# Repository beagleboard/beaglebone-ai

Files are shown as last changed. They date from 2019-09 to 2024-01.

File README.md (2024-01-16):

# BeagleBoard.org BeagleBone AI
_Fast track to Embedded Artificial Intelligence_

[BeagleBone AI](https://www.beagleboard.org/boards/beaglebone-ai) is built on the proven BeagleBoard.org® open source Linux approach, BeagleBone® AI has the form-factor of a miniature single-board computer (SBC) with the power of a full-on industrial computer workhorse. Based on the Texas Instruments AM5729, developers have access to the powerful SoC with the ease of BeagleBone® Black header and mechanical compatibility. BeagleBone® AI makes it easy to explore how artificial intelligence (AI) can be used in everyday life via the TI C66x digital-signal-processor (DSP) cores and embedded-vision-engine (EVE) cores supported through an optimized TIDL machine learning OpenCL API with pre-installed tools. Focused on everyday automation in industrial, commercial and home applications.

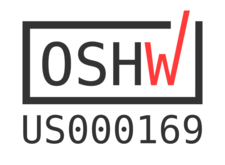
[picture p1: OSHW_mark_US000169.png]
(https://certification.oshwa.org/us000169.html)


# Terms
These design materials are *NOT SUPPORTED* and *DO NOT* constitute a reference design. Only “community” support is allowed via resources at [BeagleBoard.org/discuss](https://beagleboard.org/discuss).

THERE IS NO WARRANTY FOR THE DESIGN MATERIALS, TO THE EXTENT PERMITTED BY APPLICABLE LAW. EXCEPT WHEN OTHERWISE STATED IN WRITING THE COPYRIGHT HOLDERS AND/OR OTHER PARTIES PROVIDE THE DESIGN MATERIALS “AS IS” WITHOUT WARRANTY OF ANY KIND, EITHER EXPRESSED OR IMPLIED, INCLUDING, BUT NOT LIMITED TO, THE IMPLIED WARRANTIES OF MERCHANTABILITY AND FITNESS FOR A PARTICULAR PURPOSE. THE ENTIRE RISK AS TO THE QUALITY AND PERFORMANCE OF THE DESIGN MATERIALS IS WITH YOU. SHOULD THE DESIGN MATERIALS PROVE DEFECTIVE, YOU ASSUME THE COST OF ALL NECESSARY SERVICING, REPAIR OR CORRECTION.

In other words, you may use the design materials as you choose and there is no license with regards to usage in the manufacturing process. We mean it, these design materials may be totally unsuitable for any purposes. Don't blame us!

As a general rule, we don't encourage use of this or other off-the-shelf single board computers in commercial products without engaging with a manufacturer to create a supplier agreement and make sure that you can get material as your business demands. Further, we do update the design on occasions where we find it necessary and won't guarantee a supply of older revisions, though we do seek periodic manufacturing of all of our boards for a period of roughly 10 years and will make design changes to replace obsolete parts and that may impact your usage. If you do opt to use it in a product, you take full responsibility for that product.

Do not use the BeagleBoard.org logo or trademarks (such as BeagleBoard, BeagleBone and PocketBeagle) on your products without a [logo license](https://beagleboard.org/logo) from the BeagleBoard.org Foundation, but feel free to reference BeagleBoard.org.

See the [LICENSE](https://github.com/beagleboard/beaglebone-ai/blob/master/LICENSE) file regarding the copyright of these materials.

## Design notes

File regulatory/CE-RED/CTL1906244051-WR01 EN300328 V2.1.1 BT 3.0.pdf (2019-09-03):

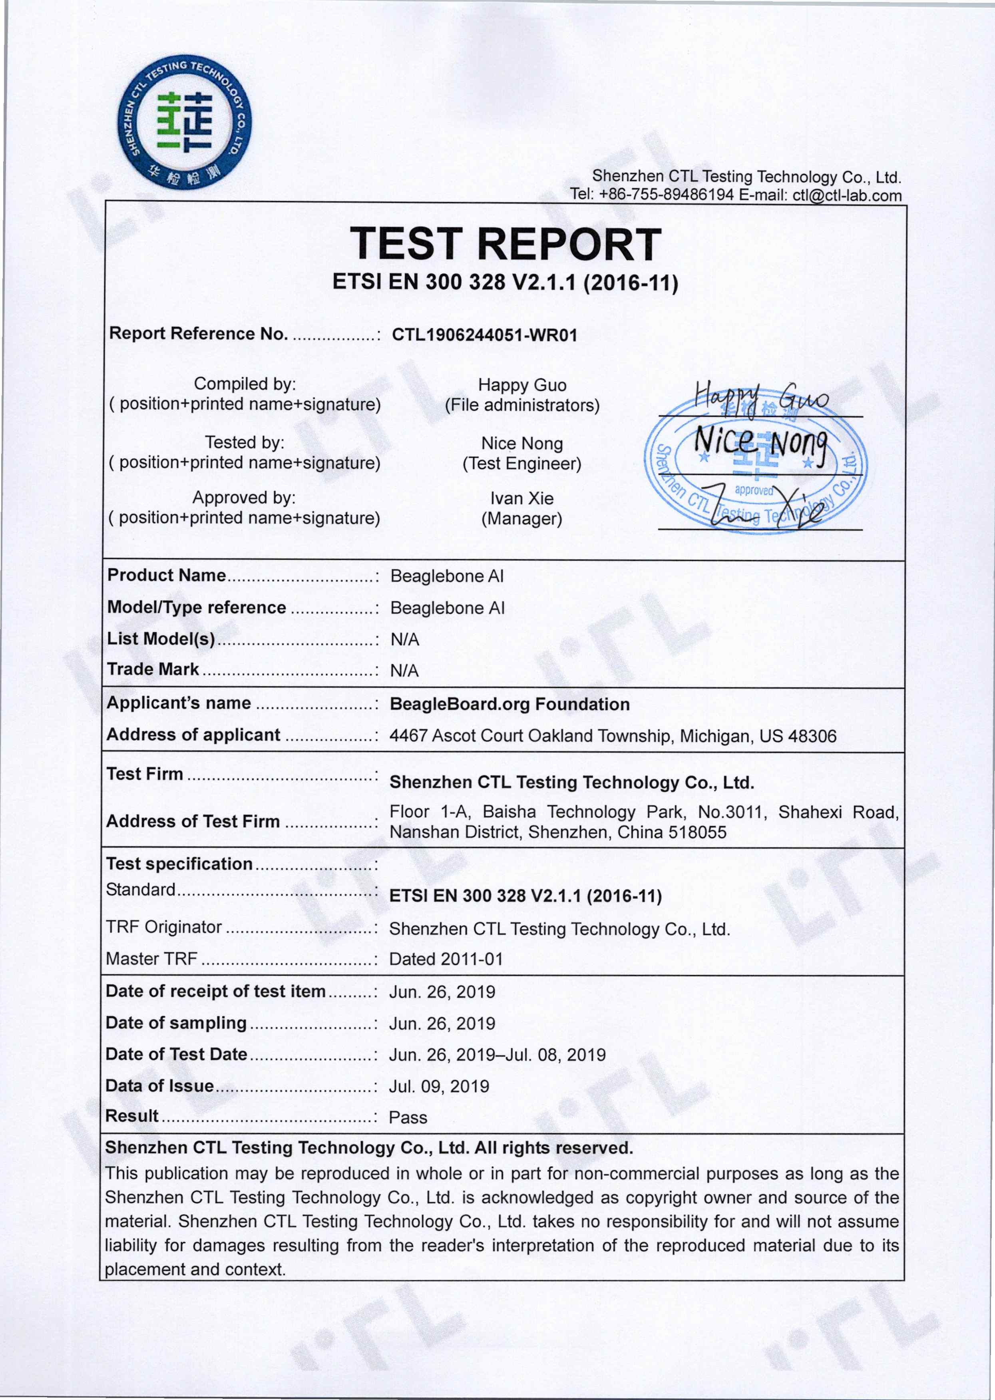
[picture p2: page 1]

V1.0 | Page 2 of 49 | Report No.: CTL1906244051-WR01

# TEST REPORT

Test Report No. : | CTL1906244051-WR01 | Jul. 09, 2019
Date of issue
Equipment under Test | : | Beaglebone AI
Model /Type | : | Beaglebone AI
Listed Models | : | N/A
Applicant | : | BeagleBoard.org Foundation
Address | : | 4467 Ascot Court Oakland Township, Michigan, US
48306
Manufacturer | : | Embest Technology Co., Ltd
Address | : | Tower B 4/F, Shanghai Building, Nanshan Yungu
Innovation Industry Park, Liuxian Ave. No.1183, Taoyuan St., Nanshan District, Shenzhen, Chinas.
Test result | Pass *

* In the configuration tested, the EUT complied with the standards specified page 5.

The test results presented in this report relate only to the object tested.
This report shall not be reproduced, except in full, without the written approval of the issuing testing laboratory.

V1.0 | Page 3 of 49 | Report No.: CTL1906244051-WR01

### ** Modified History **

Revision | Description | Issued Data | Report No. | Remark
Version 1.0 | Initial Test Report Release | 2019-07-08 | CTL1906244051-WR01 | Tracy Qi

V1.0 | Page 4 of 49 | Report No.: CTL1906244051-WR01

## Contents

V1.0 | Page 5 of 49 | Report No.: CTL1906244051-WR01

## 1 TEST SUMMARY

### 1.1 Test Standards

The tests were performed according to following standards:

ETSI EN 300 328 V2.1.1 (2016-11)–Wideband transmission systems; Data transmission equipment operating in the 2,4 GHz ISM band and using wide band modulation techniques; Harmonised Standard covering the essential requirements of article 3.2 of the Directive 2014/53/EU

### 1.2 Test Description

Item | Reference | Result
Maximum transmit power | ETSI EN 300 328 (V2.1.1) Sub-clause 4.3.1.2 | PASS
Duty Cycle, Tx-sequence, Tx-gap | ETSI EN 300 328 (V2.1.1) Sub-clause 4.3.1.3 | N/Anote1
Dwell time, Minimum Frequency Occupation and Hopping Sequence | ETSI EN 300 328 (V2.1.1) Sub-clause 4.3.1.4 | PASS
Hopping Frequency Separation | ETSI EN 300 328 (V2.1.1) Sub-clause 4.3.1.5 | PASS
Medium Utilisation (MU) factor | ETSI EN 300 328 (V2.1.1) Sub-clause 4.3.1.6 | N/Anote1
Adaptively | ETSI EN 300 328 (V2.1.1) Sub-clause 4.3.1.7 | N/Anote2
Occupied Channel Bandwidth | ETSI EN 300 328 (V2.1.1) Sub-clause 4.3.1.8 | PASS
Transmitter unwanted emissions in the out-of-band domain | ETSI EN 300 328 (V2.1.1) Sub-clause 4.3.1.9 | PASS
Transmitter unwanted emissions in the spurious domain | ETSI EN 300 328 (V2.1.1) Sub-clause 4.3.1.10 | PASS
Receiver spurious emissions | ETSI EN 300 328 (V2.1.1) Sub-clause 4.3.1.11 | PASS
Receiver Blocking | ETSI EN 300 328 (V2.1.1) Sub-clause 4.3.1.12 | PASS
Geo-location capability | ETSI EN 300 328 (V2.1.1) Sub-clause 4.3.1.13 | N/Anote3
Note1: This requirement does not apply to adaptive equipment.
Note2: Which is not applicable to device with a maximum RF Output power level is less than 10 dBm e.i.r.p.
Note3: This equipment without geo-location capability function.

V1.0 | Page 6 of 49 | Report No.: CTL1906244051-WR01

### 1.3 Test Facility

### 1.3.1 Address of the test laboratory

Shenzhen CTL Testing Technology Co., Ltd.
Floor 1-A, Baisha Technology Park, No. 3011, Shahexi Road, Nanshan, Shenzhen 518055 China

There is one 3m semi-anechoic chamber and two line conducted labs for final test. The Test Sites meet the requirements in documents ANSI C63.4 and CISPR 32/EN 55032 requirements.

### 1.3.2 Laboratory accreditation

The test facility is recognized, certified, or accredited by the following organizations:
CNAS-Lab Code: L7497
Shenzhen CTL Testing Technology Co., Ltd. has been assessed and proved to be in compliance with CNAS-CL01 Accreditation Criteria for Testing and Calibration Laboratories (identical to ISO/IEC 17025: 2005 General Requirements) for the Competence of Testing and Calibration Laboratories.
A2LA-Lab Cert. No. 4343.01
Shenzhen CTL Testing Technology Co., Ltd. EMC Laboratory has been accredited by A2LA for technical competence in the field of electrical testing, and proved to be in compliance with ISO/IEC 17025: 2005 General Requirements for the Competence of Testing and Calibration Laboratories and any additional program requirements in the identified field of testing.
IC Registration No.: 9518B
CAB identifier: CN0041
The 3m alternate test site of Shenzhen CTL Testing Technology Co., Ltd. EMC Laboratory has been registered by Innovation, Science and Economic Development Canada to test to Canadian radio equipment requirements with Registration No.: 9518B on Jan. 22, 2019.
FCC-Registration No.: 399832
Designation No.: CN1216
Shenzhen CTL Testing Technology Co., Ltd. EMC Laboratory has been registered and fully described in a report filed with the (FCC) Federal Communications Commission. The acceptance letter from the FCC is maintained in our files. Registration 399832, December 08, 2017.

### 1.4 Statement of the measurement uncertainty

The data and results referenced in this document are true and accurate. The reader is cautioned that there may be errors within the calibration limits of the equipment and facilities. The measurement uncertainty was calculated for all measurements listed in this test report acc. to CISPR 16 - 4 „Specification for radio disturbance and immunity measuring apparatus and methods – Part 4: Uncertainty in EMC Measurements“ and is documented in the Shenzhen CTL Testing Technology Co., Ltd. quality system acc. to DIN EN ISO/IEC 17025. Furthermore, component and process variability of devices similar to that tested may result in additional deviation. The manufacturer has the sole responsibility of continued compliance of the device.
Hereafter the best measurement capability for CTL laboratory is reported:
Test Items | Measurement Uncertainty | Notes
Occupied Channel Bandwidth | ±2% | (1)
Transmitter power conducted | 0.57 dB | (1)
Transmitter power Radiated | 2.20 dB | (1)
Conducted spurious emission | 1.60 dB | (1)
Radiated spurious emission | 2.20 dB | (1)
Temperature | ±1℃ | (1)

V1.0 | Page 7 of 49 | Report No.: CTL1906244051-WR01
Humidity | ±3% | (1)
DC and low frequency voltages | ±1.5% | (1)
Time | ±2% | (1)
Duty cycle | ±2% | (1)
Note 1: This uncertainty represents an expanded uncertainty expressed at approximately the 95% confidence level using a coverage factor of k=1.96.

V1.0 | Page 8 of 49 | Report No.: CTL1906244051-WR01

## 2 GENERAL INFORMATION

### 2.1 Environmental conditions

During the measurement the environmental conditions were within the listed ranges:
Temperature | Normal Temperature: | 25°C
| High Temperature: | 55°C
| Low Temperature: | -20°C
Voltage | Normal Voltage | 5.00V
| High Voltage | 5.75V
| Low Voltage | 4.25V
Other | Relative Humidity | 55 %
| Air Pressure | 101 kPa

### 2.2 General Description of EUT

Product Name: | Beaglebone AI
Model/Type reference: | Beaglebone AI
Power supply: | DC 5.0V
Bluetooth
Supported type: | Bluetooth BR/EDR
Modulation: | GFSK, π/4DQPSK, 8DPSK
Operation frequency: | 2402MHz~2480MHz
Channel number: | 79
Channel separation: | 1MHz
Antenna type: | Internal Antenna
Antenna gain: | 1.5dBi
Note: For more detailed features description, please refer to the manufacturer’s specifications or the User's Manual.

### 2.3 Receiver categories

This device belongs to the receiver categories as the choice box selected:
Categorization | Note
Receiver category 1 | Adaptive equipment with a maximum RF output power greater than 10 dBm e.i.r.p.
Receiver category 2 | Non-adaptive equipment with a Medium Utilization (MU) factor greater than 1 % and less than or equal to 10 % or adaptive equipment with a maximum RF output power of 10 dBm e.i.r.p.
Receiver category 3 | Non-adaptive equipment with a maximum Medium Utilization (MU) factor of 1 % or adaptive equipment with a maximum RF output power of 0 dBm e.i.r.p.

V1.0 | Page 9 of 49 | Report No.: CTL1906244051-WR01

### 2.4 Description of Test Modes and Test Frequency

The EUT has been tested under typical operating condition. The Applicant provides communication tools software to control the EUT for staying in continuous transmitting and receiving mode for testing. Operation Frequency List：
Channel | Frequency (MHz)
00 2402
01 | 2403 ... ...
38 | 2440
39 2441
40 | 2442 ... ...
77 | 2479
78 2480
Note: The line display in grey were the channel selected for testing

### 2.5 Measurement Instruments List

RF output power & PSD & OOB & OBW & Hoping & Duty Cycle, Tx-sequence, Tx-gap & Adaptively
Item | Test Equipment | Manufacturer | Model No. | Serial No. | Calibration Date | Calibration Due Date
1 | Spectrum Analyzer | Agilent | N9020 | US46220290 | 2019/05/24 | 2020/05/23
2 | Signal Generator | Agilent | N5182A | MY47420864 | 2019/05/24 | 2020/05/23
3 | Signal Generator | Agilent | E4421B | US40051744 | 2019/05/24 | 2020/05/23
4 | Power Sensor | Agilent | U2021XA | MY5365004 | 2019/05/24 | 2020/05/23
5 | Power Meter | Agilent | U2531A | TW53323507 | 2019/05/24 | 2020/05/23
6 | Climate Chamber | ESPEC | EL-10KA | A20120523 | 2019/05/24 | 2020/05/23

Transmitter spurious emissions & Receiver spurious emissions
Item | Test Equipment | Manufacturer | Model No. | Serial No. | Calibration Date | Calibration Due Date
1 | ULTRA-ROADBA ND ANTENNA | Sunol Sciences Corp. | JB1 | A061713 | 2019/05/24 | 2020/05/23
2 | Horn Antenna | Sunol Sciences Corp. | DRH-118 | A062013 | 2019/05/24 | 2020/05/23
3 | EMI Test Receiver | R&S | ESCI | 103710 | 2019/05/24 | 2020/05/23
4 | Controller | EM Electronics | Controller EM 1000 | N/A | 2019/05/24 | 2020/05/23
5 | Amplifier | Agilent | 8349B | 3008A02306 | 2019/05/24 | 2020/05/23
6 | Amplifier | Agilent | 8447D | 2944A10176 | 2019/05/24 | 2020/05/23
7 | Temperature/Hu midity Meter | Gangxing | CTH-608 | 02 | 2019/05/24 | 2020/05/23
8 | High-Pass Filter | K&L | 9SH10-27 | N/A | 2019/05/24 | 2020/05/23

V1.0 | Page 10 of 49 | Report No.: CTL1906244051-WR01
| | | 00/X1275 0-O/O
9 | High-Pass Filter | K&L | 41H10-13 75/U1275 0-O/O | N/A | 2019/05/24 | 2020/05/23
10 | RF Cable | HUBER+SU HNER | RG214 | N/A | 2019/05/24 | 2020/05/23

The calibration interval is 1 year.

V1.0 | Page 11 of 49 | Report No.: CTL1906244051-WR01

## 3 TEST ITEM AND RESULTS

### 3.1 RF Output Power

Limit

ETSI EN 300 328 (V2.1.1) Sub-clause 4.3.1.2.3
TEST CONDITION | LIMIT
Normal and Extreme | 20dBm(e.i.r.p)

Test Procedure

- Step 1: Use a fast power sensor suitable for 2,4 GHz and capable of minimum 1 MS/s. Use the following settings:
- Sample speed 1 MS/s or faster.
- The samples shall represent the RMS power of the signal.
- Measurement duration: For non-adaptive equipment: equal to the observation period. For adaptive equipment, the measurement duration shall be long enough to ensure a minimum number of bursts (at least 10) are captured.
NOTE 1: For adaptive equipment, to increase the measurement accuracy, a higher number of bursts may be used.
- Step 2:For conducted measurements on devices with one transmit chain:
-Connect the power sensor to the transmit port, sample the transmit signal and store the raw data. Use these stored samples in all following steps.
For conducted measurements on devices with multiple transmit chains:
- Connect one power sensor to each transmit port for a synchronous measurement on all transmits ports.
- Trigger the power sensors so that they start sampling at the same time. Make sure the time difference between the samples of all sensors is less than 500 ns.
- For each individual sampling point (time domain), sum the coincident power samples of all ports and store them. Use these summed samples in all following steps.
- Step 3: Find the start and stop times of each burst in the stored measurement samples.
The start and stop times are defined as the points where the power is at least 30 dB below the highest value of the stored samples in step 2.
NOTE 2: In case of insufficient dynamic range, the value of 30 dB may need to be reduced appropriately.
- Step 4: Between the start and stop times of each individual burst calculate the RMS power over the burst using the formula below. Save these Pburst values, as well as the start and stop times for each burst.

With 'k' being the total number of samples and 'n' the actual sample number
- Step 5: The highest of all Pburst values (value "A" in dBm) will be used for maximum e.i.r.p. calculations.
- Step 6: Add the (stated) antenna assembly gain "G" in dBi of the individual antenna. If applicable, add the additional beamforming gain "Y" in dB using the formula below:
P = A + G + Y

V1.0 | Page 12 of 49 | Report No.: CTL1906244051-WR01

Test Results

GFSK Modulation
Test conditions | Measured power (dBm) | Antenna Gain (dBi) | EIRP (dBm) | Limit
(V) | Temperature (℃ )
5.0V | 25 | 7.67 | 1.50 | 9.17 | 20.00 | Pass
| -20 | 7.42 | 1.50 | 8.92
| +55 | 7.38 | 1.50 | 8.88
(dBm) | Result Voltage

π/4DQPSK Modulation
Test conditions | Measured power (dBm) | Antenna Gain (dBi) | EIRP (dBm) | Limit
(V) | Temperature (℃ )
5.0V | 25 | 3.51 | 1.50 | 5.01 | 20.00 | Pass
| -20 | 3.46 | 1.50 | 4.96
| +55 | 3.57 | 1.50 | 5.07
(dBm) | Result Voltage

8DPSK Modulation
Test conditions | Measured power (dBm) | Antenna Gain (dBi) | EIRP (dBm) | Limit
(V) | Temperature (℃ )
5.0V | 25 | 3.81 | 1.50 | 5.31 | 20.00 | Pass
| -20 | 3.72 | 1.50 | 5.22
| +55 | 3.98 | 1.50 | 5.48
(dBm) | Result Voltage

Note 1. Test performed at worst case at DH5, 2DH5, 3DH5 hoping mode separately.
2. We captured 25 bursts for each mode and recorded the maximum average power.
3. Measured Power includes the cable loss.

V1.0 | Page 13 of 49 | Report No.: CTL1906244051-WR01

### 3.2 Duty Cycle, Tx-sequence, Tx-gap

Limit

ETSI EN 300 328 (V2.1.1) Sub-clause 4.3.1.3.3

1. For non-adaptive FHSS equipment, the Duty Cycle shall be equal to or less than the maximum value declared by the supplier. In addition, the maximum Tx -sequence time shall be 5 ms while the minimum Tx-gap time shall be 5 ms.
2. For equipment using wide band modulations other than FHSS, the Duty Cycle shall be equal to or less than the maximum value declared by the supplier.
The Tx-sequence time shall be equal to or less than 10 ms. The minimum Tx-gap time following a Tx-sequence shall be equal to the duration of that proceeding Tx-sequence with a minimum of 3,5 ms.
Test Procedure

The test procedure, which shall only be performed for non-adaptive systems, shall be as follows:
- Step 1: Use the same stored measurement samples from the procedure described in RF output power measurement
- Step 2: Between the saved start and stop times of each individual burst, calculate the TxOn time. Save these TxOn values.
- Step 3: Al TxOn times between the end of the first gap (which is the start of the first burst within the observation period) and the start of the last burst (within this observation period) divided by the observation period.
- Step 4:
Identify any TxOff time that is equal to or greater than the minimum Tx-gap time. These are the potential valid gap times to be further considered in this procedure.
Starting from the second identified gap, calculate the time from the start of this gap to the end of the preceding ap. This time is the Tx-sequence time for this transmission. Repeat this procedure until the last identified gap ithin the observation period is reached.

Test Results

Not applicable to this device which was adaptive equipment and cannot operate in a non-adaptive mode.

V1.0 | Page 14 of 49 | Report No.: CTL1906244051-WR01

### 3.3 Accumulated Transmit Time, Frequency Occupation and Hopping Sequence

LIMIT

ETSI EN 300 328 (V2.1.1) Sub-clause 4.3.1.4.3.
Limit of Accumulated Transmit Time
TEST CONDITION | LIMIT
Non-adaptive frequency hopping systems | ≥15 ms within 5ms*hopping frequencies (N)
Adaptive frequency hopping systems | ≥0.4s within 0.4s*hopping frequencies (N)
Note: N means minimum number of hopping frequencies (N) that have to be used.

Limit of Minimum Frequency Occupation
TEST CONDITION | LIMIT
Non-adaptive frequency hopping systems Adaptive frequency hopping systems | Option 1: Each hopping frequency of the hopping sequence shall be occupied at least once within a period not exceeding four times the product of the dwell time and the number of hopping frequencies in use. Option 2: The occupation probability for each frequency shall be between ((1 / U) × 25 %) and 77 % where U is the number of hopping frequencies in use.

Hopping Sequence
TEST CONDITION | LIMIT
Non-adaptive frequency hopping systems Adaptive frequency hopping systems | The hopping sequence(s) shall contain at least N hopping frequencies at all times, where N is 15 or 15 divided by the minimum Hopping Frequency Separation in MHz, whichever is the greater. Adaptive Frequency Hopping equipment shall be capable of operating over a minimum of 70 % of the authorized band.

Remark: This test item is not applicable to DSSS/OFDM system device.
Test Procedure
1. The measurement shall be performed on a minimum of 2 hopping frequencies chosen arbitrary from the actual hopping sequence. The results as well as the frequencies on which the test was performed shall be recorded in the test report.
2. The analyzer shall be set as follows:
Centre Frequency: | Equal to the hopping frequency being investigated
Frequency Span: | 0 Hz
RBW: | ~ 50 % of the Occupied Channel Bandwidth
VBW: | ≥ RBW
Detector Mode: | RMS
Sweep time: | 400 ms × Minimum number of hopping frequencies (N)
Number of sweep points: | 30 000
Trace mode: | Clear / Write
Trigger: | Free Run

V1.0 | Page 15 of 49 | Report No.: CTL1906244051-WR01
3. Indentify the data points related to the frequency being investigated by applying a threshold.
4. Count the number of data points identified as resulting from transmissions on the frequency being investigated and multiply this number by the time difference between two consecutive data points.
5. Record this value as Accumulated Transmit Time in test report.
6. Set Sweep time to 4 × Dwell Time × Actual numbers of hopping frequencies in use and repeat 3 and 4 to get Frequency Occupation Time and Number.
7. Make the following changes on the analyzer for Hopping Sequence measurement
Centre Frequency: | Equal to the hopping frequency being investigated
Start Frequency: | 2 400 MHz
Stop Frequency: | 2 483,5 MHz
RBW: | ~ 50 % of the Occupied Channel Bandwidth (single hop)
VBW: | ≥ RBW
Detector Mode: | RMS
Sweep time: | 1 s
Number of sweep points: | 30 000
Trace mode: | Max Hold
Trigger: | Free Run
8. When the trace has completed, indentify the number of hopping frequencies used by the hopping sequence.
9. For adaptive systems, using the lowest and highest -20 dB points from the total spectrum envelope obtained instep 7, it shall be verified whether the system uses 70 % of the authorized band. The result shall be recorded in the test report.
Test Results

Test performed at all modulation type and recorded worst case at DH5, 2DH5, and 3DH5.

V1.0 | Page 16 of 49 | Report No.: CTL1906244051-WR01
- Accumulated Transmit Time
The test period: T= 0.4s*hopping frequencies (N)=0.4*15=6s
Channel | Modulation | Accumulated Transmit Time (ms) | Limit (ms) | Result
CH00 | GFSK | 53.800 | 400 | Pass
| π/4QPSK | 50.800 | 400 | Pass
| 8DPSK | 59.000 | 400 | Pass
CH78 | GFSK | 47.600 | 400 | Pass
| π/4QPSK | 62.600 | 400 | Pass
| 8DPSK | 80.200 | 400 | Pass
- Frequency Occupation
The test period: T= 4 × Dwell Time × Actual number of hopping frequencies=4*3.75*79=1185ms
Channel | Modulation | Frequency occupation times (ms) | Frequency occupation Number (pcs) | Limit (pcs) | Result
CH00 | GFSK | 14.536 | 5 | ≥1 | Pass
| π/4QPSK | 5.807 | 2 | | Pass
| 8DPSK | 11.574 | 4 | | Pass
CH78 | GFSK | 5.846 | 2 | | Pass
| π/4QPSK | 20.303 | 7 | | Pass
| 8DPSK | 5.807 | 2 | | Pass
- Hopping Sequence
Modulation | Number of Hopping Channel | Limit | -20 dB Bandwidth (%) | Limit | Result
GFSK | 79 | ≥15 | 95.49 | 70 % of the band 2400MHz-248 3.5MHz | Pass
π/4QPSK | 79 | | 95.93
8DPSK | 79 | | 95.93

Test plot as follows:

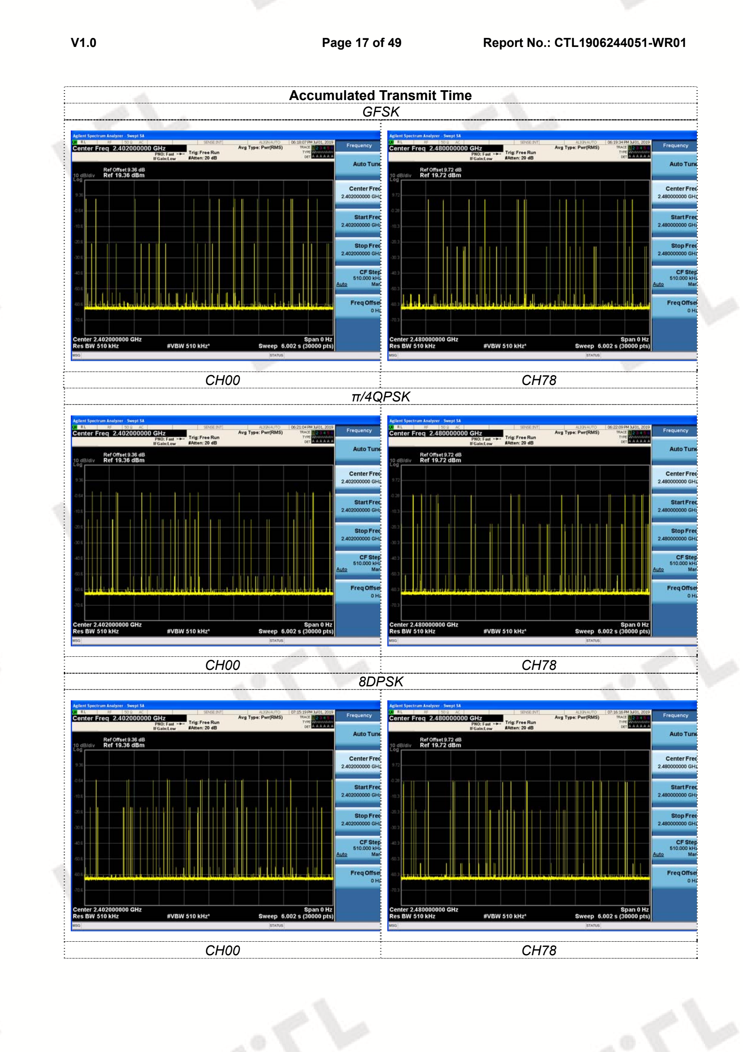
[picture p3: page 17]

V1.0 | Page 17 of 49 | Report No.: CTL1906244051-WR01

Accumulated Transmit Time
GFSK
CH00 | CH78
π/4QPSK
CH00 | CH78
8DPSK
CH00 | CH78

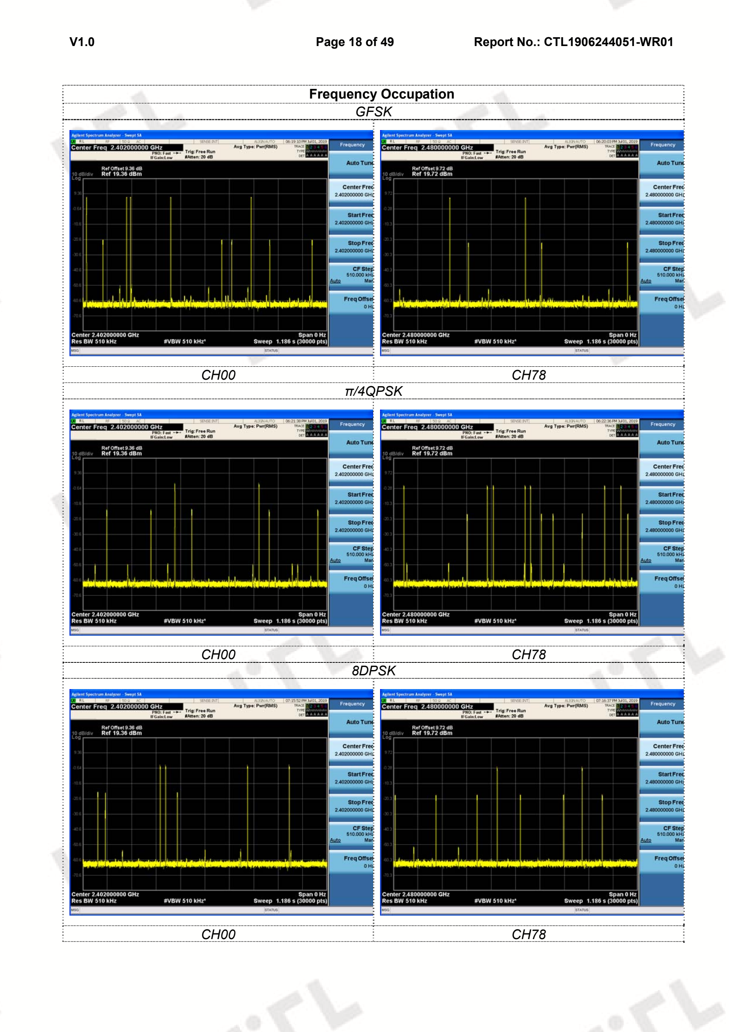
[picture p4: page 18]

V1.0 | Page 18 of 49 | Report No.: CTL1906244051-WR01

Frequency Occupation
GFSK
CH00 | CH78
π/4QPSK
CH00 | CH78
8DPSK
CH00 | CH78

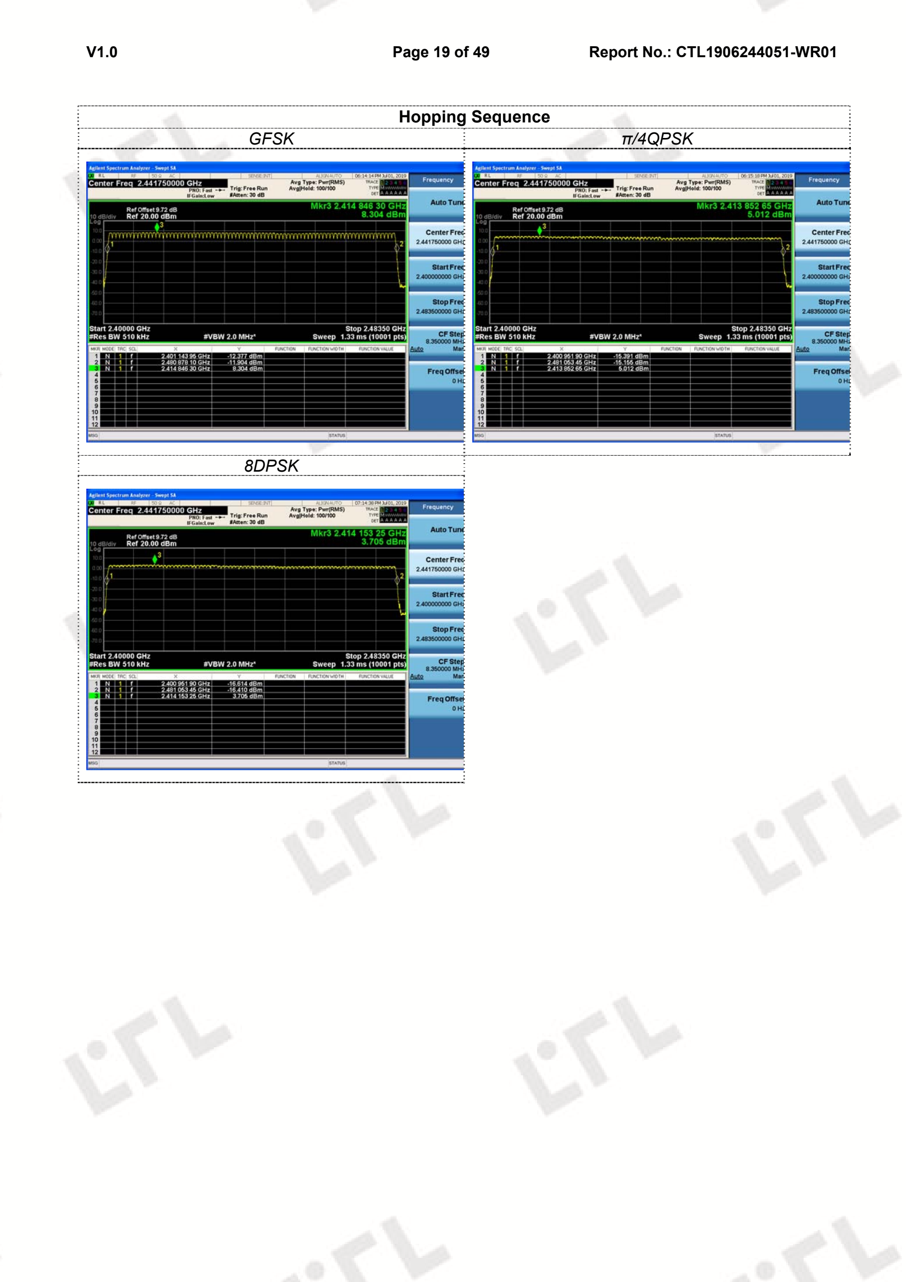
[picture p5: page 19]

V1.0 | Page 19 of 49 | Report No.: CTL1906244051-WR01

Hopping Sequence
GFSK | π/4QPSK

8DPSK

V1.0 | Page 20 of 49 | Report No.: CTL1906244051-WR01

### 3.4 Hopping Frequency Separation

Limit

ETSI EN 300 328 (V2.1.1) Sub-clause 4.3.1.5.3

1. For non-adaptive Frequency Hopping equipment, the Hopping Frequency Separation shall be equal or greater than the Occupied Channel Bandwidth, with a minimum separation of 100 kHz. For equipment with a maximum declared RF Output power level of less than 10 dBm e.i.r.p. or for non-adaptive Frequency Hopping equipment operating in a mode where the RF Output power is less than 10 dBm e.i.r.p. only the minimum Hopping Frequency Separation of 100 kHz applies.
2. For adaptive Frequency Hopping equipment, the minimum Hopping Frequency Separation shall be 100 kHz.
Test Procedure
- Step 1: The output of the transmitter shall be connected to a spectrum analyser
- Step 2: The analyser shall be set as follows:
Centre Frequency: | Centre of the two adjacent hopping frequencies
Span: | Sufficient to see the complete power envelope of both hopping frequencies
Stop Frequency: | 2 483,5 MHz
RBW: | 1 % of the span
VBW: | 3 × RBW
Detector Mode: | RMS
Sweep time: | 1 s
Trace mode: | Max Hold
- Step 3: Wait for the trace to stabilize. Use the marker-delta function to determine the Hopping Frequency Separation between the centres of the two adjacent hopping frequencies (e.g. by indentifying peaks or notches at the centre of the power envelope for the two adjacent signals).

Test Results

Modulation | Channel | Channel Separation (MHz) | Limit(kHz) | Result
GFSK | CH39 | 1.042 | ≥100 | Pass
CH40

π/4QPSK

CH39
1.278 | ≥100 | Pass
CH40

8DPSK

CH39
0.998 | ≥100 | Pass
CH40
Note:
We have tested all mode at high, middle and low channel, and recorded worst case at middle

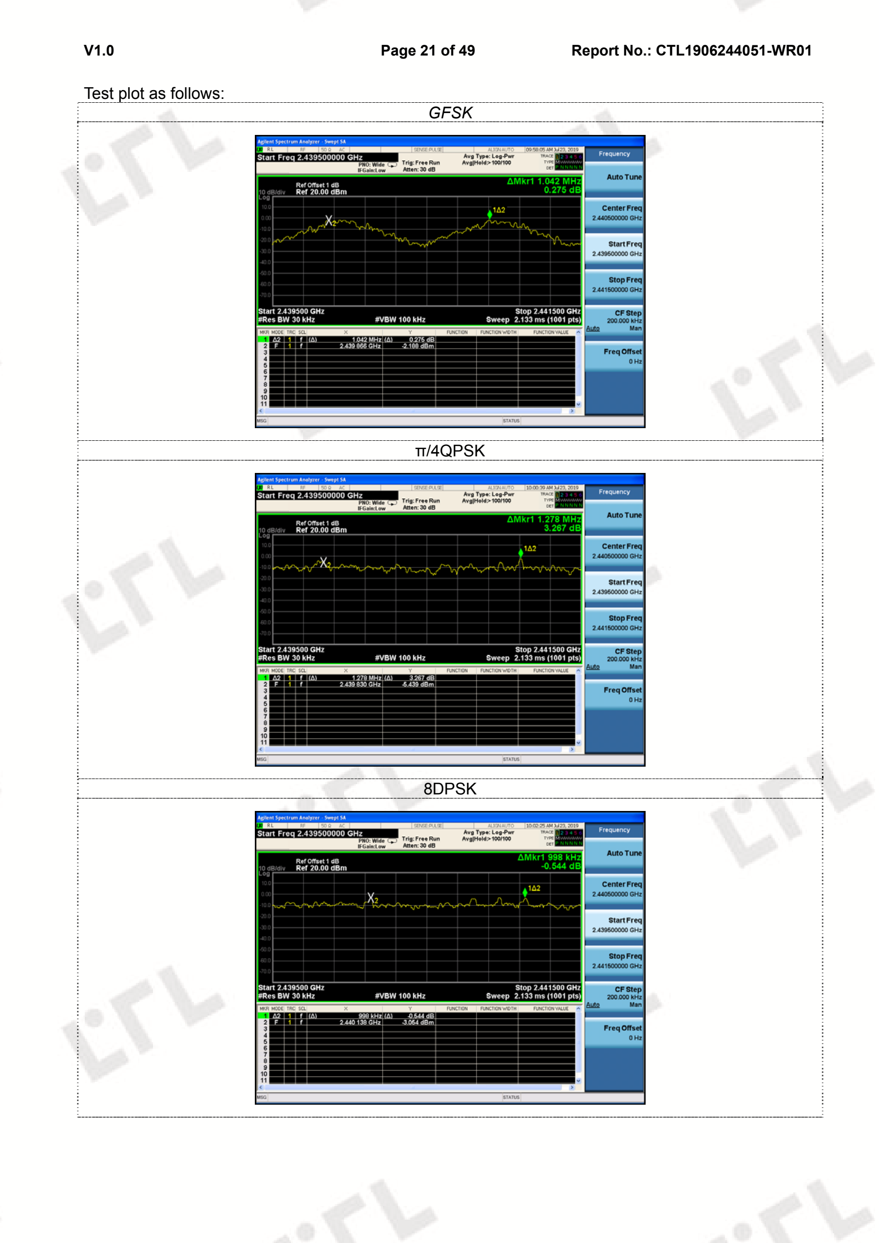
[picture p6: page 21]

V1.0 | Page 21 of 49 | Report No.: CTL1906244051-WR01

Test plot as follows:
GFSK

π/4QPSK

8DPSK

V1.0 | Page 22 of 49 | Report No.: CTL1906244051-WR01

### 3.5 Medium Utilisation (MU) factor

Limit

ETSI EN 300 328 (V2.1.1) Sub-clause 4.3.1.6.3
The maximum Medium Utilisation factor for non-adaptive equipment shall be 10 %.
Definition

The Medium Utilisation (MU) factor is a measure to quantify the amount of resources (Power and Time) used by non-adaptive equipment. The Medium Utilisation factor is defined by the formula:
MU = (P/100 mW) × DC
Where: MU is Medium Utilisation factor in %.
P is the RF output power expressed in mW.
DC is the Duty Cycle expressed in %.
NOTE: The equipment may have dynamic behaviour with regard to duty cycle and corresponding power level.

Test Results

Not applicable to this device which cannot operation in a non-adaptive mode.

V1.0 | Page 23 of 49 | Report No.: CTL1906244051-WR01

### 3.6 Occupied Channel Bandwidth

Limit

ETSI EN 300 328 (V2.1.1) Sub-clause 4.3.1.8.3
The Occupied Channel Bandwidth for each hopping frequency shall fall completely within the band 2.4GHz-2.4835GHz.
Test Procedure
1. The measurement shall be performed only on the lowest and the highest frequency within stated frequency range
2. The test procedure shall be follows:
Step1: Connect the UUT to the spectrum analyzer and use the following settings
Centre Frequency: | The centre frequency of the channel under test
Resolution BW: | ~ 1% of the span without going below 1 %
Video BW: | 3 × RBW
Frequency Span: | 2 × Occupied Channel Bandwidth (e.g. 40 MHz for a 20 MHz channel)
Detector Mode: | RMS
Trace Mode: | MaxHold
Sweep time: | 1s
Step 2: Wait until the trace is completed. Find the peak value of the trace and place the analyzer marker on this peak.
Step 3: Use the 99 % bandwidth function of the spectrum analyzer to measure the Occupied Channel Bandwidth of the EUT.
Test Result
Mode | Channel | Occupied Channel Bandwidth (MHz) | fL (MHz) | fH (MHz) | Limit | Result
GFSK | CH00 | 0.90584 | 2401.528 | 2480.443 | fL≧2.4GHz and fH≦ 2.4835GHz | Pass
| CH78 | 0.90647
π/4QPSK | CH00 | 1.2264 | 2401.375 | 2480.608
| CH78 | 1.2260
8DPSK | CH00 | 1.2294 | 2401.373 | 2480.610
| CH78 | 1.2272

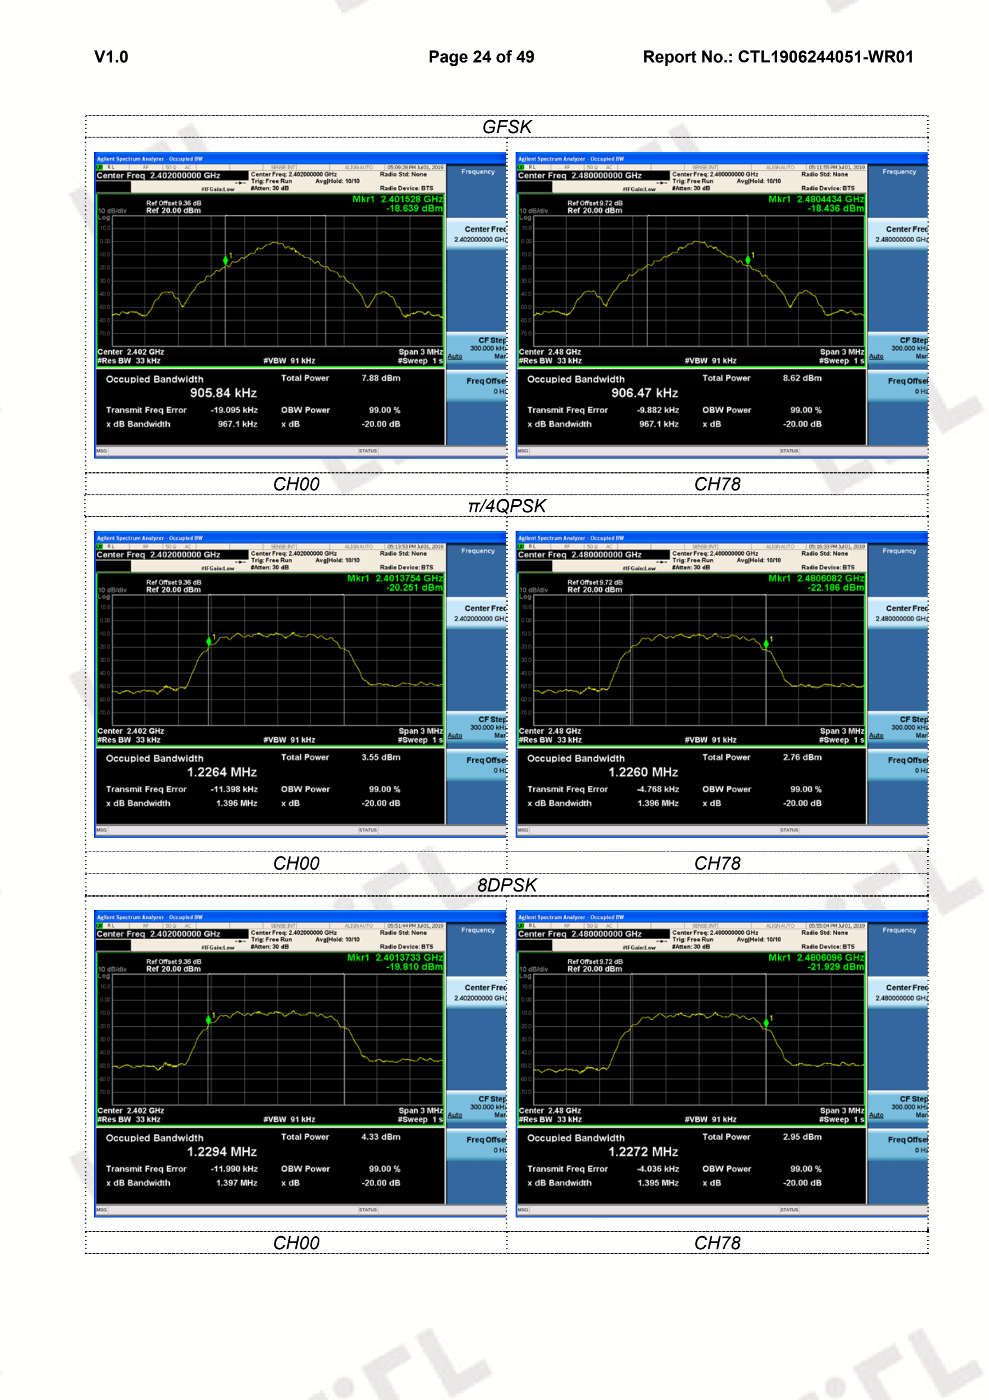
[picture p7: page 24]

V1.0 | Page 24 of 49 | Report No.: CTL1906244051-WR01

GFSK

CH00 | CH78
π/4QPSK
CH00 | CH78
8DPSK
CH00 | CH78

V1.0 | Page 25 of 49 | Report No.: CTL1906244051-WR01

### 3.7 Transmitter unwanted emissions in the out-of-band domain

Limit

ETSI EN 300 328 (V2.1.1) Sub-clause 4.3.1.9.3

The transmitter unwanted emissions in the out-of-band domain but outside the allocated band, shall not exceed the values provided by the mask in figure 1.

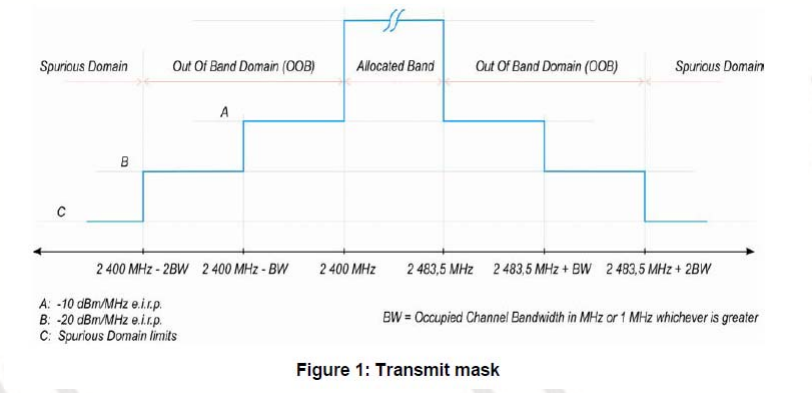
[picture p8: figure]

Test Procedure

1. The measurements shall be performed at both normal environmental conditions and at the extremes of the operating temperature range.
2. For conducted measurements on devices with multiple transmit chains using the results for each of the transmit chains for the corresponding 1MHz segments shall be added and compared with the transmit mask limit.
3. The analyzer shall be set as follows:
Centre Frequency: | Center of each segments
Frequency Span: | 0 Hz
RBW: | 1M
VBW: | 3M
Filter mode: | Channel filter
Trace Mode: | Clear / Write
Detector Mode: | RMS
Number of sweep points: | 5 000
Sweep mode: | Continuous
Trigger: | Video trigger
Sweep Time: | > 120 % of the duration of the longest burst detected
4. Save the value measured of each segments.

V1.0 | Page 26 of 49 | Report No.: CTL1906244051-WR01

Test Result

Remark: The datum recorded below represents the worst emission level in each segment and the plot for normal condition.
GFSK CH00

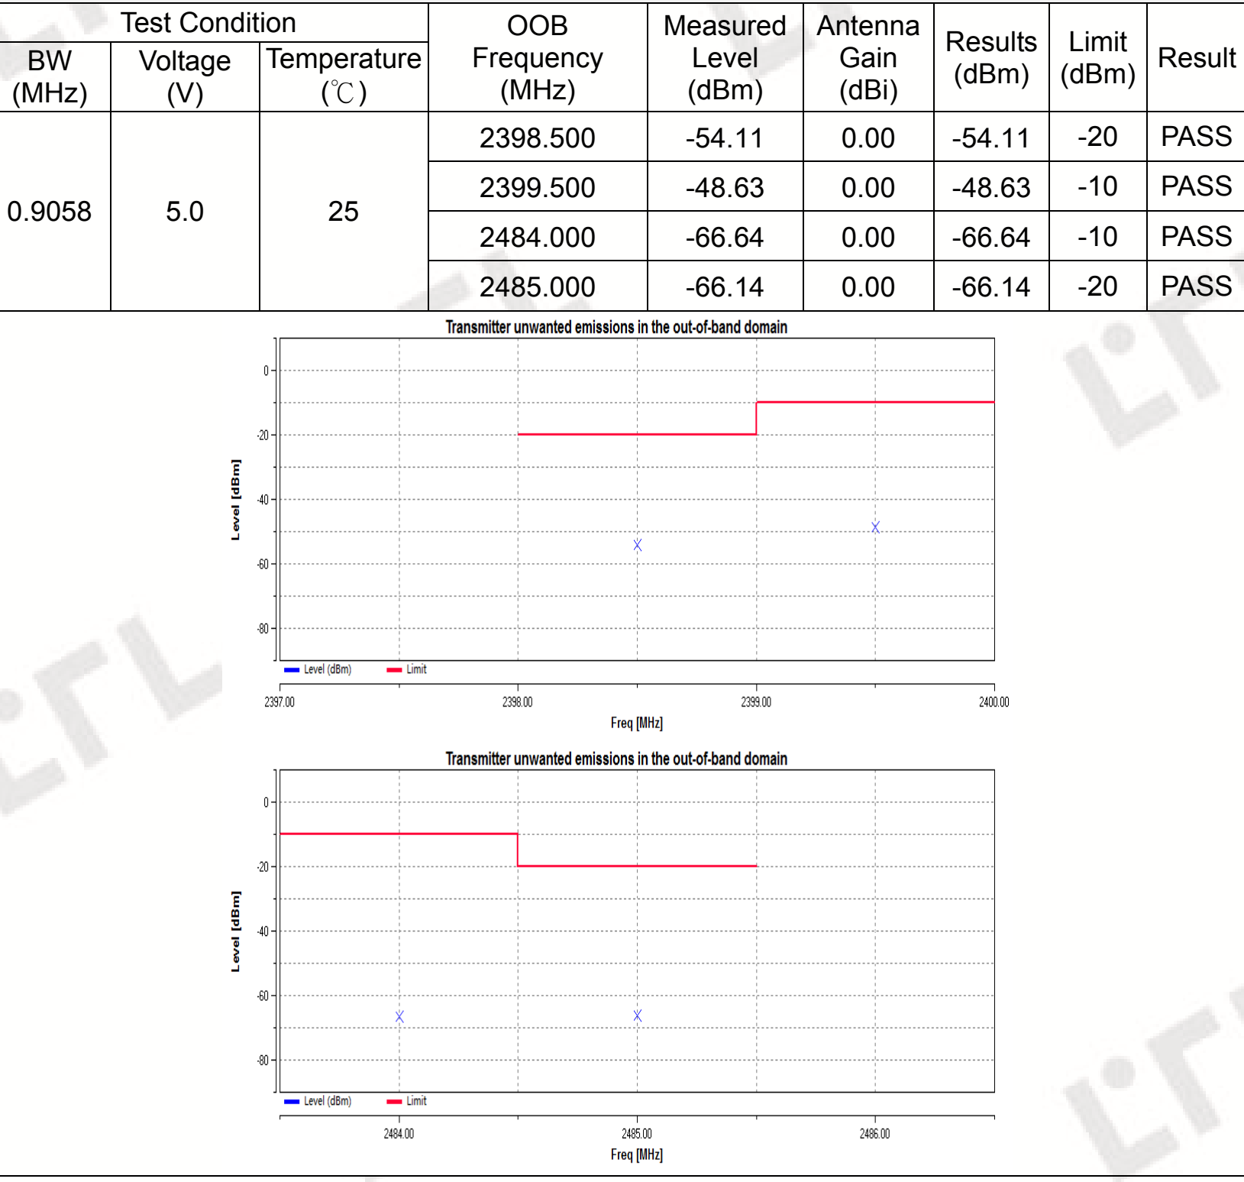
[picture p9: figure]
Test Condition; OOB Frequency (MHz); Measured Level (dBm); Antenna Gain (dBi); Results (dBm); Limit; (dBm) BW; Result; (MHz); Voltage (V); Temperature (℃); PASS

V1.0 | Page 27 of 49 | Report No.: CTL1906244051-WR01

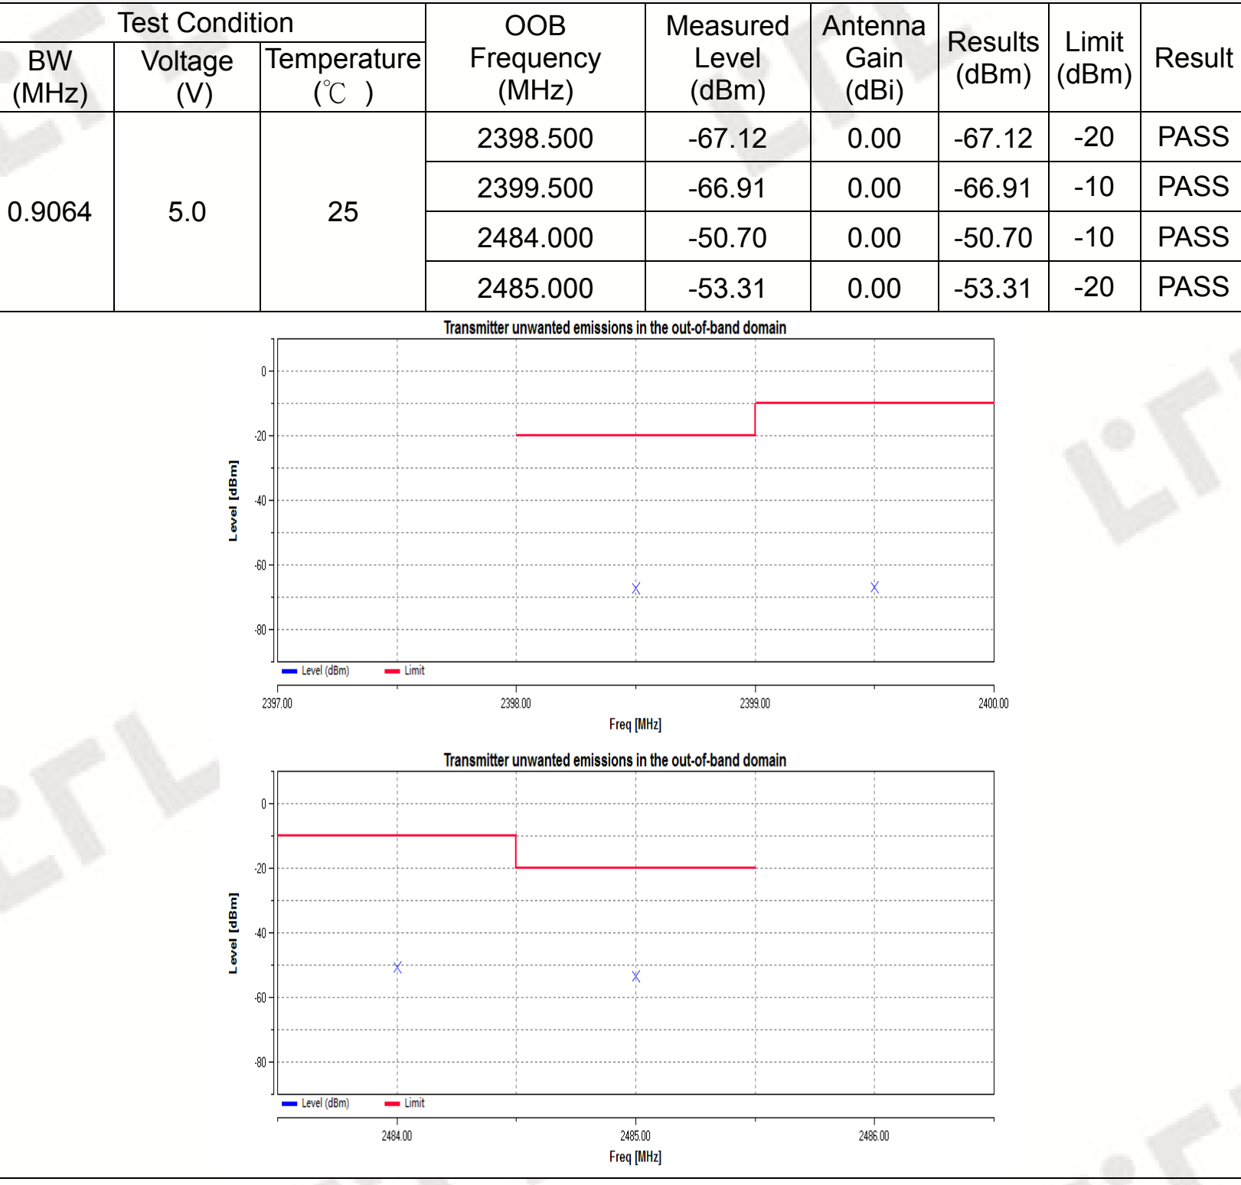
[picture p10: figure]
Test Condition; OOB Frequency (MHz); Measured Level (dBm); Antenna Gain (dBi); Results (dBm); Limit; (dBm) BW; Result; (MHz); Voltage (V); Temperature (℃ ); PASS

GFSK CH78

V1.0 | Page 28 of 49 | Report No.: CTL1906244051-WR01

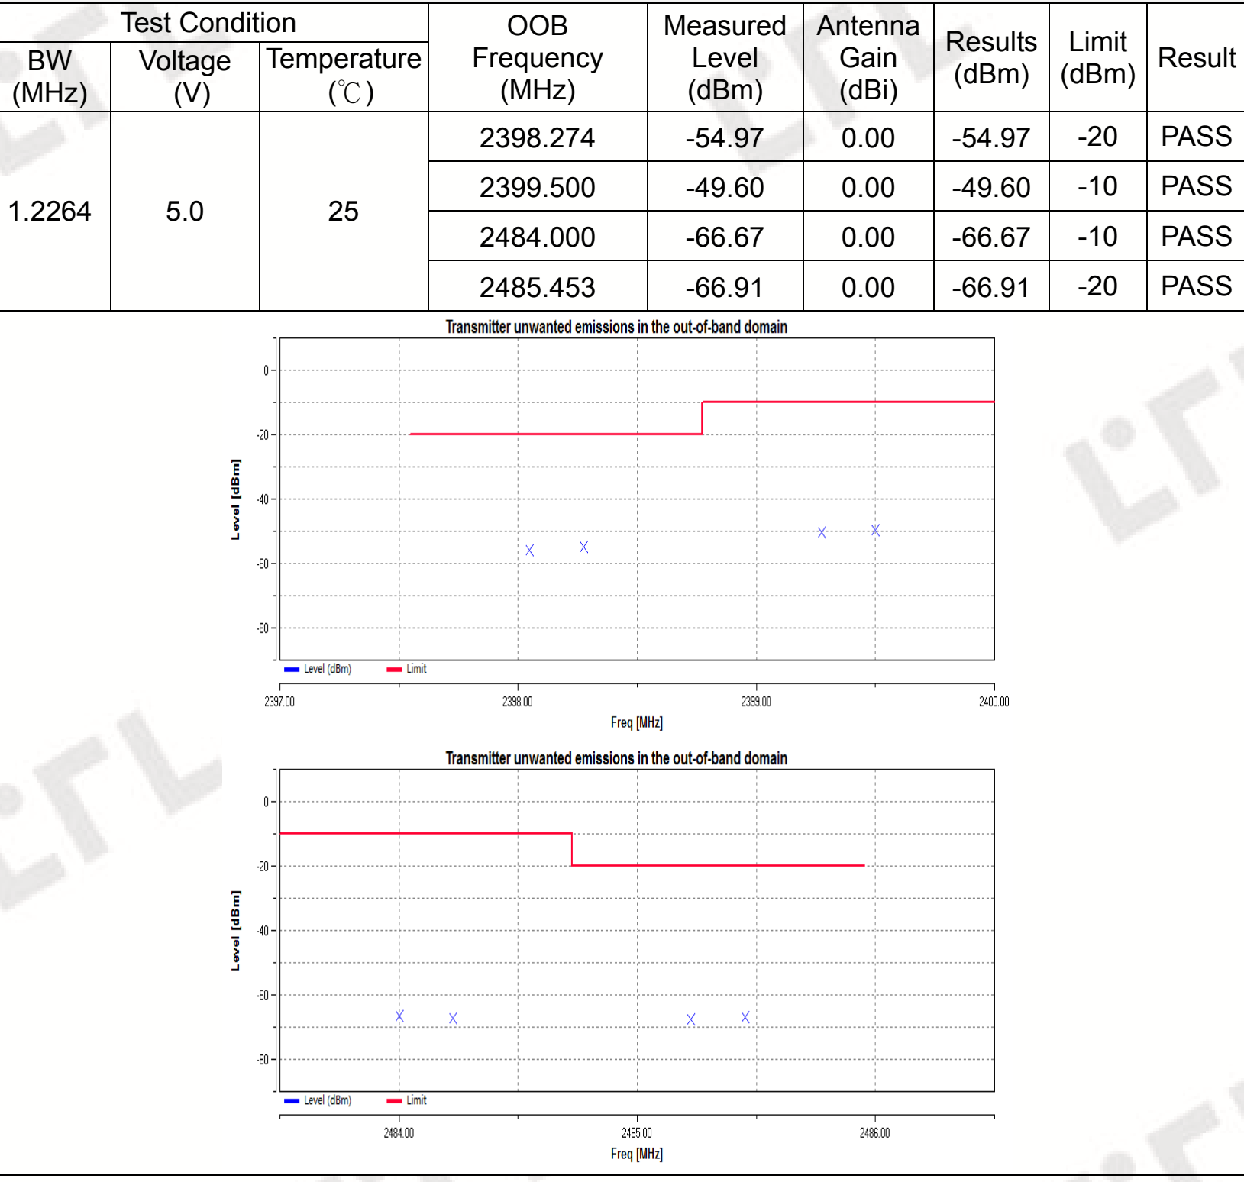
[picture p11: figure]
Test Condition; OOB Frequency (MHz); Measured Level (dBm); Antenna Gain (dBi); Results (dBm); Limit; (dBm) BW; Result; (MHz); Voltage (V); Temperature (℃); PASS

π/4QPSK CH00

V1.0 | Page 29 of 49 | Report No.: CTL1906244051-WR01

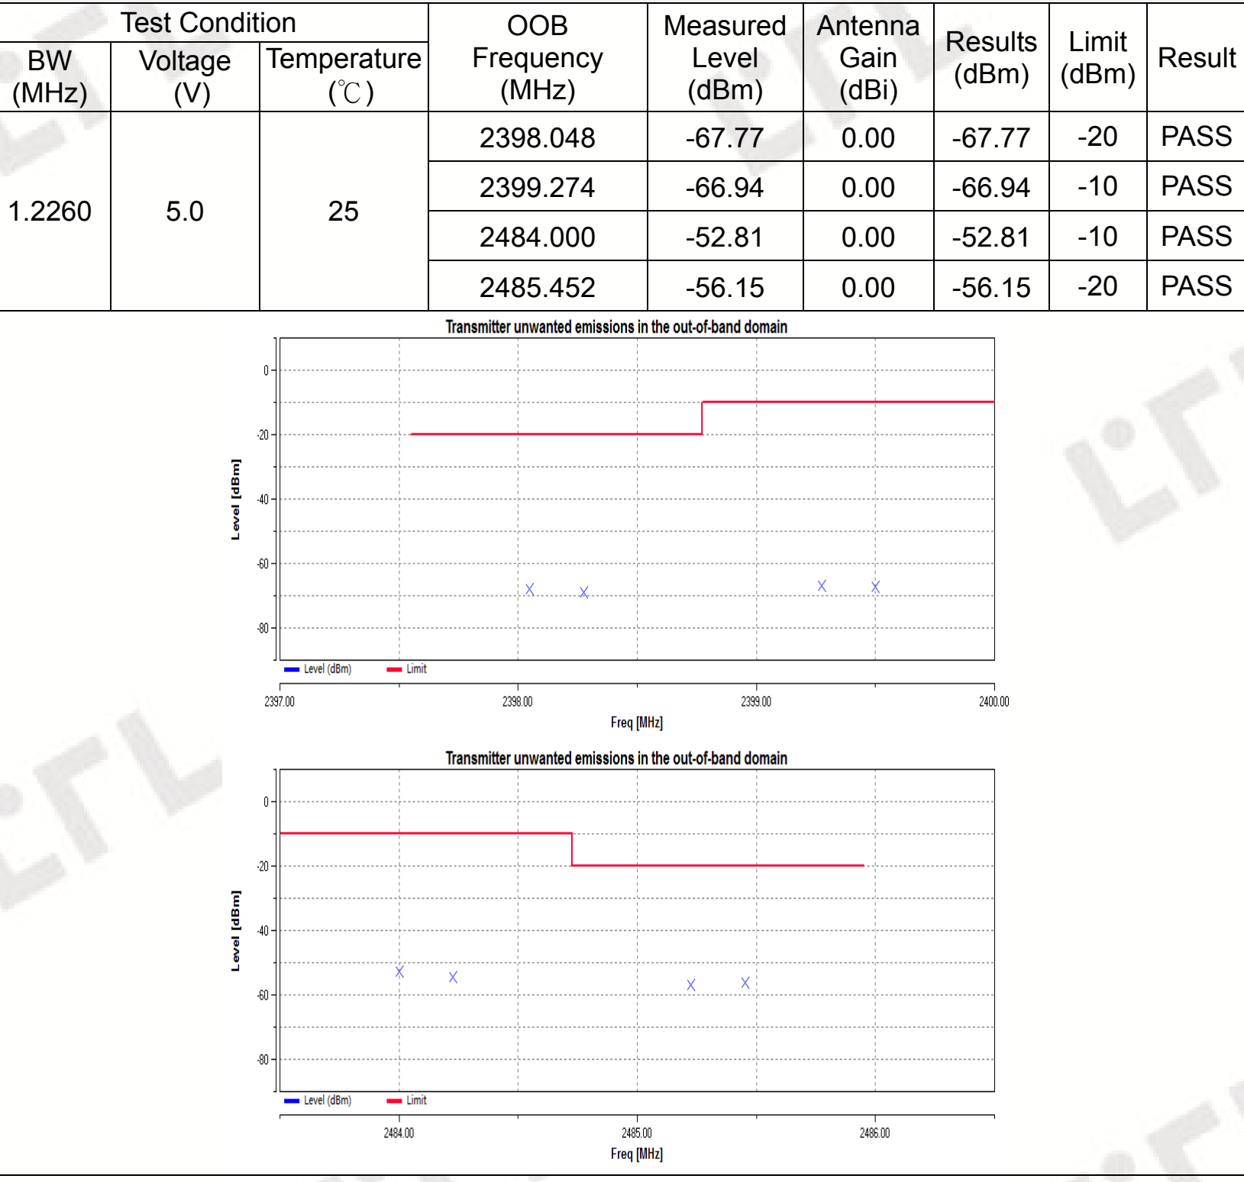
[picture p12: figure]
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

π/4QPSK CH78

V1.0 | Page 30 of 49 | Report No.: CTL1906244051-WR01

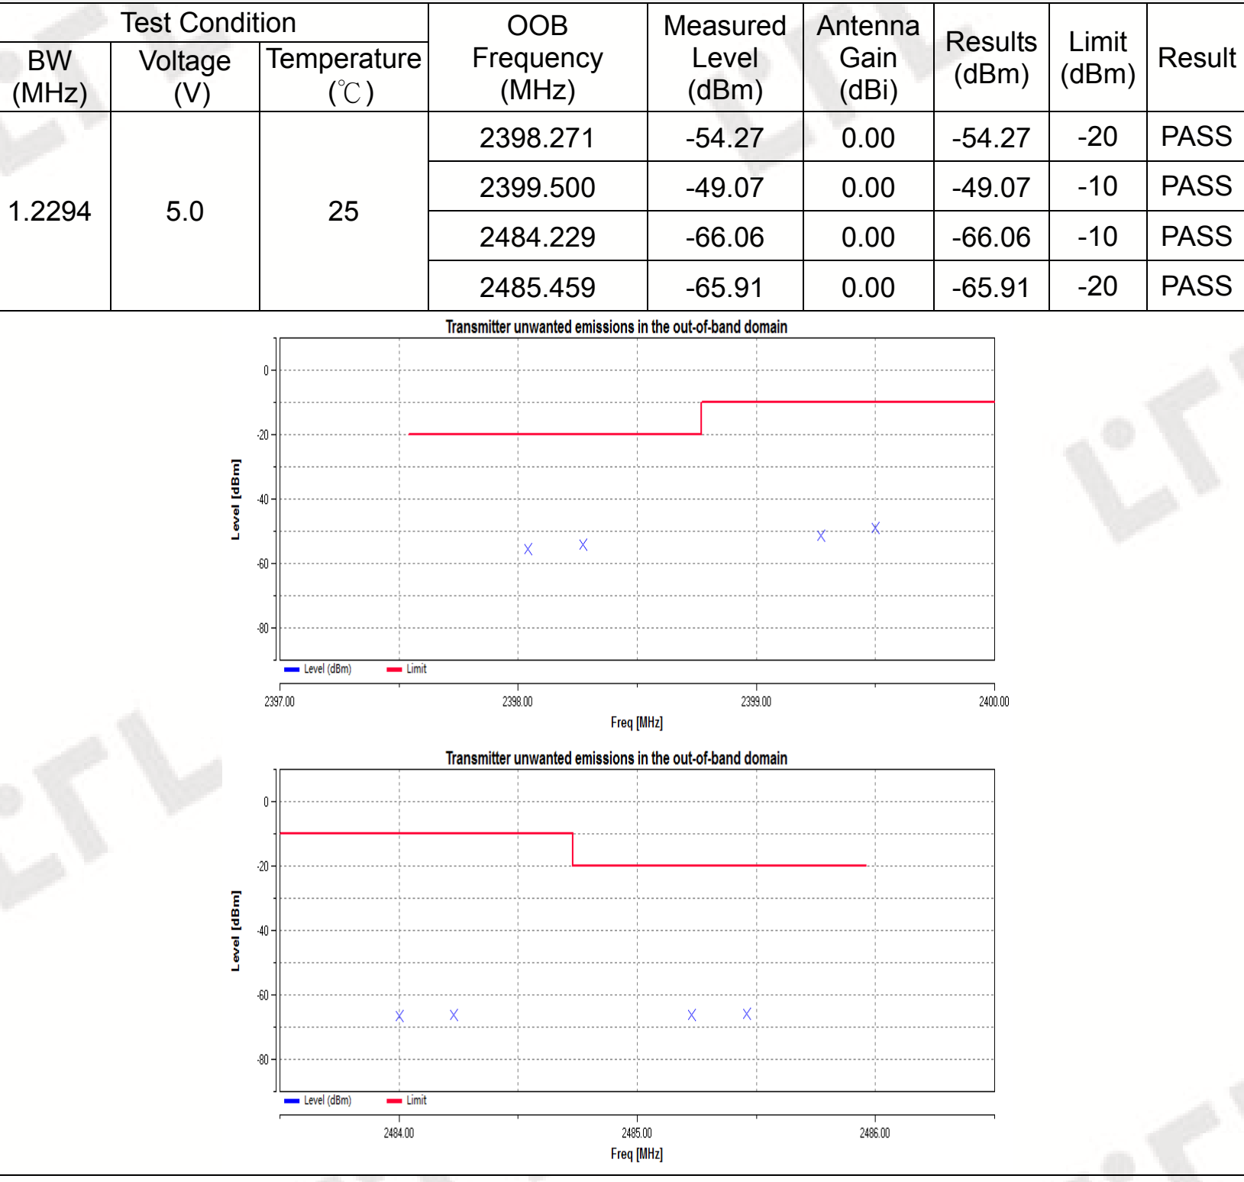
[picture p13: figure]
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

8DPSK CH00

V1.0 | Page 31 of 49 | Report No.: CTL1906244051-WR01

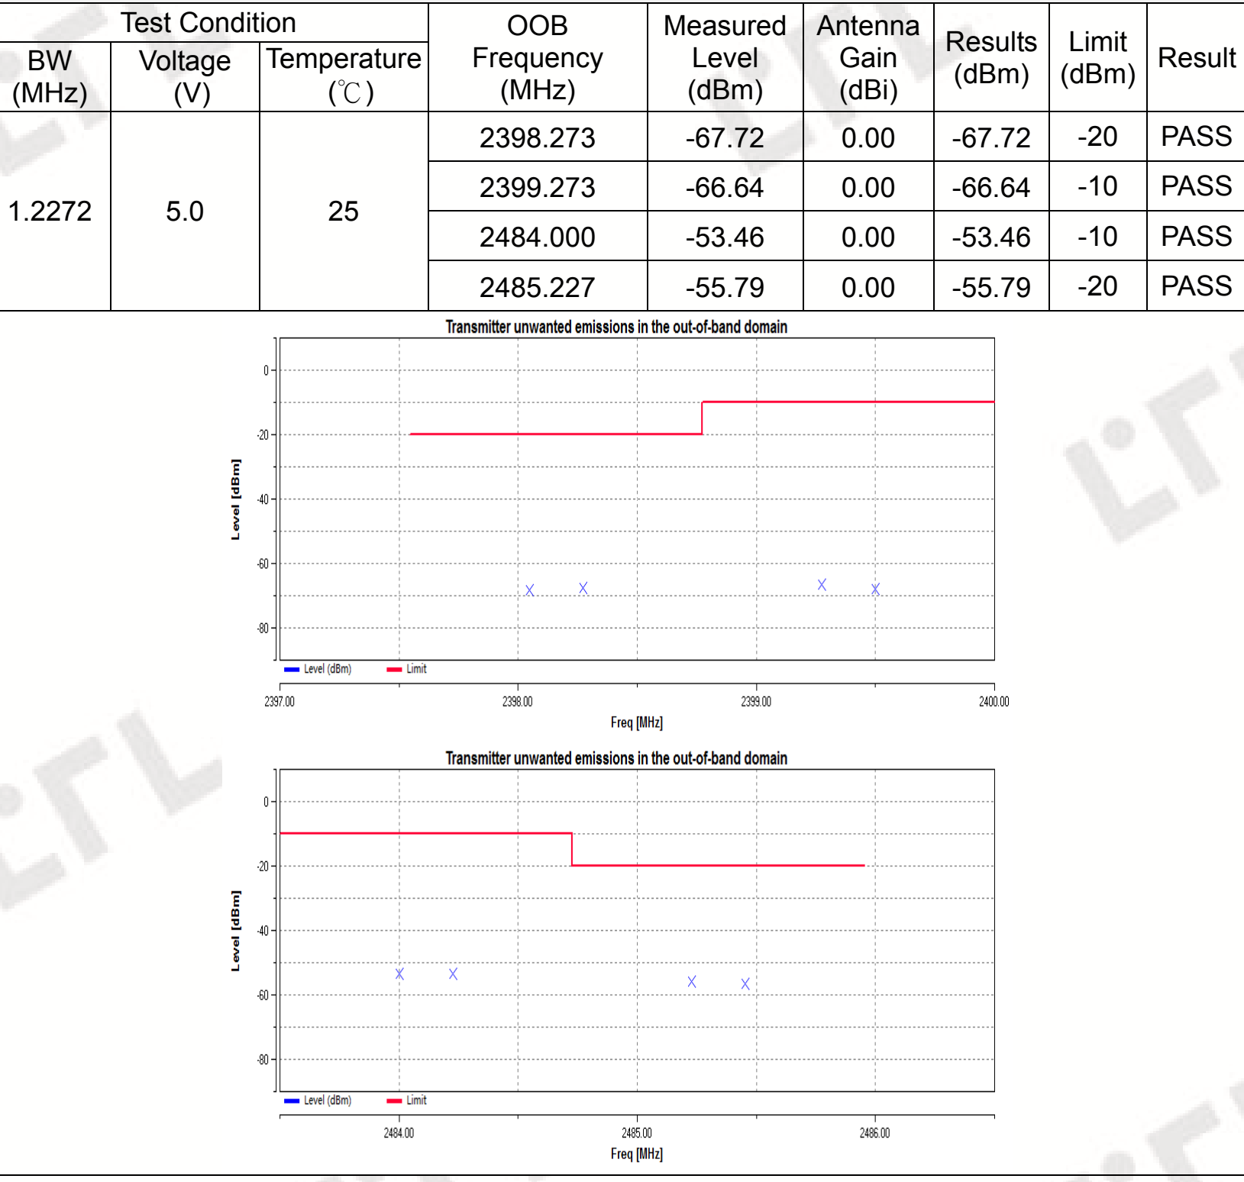
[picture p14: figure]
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

8DPSK CH78

V1.0 | Page 32 of 49 | Report No.: CTL1906244051-WR01

### 3.8 Transmitter unwanted emissions in the spurious domain

Limit

ETSI EN 300 328 (V2.1.1) Sub-clause 4.3.1.10.3

The transmitter unwanted emissions in the spurious domain shall not exceed the values given in table

Table 1: Transmitter limits for spurious emissions
Frequency Range | Maximum power e.r.p.(.≤1 GHz) e.i.r.p.(＞1 GHz) | Bandwidth
30 MHz to 47 MHz | -36 dBm | 100 KHz
47 MHz to 74 MHz | -54 dBm | 100 KHz
74MHz to 87.5 MHz | -36 dBm | 100 KHz
87.5 MHz to 118 MHz | -54 dBm | 100 KHz
118 MHz to 174 MHz | -36 dBm | 100 KHz
174 MHz to 230 MHz | -54 dBm | 100 KHz
230 MHz to 470 MHz | -36 dBm | 100 KHz
470 MHz to 862 MHz | -54 dBm | 100 KHz
862 MHz to 1 GHz | -36 dBm | 100 KHz
1 GHz to 12.75 GHz | -30 dBm | 1 MHz

Test Procedure

1. The measurement performed at the lowest and the highest channel on which the equipment can operate.
2. The EUT was placed on a turntable with 1.5m height.
3. The test distance between the receiving antenna and the EUT is 3 meter, while the receiving (test) antenna is kept at 1.5 meter height.
4. Set EUT in continuous transmitting with maximum output power.
5. The table was rotated from 0 to 360 degree to search the highest radiated emission.
6. Repeat step 3 to 5 for each polarization and channel to find the worst emission level.
7. The results obtained are compared to the limits in order to prove compliance with the requirement.

V1.0 | Page 33 of 49 | Report No.: CTL1906244051-WR01

Test Configuration

Effective Radiated Power measurement (30 MHz to 12.75 GHz)

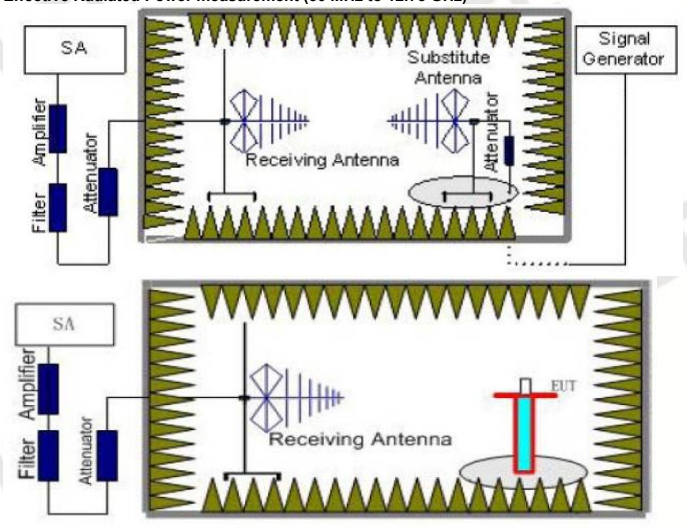
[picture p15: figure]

Test Results

Remark: We test all modulation type, and recorded the worst case at GFSK DH5 mode.

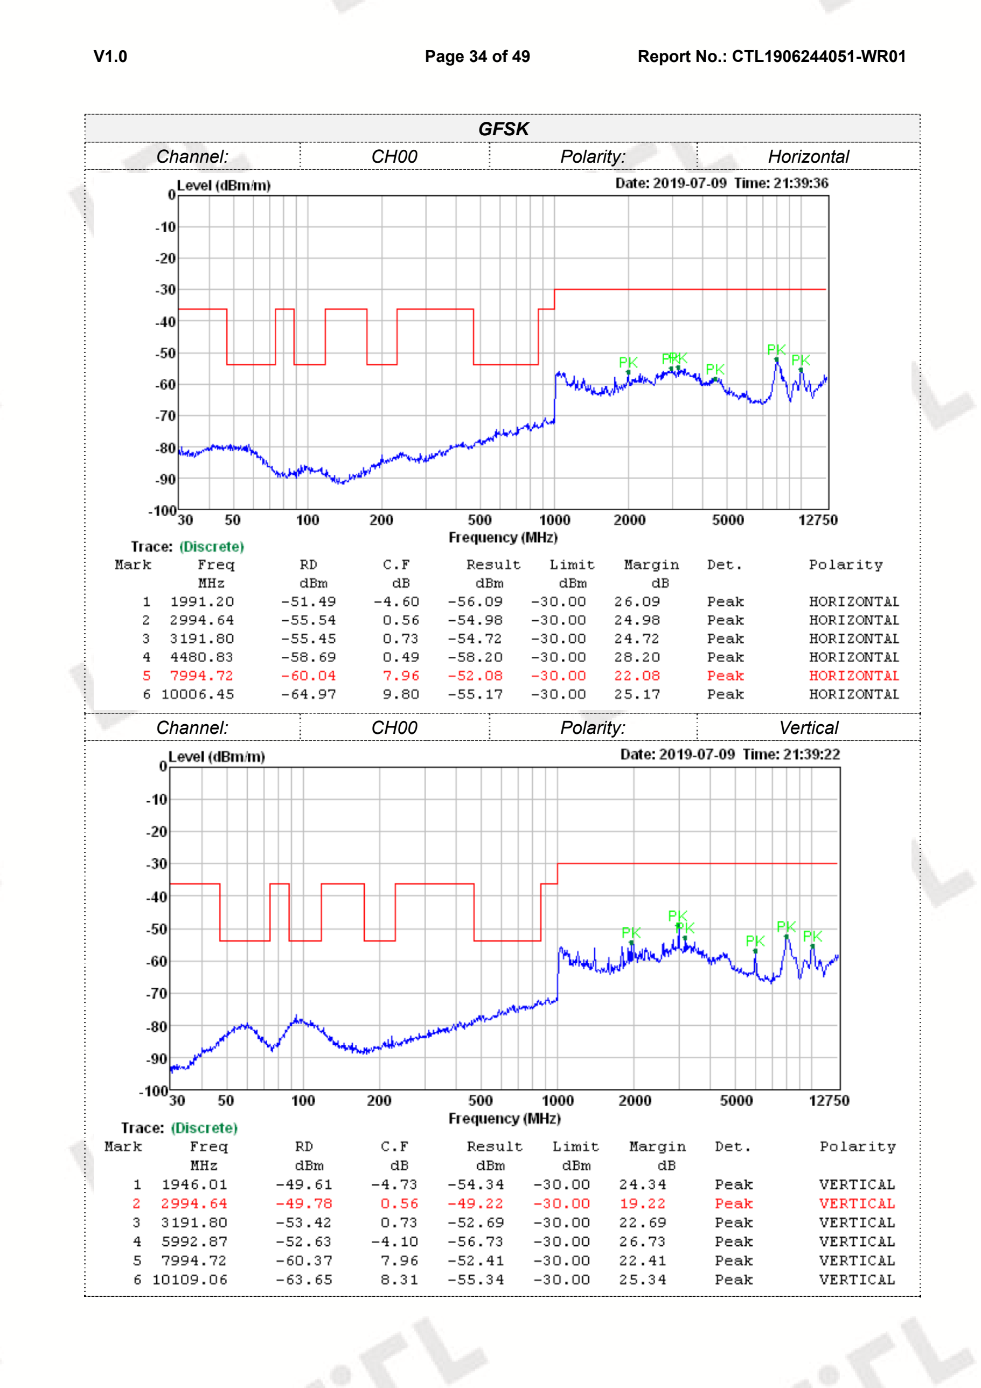
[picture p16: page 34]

V1.0 | Page 34 of 49 | Report No.: CTL1906244051-WR01

GFSK
Channel: | CH00 | Polarity: | Horizontal
Channel: | CH00 | Polarity: | Vertical

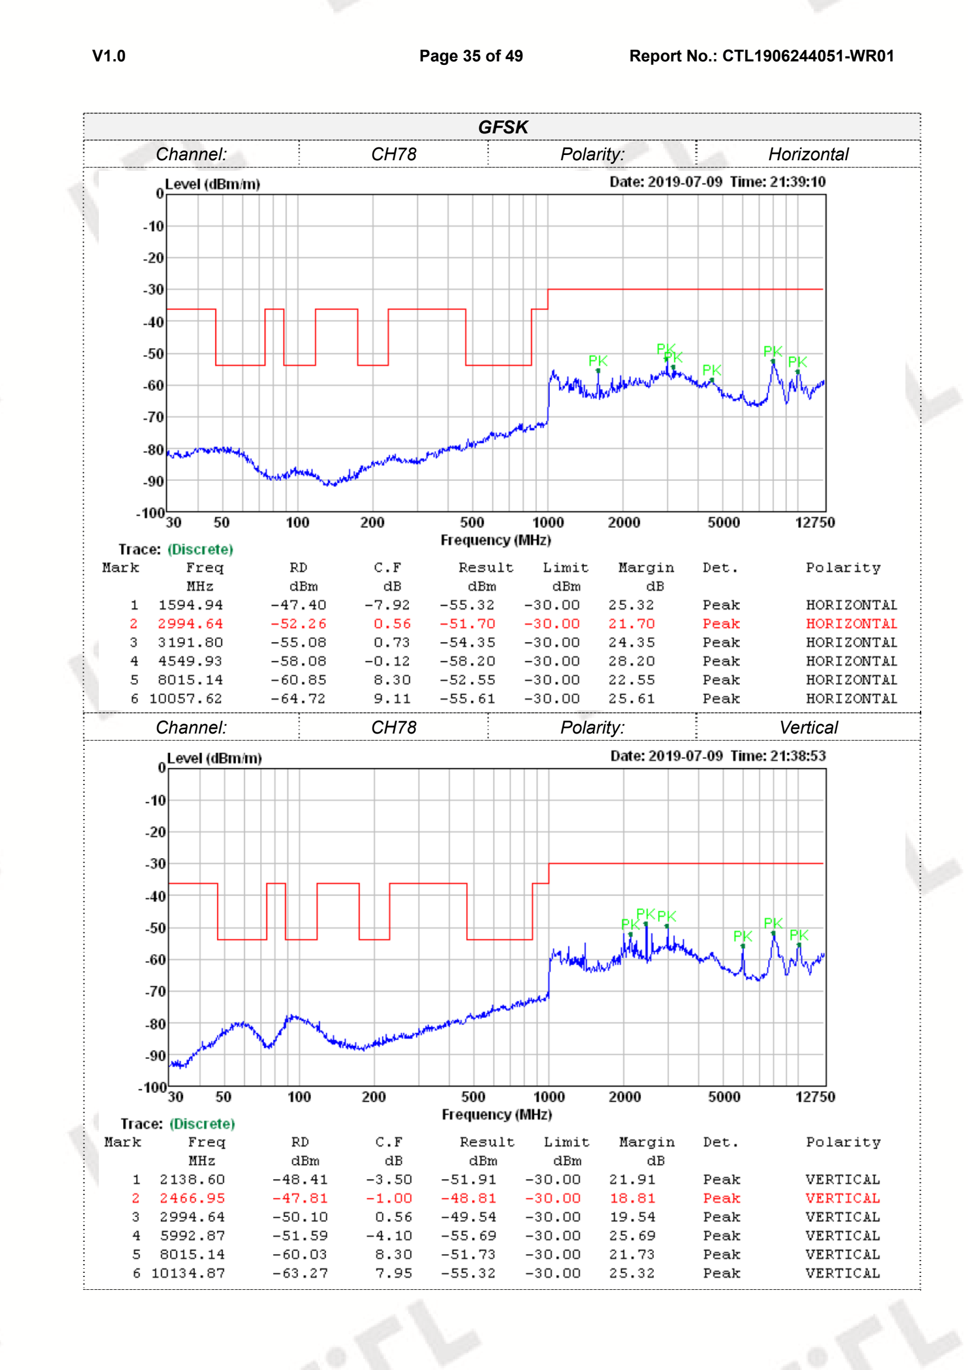
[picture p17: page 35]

V1.0 | Page 35 of 49 | Report No.: CTL1906244051-WR01

GFSK
Channel: | CH78 | Polarity: | Horizontal
Channel: | CH78 | Polarity: | Vertical

V1.0 | Page 36 of 49 | Report No.: CTL1906244051-WR01

### 3.9 Receiver spurious emissions

LIMIT

ETSI EN 300 328 (V2.1.1) Sub-clause 4.3.1.11.3
The spurious emissions of the receiver shall not exceed the values given below:

Spurious emission limits for receivers
Frequency | Maximum power, e.r.p. | Measurement bandwidth
30 MHz to 1 GHz | -57 dBm | 100 KHz
30 MHz to 12.75 GHz | -47 dBm | 1 MHz

Test Procedure
The same as clause 3.8
Test Configuration

Effective Radiated Power measurement (30 MHz to 12.75 GHz)

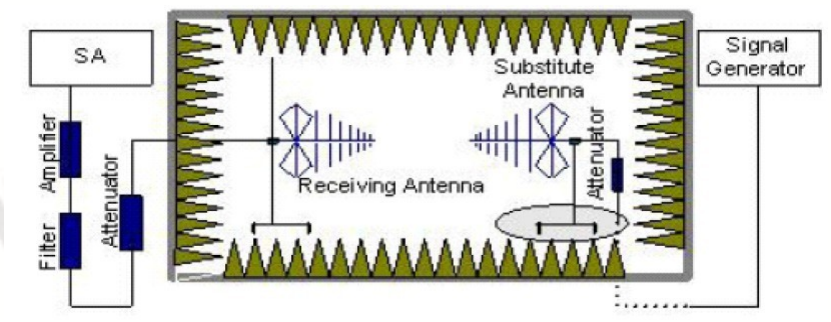
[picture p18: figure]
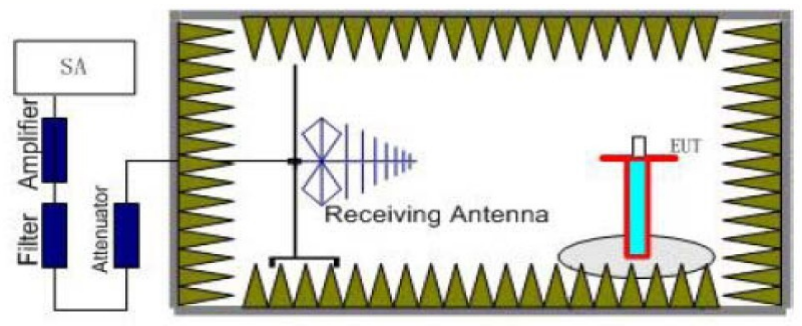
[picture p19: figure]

Test Results

Remark: We test all modulation type, and recorded the worst case at GFSK DH5 mode.

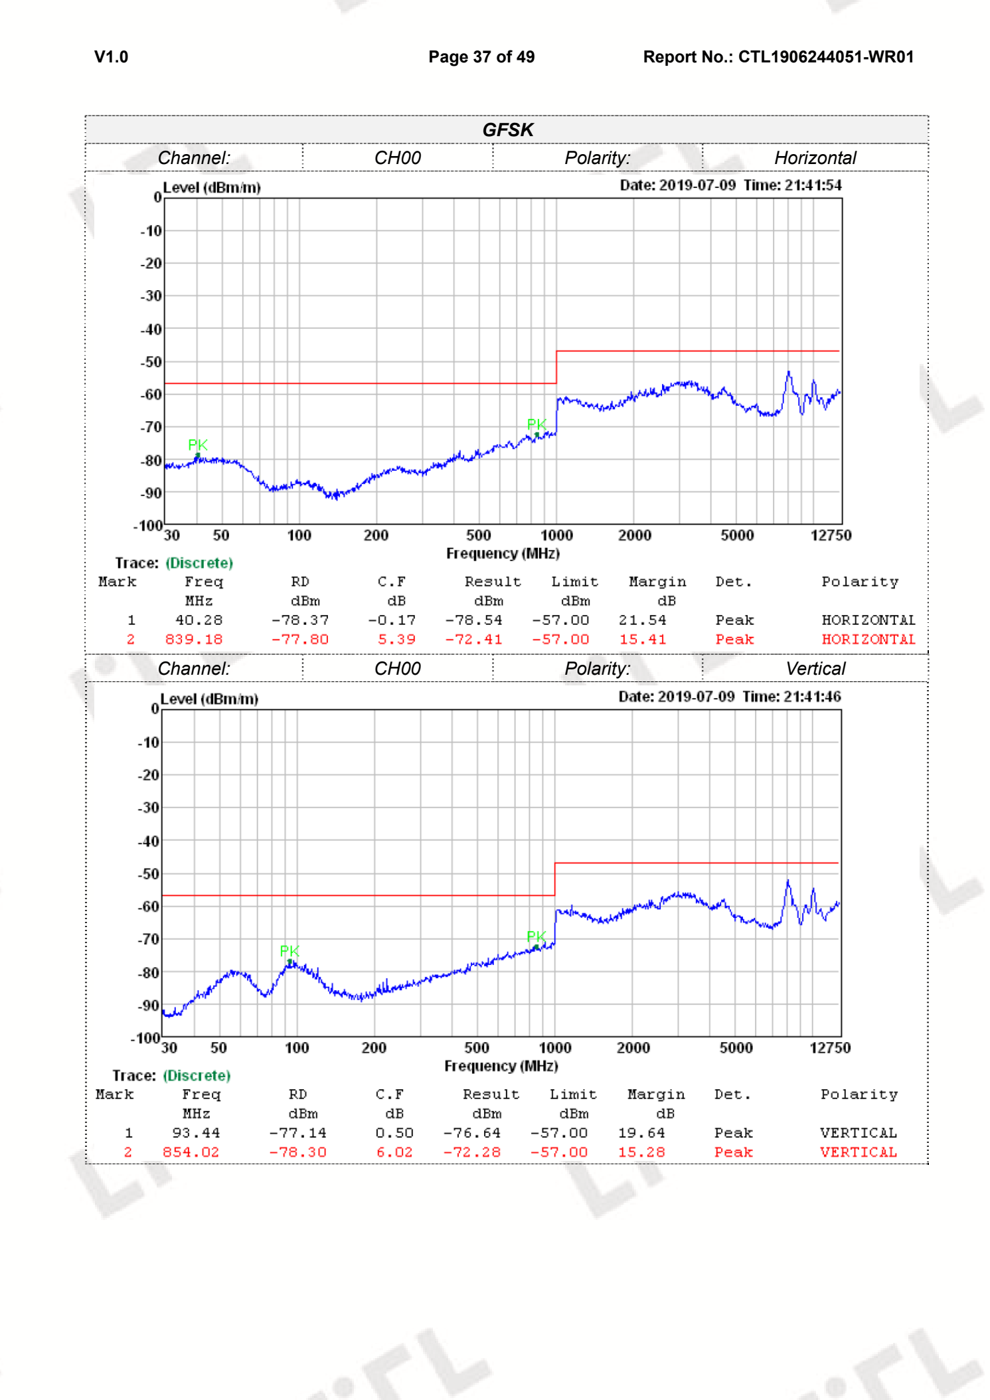
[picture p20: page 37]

V1.0 | Page 37 of 49 | Report No.: CTL1906244051-WR01

GFSK
Channel: | CH00 | Polarity: | Horizontal
Channel: | CH00 | Polarity: | Vertical

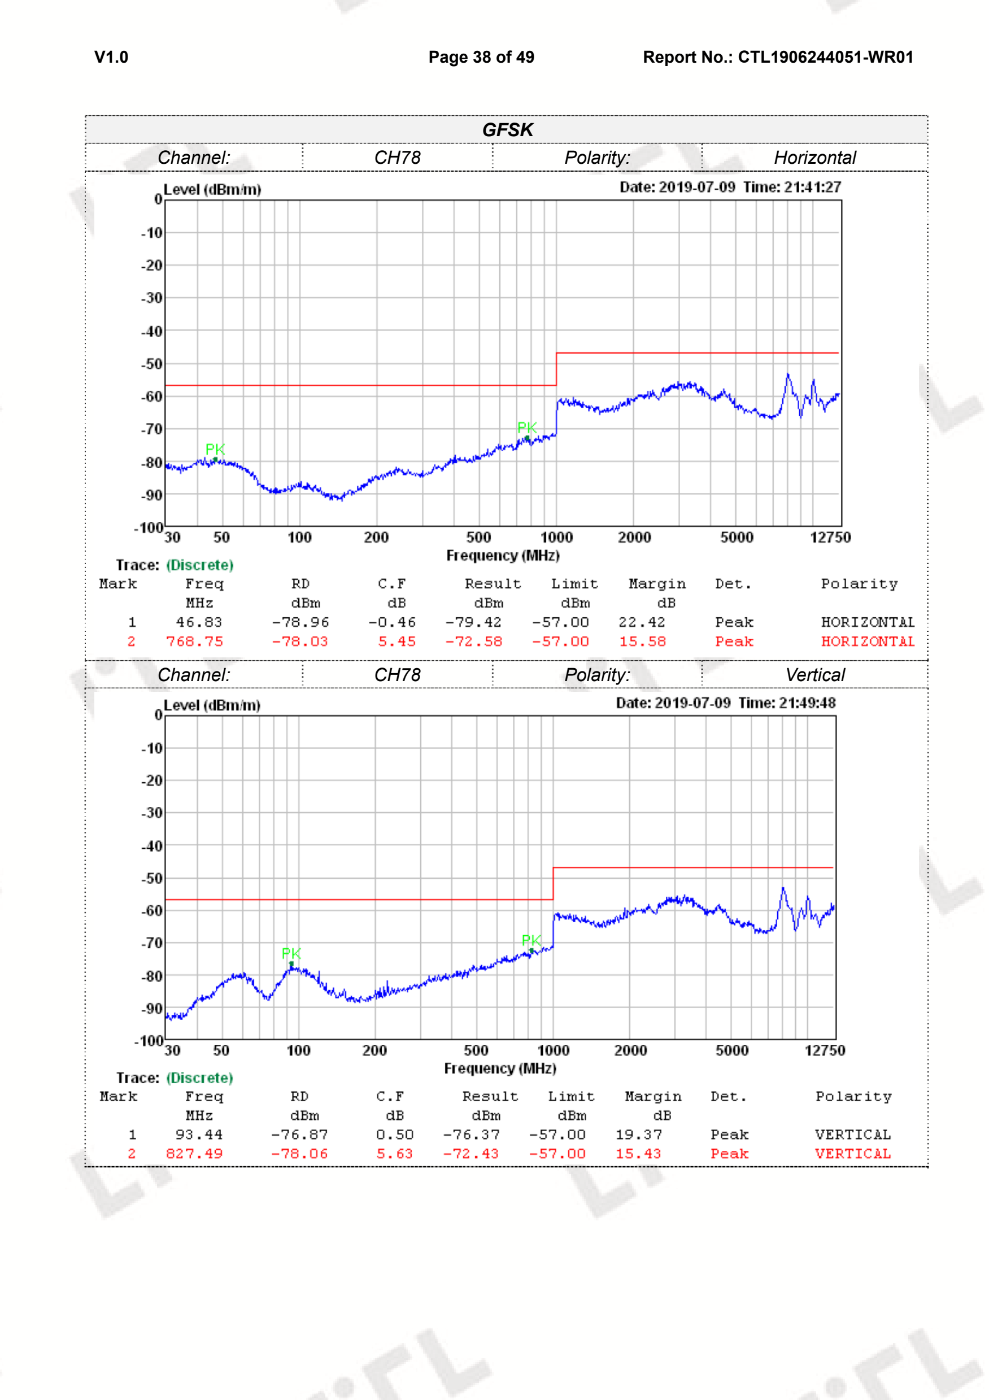
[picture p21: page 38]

V1.0 | Page 38 of 49 | Report No.: CTL1906244051-WR01

GFSK
Channel: | CH78 | Polarity: | Horizontal
Channel: | CH78 | Polarity: | Vertical

V1.0 | Page 39 of 49 | Report No.: CTL1906244051-WR01

### 3.10 Adaptivity

Limits

For Requirements and Limits please refer to ETSI EN 300 328 V2.1.1 Sub - clause 4.3.1.7.2.1 & 4.3.1.7.3.2
Test Procedure
1. The measurement procedure follows the clause 5.4.6.2.1 of the ETSI EN 300 328 V2.1.1 (2016-03).
2. For conducted measurements on device with multiple transmit chains and receive chains. The power splitter/combiner shall be used to combine all the transmit/receive chains (antenna outputs) into a single test point. The insertion loss of the power splitter/combiner shall be taken into account.
3. Interference signal shall be a100 % duty cycle interference signal is injected on the current operating channel of the UUT. This interference signal shall meet the requirements as follow:
The 99 % bandwidth (the bandwidth containing 99 % of the power) of this inference signal shall be within a range from 120 % to 200 % of the Occupied Channel Bandwidth of the UUT with a minimum of 5 MHz, while the difference between the lowest and highest level within the Occupied Channel Bandwidth of the UUT shall be maximum 4 dB.
4. Blocking signal shell be a 100 % duty cycle CW signal, and The frequency and level shell be set as follow:
Equipment Type (LBT / non- LBT) | Wanted signal mean power from companion device | Blocking signal frequency [MHz] | Blocking signal power [dBm] | Type of interfering signal
LBT | sufficient to maintain the link (see note 2) | 2 395 or 2 488,5 (see note 1) | -35 | CW
Non-LBT | -30 dB
NOTE 1: The highest frequency shall be used for testing operating channels within the range 2 400 MHz to 2 442 MHz, while the lowest frequency shall be used for testing operating
channels within the range 2 442 MHz to 2 483,5 MHz.
NOTE 2: A typical value which can be used in most cases is-50 dBm/MHz.
5. The test not applicable to none-adaptive equipment and adaptive equipment which maximum RF Output power level is less than 10 dBm e.i.r.p.

V1.0 | Page 40 of 49 | Report No.: CTL1906244051-WR01

Test Configuration

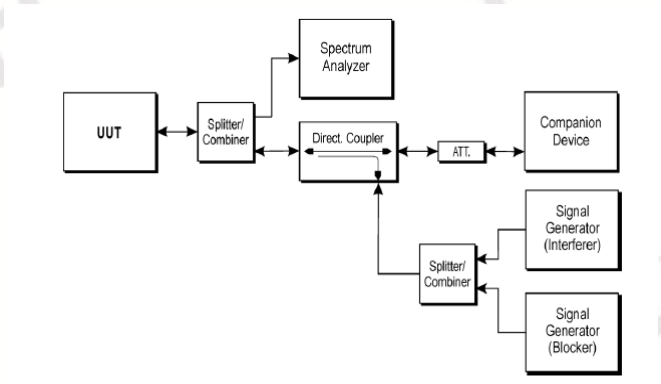
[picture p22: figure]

Test Results

Not applicable to this device which maximum RF Output power level is less than 10 dBm e.i.r.p.

V1.0 | Page 41 of 49 | Report No.: CTL1906244051-WR01

### 3.11 Receiver Blocking

Limits

While maintaining the minimum performance criteria (The minimum performance criterion shall be a PER less than or equal to 10 %. The manufacturer may declare alternative performance criteria as long as that is appropriate for the intended use of the equipment), the blocking levels at specified frequency offsets shall be equal to or greater than the limits defined for the applicable receiver category provided in below:

Receiver blocking parameters for Receiver Category 1 equipment
Wanted signal mean power from companion device (dBm) | Blocking signal frequency (MHz) | Blocking signal power (dBm) | Type of blocking signal
Pmin + 6 dB | 2 380 2 503,5 | -53 | CW
Pmin + 6 dB | 2 300 2 330 2 360 | -47 | CW
Pmin + 6 dB | 2 523,5 2 553,5 2 583,5 2 613,5 2 643,5 2 673,5 | -47 | CW

NOTE: Pmin is the minimum level of wanted signal (in dBm) required to meet the minimum performance criteria as defined in clause 4.3.1.12.3 and/or 4.3.2.11.3 in the absence of any blocking signal.

Receiver blocking parameters receiver category 2 equipment
Wanted signal mean power from companion device (dBm) | Blocking signal frequency (MHz) | Blocking signal power (dBm) | Type of blocking signal
Pmin + 6 dB | 2 380 2 503,5 | -57 | CW
Pmin + 6 dB | 2 300 2 583,5 | -47 | CW

NOTE: Pmin is the minimum level of wanted signal (in dBm) required to meet the minimum performance criteria as defined in clause 4.3.1.12.3 and/or 4.3.2.11.3 in the absence of any blocking signal.

Receiver blocking parameters receiver category 3 equipment
Wanted signal mean power from companion device (dBm) | Blocking signal frequency (MHz) | Blocking signal power (dBm) | Type of blocking signal
Pmin + 12 dB | 2 380 2 503,5 | -57 | CW
Pmin + 12 dB | 2 300 2 583,5 | -47 | CW

NOTE: Pmin is the minimum level of wanted signal (in dBm) required to meet the minimum performance criteria as defined in clause 4.3.1.12.3 and/or 4.3.2.11.3 in the absence of any blocking signal.

V1.0 | Page 42 of 49 | Report No.: CTL1906244051-WR01

Test Configuration

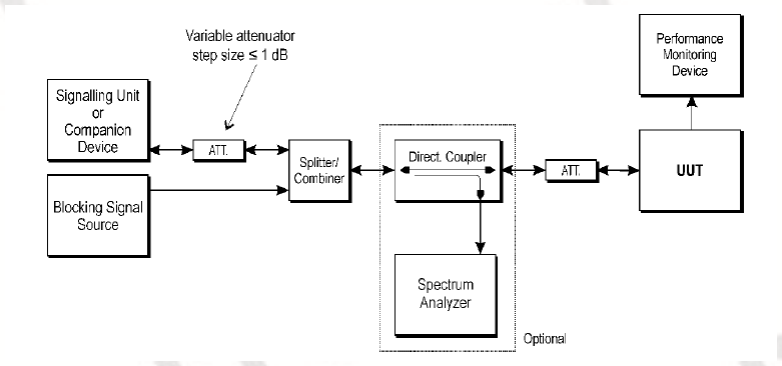
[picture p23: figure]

Test Procedure

1. For systems using multiple receive chains only one chain (antenna port) need to be tested. All other receiver inputs shall be terminated.
2. For non-frequency hopping equipment, the UUT shall be set to the lowest operating channel.
3. The blocking signal generator is set to the first frequency as defined in the appropriate table corresponding to the receiver category and type of equipment.
4. With the blocking signal generator switched off, a communication link is established between the UUT and the associated companion device. The variable attenuator is set to a value that achieves the minimum performance criteria with a resolution of at least 1 dB. The resulting level for the wanted signal at the input of the UUT is Pmin. This value shall be measured and recorded in the test report.
5. The signal level is increased by the value provided in the table corresponding to the receiver category and type of equipment.
6. The blocking signal at the UUT is set to the level provided in the table corresponding to the receiver category and type of equipment. It shall be verified and recorded in the test report that the performance criteria is met.
7. Repeat step 6 for each remaining combination of frequency and level for the blocking signal as provided in the table corresponding to the receiver category and type of equipment.
8. For non-frequency hopping equipment, repeat step 2 to step 7 with the UUT operating at the highest operating channel.

V1.0 | Page 43 of 49 | Report No.: CTL1906244051-WR01

Test result

Remark:
1. According to the Power measurement the device belongs to Receiver category 2.
2. With the blocking signal generator switched off, adjust variable attenuator value by 1dB until to communication once cannot maintains. Then replace EUT by a power sensor, measure the power and recorded as Pmin.
Test Frequency (MHz) | Wanted signal mean power from companion device (dBm) | Blocking signal frequency (MHz) | Blocking signal power (dBm) | PER
Hopping mode | Pmin + 6dB | 2380 | -57 | 3.4%
| Pmin + 6dB | 2503.5 | -57 | 3.2%
| Pmin + 6dB | 2300 | -47 | 3.6%
| Pmin + 6dB | 2583.5 | -47 | 3.3%
Note: Pmin=-68dBm

V1.0 | Page 44 of 49 | Report No.: CTL1906244051-WR01

## 4 Test Setup Photos of the EUT

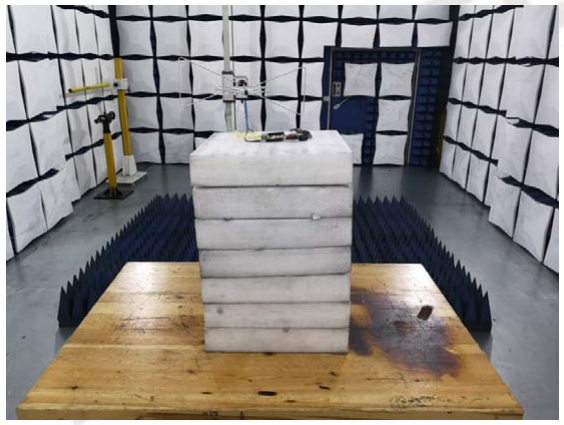
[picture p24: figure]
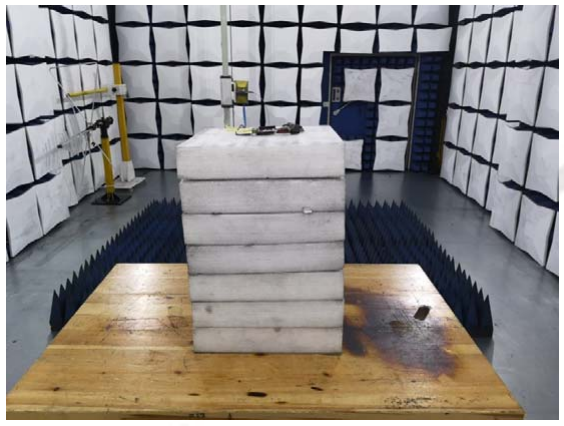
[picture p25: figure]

V1.0 | Page 45 of 49 | Report No.: CTL1906244051-WR01

## 5 External and Internal Photos of the EUT

Reference to the test report No. CTL1906244051-WE

********************** End of Report **********************

V1.0 | Page 46 of 49 | Report No.: CTL1906244051-WR01

## 6 ANNEX E

Information as required by EN 300 328 V2.1.1, clause 5.4.1
In accordance with EN 300 328, clause 5.4.1, the following information is provided by the supplier.
a) The type of modulation used by the equipment:
FHSS
Other forms of modulation
b) In case of FHSS modulation:
- In case of non-Adaptive Frequency Hopping equipment: The number of Hopping Frequencies:
- In case of Adaptive Frequency Hopping Equipment: The maximum number of Hopping Frequencies: 79 The minimum number of Hopping Frequencies: 15
- The (average) Dwell Time: 3.75ms
c) Adaptive / non-adaptive equipment: Non-adaptive Equipment
Adaptive Equipment without the possibility to switch to a non-adaptive mode Adaptive Equipment which can also operate in a non-adaptive mode
d) In case of adaptive equipment: The Channel Occupancy Time implemented by the equipment: ms
The equipment has implemented an LBT based DAA mechanism
- In case of equipment using modulation different from FHSS:
The equipment is Frame Based equipment
The equipment is Load Based equipment
The equipment can switch dynamically between Frame Based and Load Based equipment
The CCA time implemented by the equipment:
The equipment has implemented an non-LBT based DAA mechanism
The equipment can operate in more than one adaptive mode
e) In case of non-adaptive Equipment:
The maximum RF Output Power (e.i.r.p.): | dBm
The maximum (corresponding) Duty Cycle: | %
Equipment with dynamic behaviour, that behaviour is described here. (e.g. the different combinations of duty cycle and corresponding power levels to be declared):
f) The worst case operational mode for each of the following tests:
- RF Output Power
DH5,2DH5,3DH5
- Power Spectral Density
N/A
- Duty cycle, Tx-Sequence, Tx-gap
N/A
- Dwell time, Minimum Frequency Occupation & Hopping Sequence (only for FHSS equipment) DH5,2DH5,3DH5
- Hopping Frequency Separation (only for FHSS equipment)
DH5,2DH5,3DH5
- Medium Utilisation
N/A
- Adaptivity
N/A
- Occupied Channel Bandwidth

V1.0 | Page 47 of 49 | Report No.: CTL1906244051-WR01

DH5,2DH5,3DH5
- Transmitter unwanted emissions in the OOB domain
DH5,2DH5,3DH5
- Transmitter unwanted emissions in the spurious domain DH5
- Receiver spurious emissions
DH5
- Receiver Blocking
DH5
g) The different transmit operating modes (tick all that apply): Operating mode 1: Single Antenna Equipment
Equipment with only 1 antenna
Equipment with 2 diversity antennas but only 1 antenna active at any moment in time Smart Antenna Systems with 2 or more antennas, but operating in a (legacy) mode where only 1 antenna is used. (e.g. IEEE 802.11™ [i.3] legacy mode in smart antenna systems)
Operating mode 2: Smart Antenna Systems - Multiple Antennas without beam forming Single spatial stream / Standard throughput / (e.g. IEEE 802.11™ [i.3] legacy mode) High Throughput (> 1 spatial stream) using Occupied Channel Bandwidth 1
High Throughput (> 1 spatial stream) using Occupied Channel Bandwidth 2 Operating mode 3: Smart Antenna Systems - Multiple Antennas with beam forming Single spatial stream / Standard throughput (e.g. IEEE 802.11™ [i.3] legacy mode) High Throughput (> 1 spatial stream) using Occupied Channel Bandwidth 1
High Throughput (> 1 spatial stream) using Occupied Channel Bandwidth 2
h) In case of Smart Antenna Systems:
- The number of Receive chains:
- The number of Transmit chains:
Symmetrical power distribution Asymmetrical power distribution In case of beam forming, the maximum (additional) beam forming gain:
i) Operating Frequency Range(s) of the equipment:
- Operating Frequency Range 1: 2402MHz to2480MHz
- | Operating Frequency Range 2: | MHz to | MHz
NOTE: Add more lines if more Frequency Ranges are supported.
j) Occupied Channel Bandwidth(s):
- Occupied Channel Bandwidth 1: 1 MHz
- | Occupied Channel Bandwidth 2: | MHz
k) Type of Equipment (stand-alone, combined, plug-in radio device, etc.):
| Stand-alone
Combined Equipment (Equipment where the radio part is fully integrated within another type
| of equipment)
Plug-in radio device (Equipment intended for a variety of host systems)
| Other
l) The extreme operating conditions that apply to the equipment: Operating temperature range: -20°C to +55°C
Operating voltage range: 4.25V to 5.75V | AC | DC
Details provided are for the: | stand-alone equipment
Combined (or host) equipment
| | Test jig

V1.0 | Page 48 of 49 | Report No.: CTL1906244051-WR01
m) The intended combination(s) of the radio equipment power settings and one or more antenna assemblies and their corresponding e.i.r.p levels:
- Antenna Type:
Internal Antenna
Antenna Gain: 1.5dBi
If applicable, additional beamforming gain (excluding basic antenna gain): dB Temporary RF connector provided
No temporary RF connector provided
Dedicated Antennas (equipment with antenna connector)
Single power level with corresponding antenna(s) Multiple power settings and corresponding antenna(s) Number of different Power Levels:
Power Level 1: | dBm
Power Level 2: | dBm
Power Level 3: | dBm
n) For each of the Power Levels, provide the intended antenna assemblies, their corresponding gains (G) and the resulting e.i.r.p. levels also taking into account the beamforming gain (Y) if applicable
Power Level 1: dBm
Number of antenna assemblies provided for this power level:
Assembly # | Gain (dBi) | e.i.r.p. (dBm) | Part number or model name

1
2
3
4
Power Level 2: dBm
Number of antenna assemblies provided for this power level:
Assembly # | Gain (dBi) | e.i.r.p. (dBm) | Part number or model name

1
2
3
4

Power Level 3: dBm
Number of antenna assemblies provided for this power level:
Assembly # | Gain (dBi) | e.i.r.p. (dBm) | Part number or model name

1
2
3
4

V1.0 | Page 49 of 49 | Report No.: CTL1906244051-WR01
o) The nominal voltages of the stand-alone radio equipment or the nominal voltages of the combined (host) equipment or test jig in case of plug-in devices:
Details provided are for the: Stand-alone equipment
Combined (or host) equipment
| Test jig
Supply Voltage | AC mains State AC voltage | V
DC | State DC voltage 5.0V
In case of DC, indicate the type of power source
| Internal Power Supply
External Power Supply or AC/DC adapter
| Battery
| Other: DC 5V from PC
p) Describe the test modes available which can facilitate testing:
q) The equipment type (e.g. Bluetooth®, IEEE 802.11™ [i.3], proprietary, etc.): Bluetooth®
r) Geo-location capability supported by the equipment:
Yes
The geographical location determined by the equipment as defined in clause 4.3.1.13.2 or clause 4.3.2.12.2 is not accessible to the user
No
s) Describe the minimum performance criteria that apply to the equipment (see clause 4.3.1.12.3 or clause 4.3.2.11.3):
N/A

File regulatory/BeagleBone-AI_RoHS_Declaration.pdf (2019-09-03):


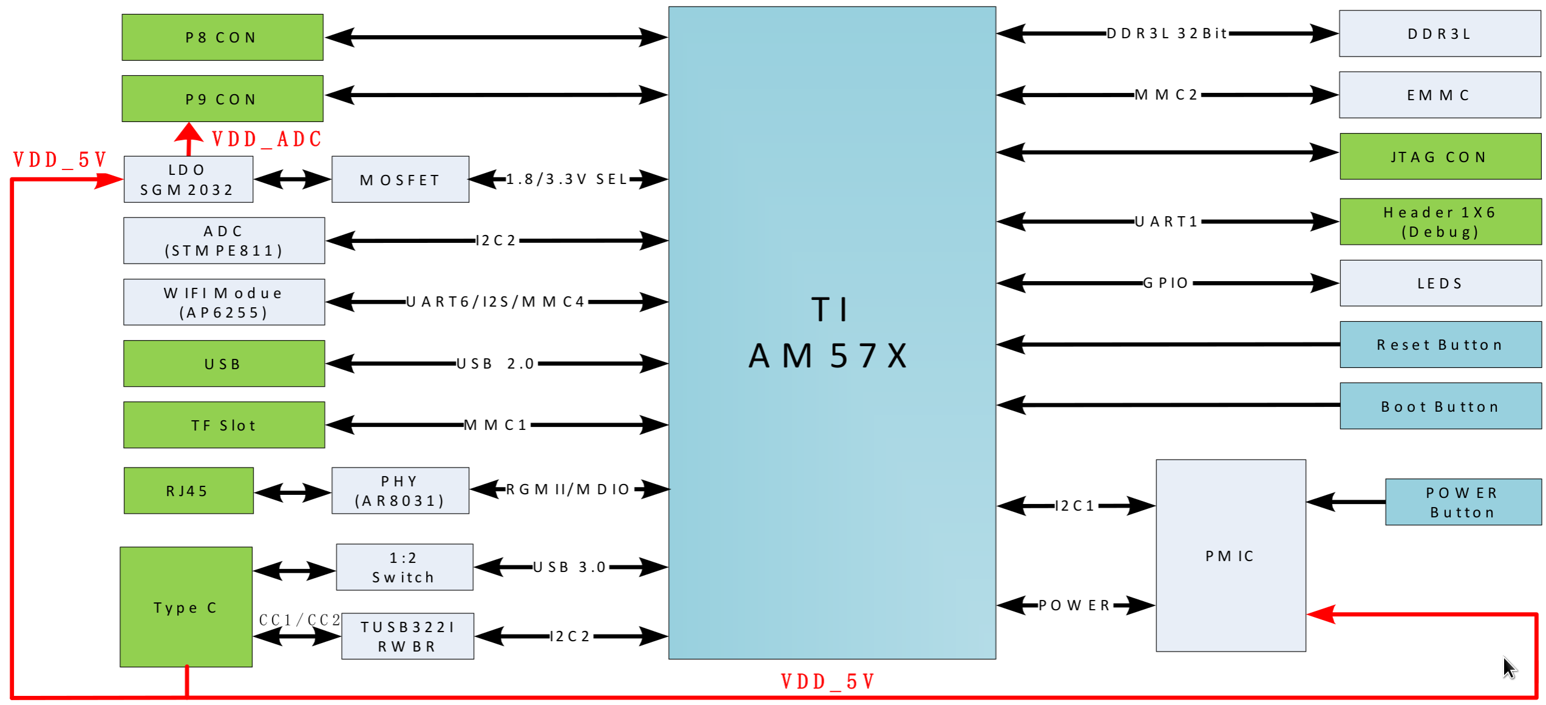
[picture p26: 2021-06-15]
kicad/beaglebone-ai-rev-a1/images/blockdiagram.png

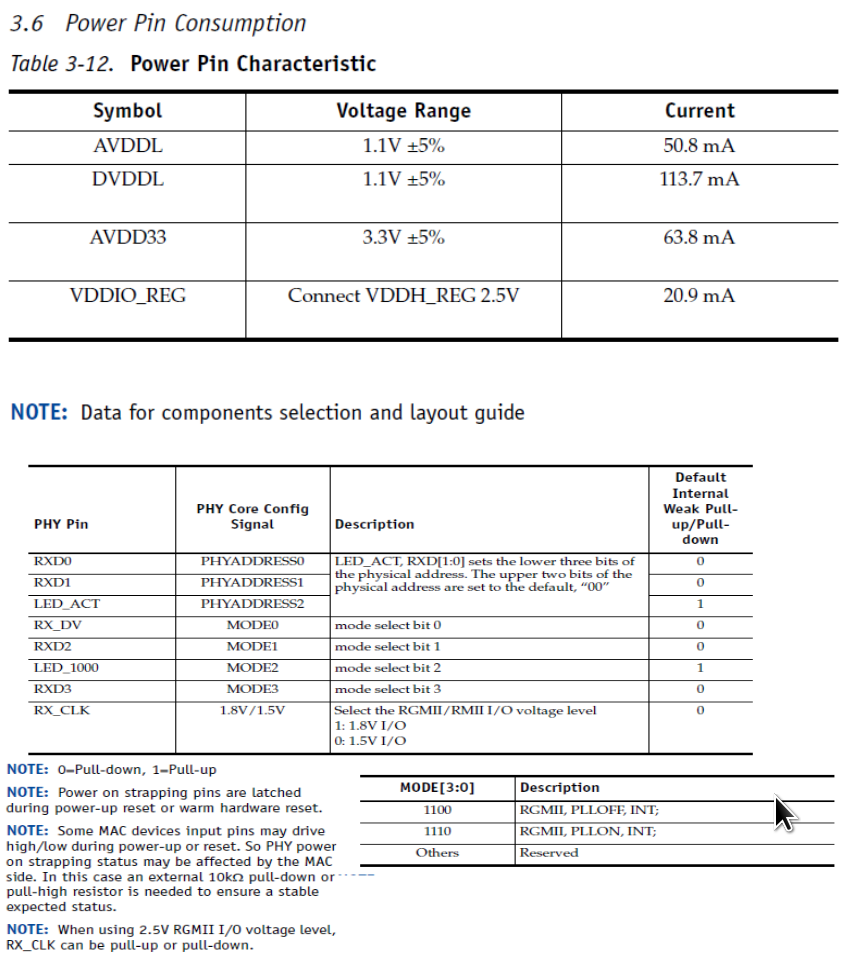
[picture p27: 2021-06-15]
kicad/beaglebone-ai-rev-a2/images/PowerPinConsumption.png

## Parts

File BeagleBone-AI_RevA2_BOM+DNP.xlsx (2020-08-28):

Quantity | Reference | Value | Rating | Part Type | PN | Manufacturer | Manufacturer Part Number | Description | Temperature | PCB Footprint | ASSY
2 | FB2,FB10 | 120ohm | 1.3A | Ferrite Bead | 303030040 | Murata | BLM15PD121SN1D | SMD Ferrite Bead 120R-1.3A;0402 | -55°C to 125°C | L0402 | NI
1 | C488 | 1pF | 50V,NPO | Ceramic Capacitor | 302010021 | YAGEO | CC0402BRNPO9BN1R0 | SMD CAP Ceramic 1pF-50V-0.1pF-NPO;0402 | -55°C to 125°C | C0402 | NI
1 | C473 | 5.1pF | 50V,NPO | Ceramic Capacitor | 302012350 | Yageo | CC0402CRNPO9BN5R1 | SMD CAP Ceramic 5.1pF-50V-0.25pF-COG/NPO;0402 | -55°C to 125°C | C0402 | NI
2 | C85,C137 | 1uF | 10V,X5R | Ceramic Capacitor | 302010040 | YAGEO | CC0402KRX5R6BB105 | SMD CAP Ceramic 1uF-10V-10%-X5R;0402 | -55°C to 85°C | C0402 | NI
3 | C86,C142,C267 | 100nF | 16V,X7R | Ceramic Capacitor | 302010004 | YAGEO | CC0402KRX7R7BB104 | SMD CAP Ceramic 100nF-16V-10%-X7R;0402 | -55°C to 125°C | C0402 | NI
1 | C135 | 10nF | 50V,X7R | Ceramic Capacitor | 302010006 | YAGEO | CC0402KRX7R9BB103 | SMD CAP Ceramic 10nF-50V-10%-X7R;0402 | -55°C to 125°C | C0402 | NI
1 | C129 | 10UF | 6.3V,X5R | Ceramic Capacitor | 302010053 | YAGEO | CC0402MRX5R5BB106 | SMD CAP Ceramic 10uF-6.3V-20%-X5R;0402 | -55°C to 85°C | C0402 | NI
6 | R38,R162,R164,R173,R692,R693 | 100K | 1% | Thick Film Resistor | 301010456 | YAGEO | RC0402FR-07100KL | SMD RES 100K-1%-1/16W;0402 | -55°C to 155°C | R0402 | NI
14 | R8,R16,R41,R59,R61,R66,R87,R156,R182,R413,R421,R424,R560,R597 | 10K | 1% | Thick Film Resistor | 301010047 | YAGEO | RC0402FR-0710KL | SMD RES 10K-1%-1/16W;0402 | -55°C to 155°C | R0402 | NI
1 | R75 | 11K | 1% | Thick Film Resistor | 301010568 | YAGEO | RC0402FR-0711KL | SMD RES;11K-1%-1/16W-0402 | -55°C to 155°C | R0402 | NI
5 | R154,R163,R166,R181,R187 | 2.49K | 1% | Thick Film Resistor | 301010856 | YAGEO | RC0402FR-072K49L | SMD RES 2.49K-1%-1/16W;0402 | -55°C to 155°C | R0402 | NI
5 | R62,R63,R64,R65,R191 | 4.7K | 1% | Thick Film Resistor | 301010633 | YAGEO | RC0402FR-074K7L | SMD RES;4.7K-1%-1/16W-0402 | -55°C to 155°C | R0402 | NI
2 | R533,R534 | 5.1K | 1% | Thick Film Resistor | 301010495 | YAGEO | RC0402FR-075K1L | SMD RES;5.1K-1%-1/16W;0402 | -55°C to 155°C | R0402 | NI
5 | R141,R158,R165,R170,R171 | 5.76K | 1% | Thick Film Resistor | 301013075 | YAGEO | RC0402FR-075K76L | SMD RES 5.76K-1%-1/16W;0402 | -55°C to 155°C | R0402 | NI
5 | R46,R56,R641,R698,R703 | 0R | 5% | Thick Film Resistor | 301010000 | YAGEO | RC0402JR-070RL | SMD RES 0R-5%-1/16W;0402 | -55°C to 155°C | R0402 | NI
3 | R151,R153,R463 | 1K | 5% | Thick Film Resistor | 301010006 | YAGEO | RC0402JR-071KL | SMD RES 1K-5%-1/16W;0402 | -55°C to 155°C | R0402 | NI
1 | R35 | 200K | 5% | Thick Film Resistor | 301012017 | YAGEO | RC0402JR-07200KL | SMD RES 200K-5%-1/16W;0402 | -55°C to 155°C | R0402 | NI
1 | R699 | 0.1R | 5% | Thick Film Resistor | 301010264 | YAGEO | RL0805JR-070R1L | SMD RES 0.1R-5%-1/8W;0805 | -55°C to 155°C | R0805 | NI
1 | P2 | Heaader 2x10 1.27mm |  | Pin Header |  |  |  | Dual Line Header 10x2pin Tin |  | HEADER10X2_SMD | NI
3 | ID1,ID2,ID3 | MP | 40mil | MARK |  |  |  | MARK Point,DIA 40mil |  | FD40 | NI
4 | MH1,MH2,MH3,MH4 | Plated Hole | 3.175MM | HOLE |  |  |  | Plated Hole,Circle,DAI 4.445MM ,VIA 3.175MM |  | MTGH200C125D_PL | NI
6 | TP2,TP3,TP4,TP7,TP8,TP11 | TP | 30mil | TP |  |  |  | Test Point,DIA 30mil |  | TP30 | NI
2 | TP1,TP5 | TP | 30mil | TP |  |  |  | Test Point,DIA 30mil |  | TP60C_SMD | NI
2 | C1,C462 | 1nF | 50V,X7R | Ceramic Capacitor | 302010005 | YAGEO | CC0402KRX7R9BB102 | SMD CAP Ceramic 1nF-50V-10%-X7R;0402 | -55°C to 125°C | C0402
1 | J91 | 10118241-001RLF |  | HDMI Connector | 320010901 | FCI | 10118241-001RLF | SMD HDMI Type D Right Angle;SMT+DIP | -40°C to 85°C | hdmis19_4p4
6 | D1,D2,D3,D4,D5,D8 | Green |  | LED | 304090043 | Everlight | 19-217/G7C-AN1P2/3T | SMD LED Clear-Green;LED-0603 | -40°C to 85°C | D0603
1 | U9 | 24LC32AT-I/OT |  | EEPROM | 310090051 | Microchip | 24LC32AT-I/OT | SMD IC Memory;SOT-23-5 | -40°C to 85°C | SOT23_5
1 | Q17 | 2N7002 | 60V,115mA | MOSFET | 305030119 | Fairchild | 2N7002 | SMD MOSFET N-CH 60V-115mA ;SOT-23 | -55°C to 150°C | SOT23_123
1 | U4 | AM5729BABCXEAR |  | MPU | 310011104 | TEXAS INSTRUMENTS | AM5729BABCX | SMD IC MCU;FCBGA-760 | 0°C to 90°C | BGA760C80P28X28_2300X2300X305
6 | FB3,FB4,FB5,FB7,FB8,FB9 | 120ohm | 1.3A | Ferrite Bead | 303030040 | Murata | BLM15PD121SN1D | SMD Ferrite Bead 120R-1.3A;0402 | -55°C to 125°C | L0402
1 | Q18 | BSS138LT1G | 50V,220mA | MOSFET | 305030320 | ON | BSS138LT1G | SMD MOSFET N-CH 50V-220mA;SOT-23 | -55°C to 150°C | SOT95P240X111-3N
1 | C268 | 1.5pF | 50V,NPO | Ceramic Capacitor | 302010023 | YAGEO | CC0402BRNPO9BN1R5 | SMD CAP Ceramic 1.5pF-50V-0.1pF-NPO;0402 | -55°C to 125°C | C0402
1 | C92 | 10pF | 50V,NPO | Ceramic Capacitor | 302010001 | YAGEO | CC0402JRNPO9BN100 | SMD CAP Ceramic 10pF-50V-5%-NPO;0402 | -55°C to 125°C | C0402
2 | C31,C32 | 220pF | 50V,NPO | Ceramic | 302010013 | YAGEO | CC0402JRNPO9BN221 | SMD CAP Ceramic 220pF-50V-5%-NPO;0402 | -55°C to 125°C | C0402
4 | C13,C14,C15,C16 | 24pF | 50V,NPO | Ceramic Capacitor | 302010825 | YAGEO | CC0402JRNPO9BN240 | SMD CAP Ceramic 24pF-50V-5%-NPO;0402 | -55°C to 125°C | C0402
2 | C334,C337 | 27pF | 50V,NPO | Ceramic Capacitor | 302010027 | YAGEO | CC0402JRNPO9BN270 | SMD CAP Ceramic 27pF-50V-5%-NPO;0402 | -55°C to 125°C | C0402
35 | C44,C47,C50,C54,C59,C63,C67,C71,C73,C75,C77,C78,C82,C83,C106,C107,C108,C109,C179,C204,C214,C216,C254,C260,C273,C274,C275,C276,C277,C279,C283,C480,C489,C490,C495 | 1uF | 10V,X5R | Ceramic Capacitor | 302010040 | YAGEO | CC0402KRX5R6BB105 | SMD CAP Ceramic 1uF-10V-10%-X5R;0402 | -55°C to 85°C | C0402
62 | C5,C6,C8,C20,C27,C28,C34,C35,C41,C42,C48,C49,C53,C55,C60,C61,C62,C64,C69,C70,C72,C74,C76,C80,C81,C87,C88,C98,C99,C123,C143,C144,C147,C149,C153,C159,C163,C184,C225,C226,C281,C285,C286,C320,C321,C325,C327,C335,C336,C353,C443,C444,C445,C446,C457,C466,C472,C491,C492,C496,C497,C498 | 100nF | 16V,X7R | Ceramic Capacitor | 302010004 | YAGEO | CC0402KRX7R7BB104 | SMD CAP Ceramic 100nF-16V-10%-X7R;0402 | -55°C to 125°C | C0402
99 | C9,C10,C11,C17,C18,C19,C22,C23,C24,C25,C36,C40,C46,C57,C66,C79,C84,C95,C97,C100,C101,C102,C103,C104,C118,C119,C122,C125,C131,C136,C138,C139,C140,C141,C145,C146,C148,C154,C155,C158,C162,C165,C166,C171,C174,C175,C178,C181,C182,C185,C186,C187,C189,C190,C193,C197,C199,C201,C202,C203,C205,C206,C207,C209,C210,C211,C212,C213,C218,C220,C221,C222,C223,C224,C227,C230,C231,C232,C233,C234,C235,C236,C237,C238,C242,C245,C255,C256,C257,C258,C259,C261,C262,C269,C270,C271,C272,C299,C483 | 10nF | 50V,X7R | Ceramic Capacitor | 302010006 | YAGEO | CC0402KRX7R9BB103 | SMD CAP Ceramic 10nF-50V-10%-X7R;0402 | -55°C to 125°C | C0402
13 | C45,C56,C65,C110,C112,C168,C176,C177,C183,C200,C215,C217,C296 | 10UF | 6.3V,X5R | Ceramic Capacitor | 302010053 | YAGEO | CC0402MRX5R5BB106 | SMD CAP Ceramic 10uF-6.3V-20%-X5R;0402 | -55°C to 85°C | C0402
9 | C38,C43,C117,C121,C133,C134,C151,C152,C157 | 2.2uF | 6.3V,X5R | Ceramic Capacitor | 302010233 | YAGEO | CC0402MRX5R5BB225 | SMD CAP Ceramic 2.2uF-6.3V-20%-X5R;0402 | -55°C to 85°C | C0402
21 | C4,C7,C37,C89,C90,C91,C113,C116,C120,C124,C130,C161,C170,C180,C198,C208,C291,C292,C295,C300,C461 | 10uF | 10V,X5R | Ceramic Capacitor | 302010103 | YAGEO | CC0603KRX5R6BB106 | SMD CAP Ceramic 10uF-10V-10%-X5R;0603 | -55°C to 85°C | C0603
7 | C21,C126,C164,C169,C172,C278,C282 | 2.2uF | 16V,X5R | Ceramic Capacitor | 302010344 | YAGEO | CC0603KRX5R7BB225 | SMD CAP Ceramic 2.2uF-16V-10%-X5R;0603 | -55°C to 85°C | C0603
15 | C2,C3,C30,C33,C114,C115,C127,C128,C132,C156,C194,C195,C196,C456,C464 | 4.7uF | 16V,X5R | Ceramic Capacitor | 302010408 | YAGEO | CC0603KRX5R7BB475 | SMD CAP Ceramic 4.7uF-16V-10%-X5R;0603 | -55°C to 85°C | C0603
4 | C39,C58,C96,C188 | 22uF | 6.3V,X5R | Ceramic Capacitor | 302010120 | YAGEO | CC0603MRX5R5BB226 | SMD CAP Ceramic 22uF-6.3V-20%-X5R;0603 | -55°C to 85°C | C0603
15 | C12,C26,C93,C94,C105,C111,C192,C263,C264,C265,C266,C293,C294,C297,C298 | 47uF | 6.3V,X5R | Ceramic Capacitor | 302010166 | YAGEO | CC0805MKX5R5BB476 | SMD CAP Ceramic 47uF-6.3V-20%-X5R;0805 | -55°C to 85°C | C0805
2 | C481,C482 | 100uF | 10V,X5R | Ceramic Capacitor | 302011571 | YAGEO | CC1210MKX5R6BB107 | SMD CAP Ceramic 100uF-10V-20%-X5R;1210 | -55°C to 85°C | C1210
2 | C29,C326 | 47uF | 10V,X7R | Ceramic Capacitor | 302011624 | Samsung | CL32B476KPJNNWE | SMD CAP Ceramic 47uF-10V-X7R;1210 | -55°C to 125°C | C1210
2 | L1,L2 | 1uH | 9A | Power Inductor | 303011311 | CODACA | CSAB0420-1R0M | SMD Inductor 1uH-20%-9A;0420 | -40℃ to 125℃ | L40X40_B
2 | U2,U11 | D2516ECMDXGJD-U |  | Memory | 310091066 | Kingston Technology | D2516ECMDXGJD-U | SMD IC Memory-DDR3L 4 Gb(256M x 16)-1866 Mbps-13.5*7.5*1.2mm;FBGA-96 | 0°C to 95°C | bga96g
2 | T1,T2 | Si1902CDL-T1-GE3 |  | MOSFET | 305040015 | Diodes | DMN63D8LDW | SMD MOSFET 2N-CH 30V 220MA SOT-363 | -55°C to 150°C | sot363_6
1 | R120 | 27.4K | 1% | Thick Film Resistor | 301011904 | Panasonic | ERJ-2RKF2742X | RES SMD 27.4K-1%-1/10W;0402 | -55°C to 155°C | R0402
2 | D46,D47 | ESD0402-V05L |  | ESD | 304060074 | SEMITEL | ESDPSA0402V05 | SMD Diode ESD 0.05pF;0402 | -40°C to 90°C | D0402
2 | P8,P9 | 2.54mm 2x23Pin |  | Pin Socket | 320030424 | SINOTOP | FF-1236 | DIP Black Female Header;2*23P-2.54*8.5-3.0mm | -40°C to 105°C | h2x23mz
2 | S1,S3 | Tacticle Switch |  | TACT | 311020198 | C&K | KMR231GLFS | SMD Top Button 300gf;4P-L4.6*W2.8*H1.9mm | -40°C to 85°C | SWS4B46X28
2 | Q1,Q4 | MMBT2907A | 60V,800mA | Transistor | 305020037 | Fairchild | MMBT2907A | SMD Transistor PNP 60V-800mA;SOT23-3 | -55°C to 150°C | SOT23_123
2 | FL1,FL2 | NFM21PC474R1C3D | 0.47uF | filter | 306050394 | MURATA | NFM21PC474R1C3D | SMD Filter 2A 16VDC;0.47uf-20%;0805 | -55°C to 125°C | fl0805
2 | D78,D79 | PRTR5V0U2X,215 | 5.5V | ESD | 304050022 | NXP | PRTR5V0U2X,215 | SMD Diode TVS;5.5V;SOT-143B | -40°C to 85°C | SOT143_190P240X115-4N
15 | R3,R44,R119,R133,R168,R387,R389,R390,R392,R571,R656,R659,R689,R700,R708 | 100K | 1% | Thick Film Resistor | 301010456 | YAGEO | RC0402FR-07100KL | SMD RES 100K-1%-1/16W;0402 | -55°C to 155°C | R0402
63 | R1,R2,R4,R13,R18,R19,R20,R21,R24,R27,R54,R74,R80,R82,R86,R98,R99,R101,R102,R103,R104,R107,R112,R113,R121,R122,R124,R127,R139,R155,R157,R169,R174,R190,R338,R418,R419,R420,R422,R423,R493,R516,R561,R562,R563,R564,R565,R566,R567,R572,R596,R598,R599,R600,R601,R602,R603,R604,R605,R606,R661,R690,R691 | 10K | 1% | Thick Film Resistor | 301010047 | YAGEO | RC0402FR-0710KL | SMD RES 10K-1%-1/16W;0402 | -55°C to 155°C | R0402
1 | R84 | 10R | 1% | Thick Film Resistor | 301010444 | YAGEO | RC0402FR-0710RL | SMD RES 10R-1%-1/16W;0402 | -55°C to 155°C | R0402
1 | R118 | 11K | 1% | Thick Film Resistor | 301010568 | YAGEO | RC0402FR-0711KL | SMD RES;11K-1%-1/16W-0402 | -55°C to 155°C | R0402
1 | R135 | 120K | 1% | Thick Film Resistor | 301010518 | YAGEO | RC0402FR-07120KL | SMD RES 120K-1%-1/16W;0402 | -55°C to 155°C | R0402
1 | R71 | 13K | 1% | Thick Film Resistor | 301011848 | YAGEO | RC0402FR-0713KL | SMD RES 13K-1%-1/16W;0402 | -55°C to 155°C | R0402
1 | R57 | 18K | 1% | Thick Film Resistor | 301011349 | YAGEO | RC0402FR-0718KL | SMD RES 18K-1%-1/16W;0402 | -55°C to 155°C | R0402
3 | R58,R76,R554 | 20K | 1% | Thick Film Resistor | 301010072 | YAGEO | RC0402FR-0720KL | SMD RES 20K-1%-1/16W;0402 | -55°C to 155°C | R0402
2 | R589,R595 | 220R | 1% | Thick Film Resistor | 301010521 | YAGEO | RC0402FR-07220RL | SMD RES-220R-1%-1/16W;0402 | -55°C to 155°C | R0402
2 | R22,R88 | 240R | 1% | Thick Film Resistor | 301011475 | YAGEO | RC0402FR-07240RL | SMD RES 240R-1%-1/16W;0402 | -55°C to 155°C | R0402
1 | R172 | 2.49K | 1% | Thick Film Resistor | 301010856 | YAGEO | RC0402FR-072K49L | SMD RES 2.49K-1%-1/16W;0402 | -55°C to 155°C | R0402
1 | R79 | 30K | 1% | Thick Film Resistor | 301010048 | YAGEO | RC0402FR-0730KL | SMD RES 30K-1%-1/16W;0402 | -55°C to 155°C | R0402
2 | R17,R91 | 40.2K | 1% | Thick Film Resistor | 301010062 | YAGEO | RC0402FR-0740K2L | SMD RES 40.2K-1%-1/16W;0402 | -55°C to 155°C | R0402
1 | R657 | 44.2K | 1% | Thick Film Resistor | 301011887 | YAGEO | RC0402FR-0744K2L | SMD RES 44.2K-1%-1/16W;0402 | -55°C to 155°C | R0402
25 | R25,R30,R31,R33,R34,R36,R37,R39,R40,R42,R43,R123,R125,R126,R128,R129,R131,R132,R136,R137,R140,R142,R143,R160,R161 | 47R | 1% | Thick Film Resistor | 301010878 | YAGEO | RC0402FR-0747RL | SMD RES 47R-1%-1/16W;0402 | -55°C to 155°C | R0402
2 | R9,R85 | 499R | 1% | Thick Film Resistor | 301012386 | YAGEO | RC0402FR-07499RL | SMD RES 499R-1%-1/16W;0402 | -55°C to 155°C | R0402
2 | R26,R29 | 49.9R | 1% | Thick Film Resistor | 301010041 | YAGEO | RC0402FR-0749R9L | SMD RES 49.9R-1%-1/16W;0402 | -55°C to 155°C | R0402
8 | R72,R73,R78,R180,R189,R192,R193,R194 | 4.7K | 1% | Thick Film Resistor | 301010633 | YAGEO | RC0402FR-074K7L | SMD RES;4.7K-1%-1/16W-0402 | -55°C to 155°C | R0402
98 | R5,R6,R7,R10,R14,R15,R23,R28,R47,R48,R49,R50,R55,R60,R67,R68,R69,R70,R77,R81,R89,R90,R100,R105,R108,R130,R145,R146,R148,R149,R152,R159,R183,R201,R385,R576,R577,R578,R579,R580,R611,R614,R615,R616,R617,R618,R619,R620,R621,R622,R623,R624,R625,R626,R627,R628,R629,R630,R631,R632,R633,R634,R635,R636,R637,R638,R639,R642,R643,R644,R645,R646,R652,R653,R662,R663,R664,R665,R666,R667,R668,R669,R680,R681,R682,R683,R684,R685,R686,R687,R688,R694,R695,R696,R697,R702,R706,R707 | 0R | 5% | Thick Film Resistor | 301010000 | YAGEO | RC0402JR-070RL | SMD RES 0R-5%-1/16W;0402 | -55°C to 155°C | R0402
2 | R83,R294 | 100R | 5% | Thick Film Resistor | 301010028 | YAGEO | RC0402JR-07100RL | SMD RES 100R-5%-1/16W;0402 | -55°C to 155°C | R0402
21 | R138,R144,R147,R150,R588,R590,R591,R592,R593,R594,R670,R671,R672,R673,R674,R675,R676,R677,R678,R679,R701 | 1K | 5% | Thick Film Resistor | 301010006 | YAGEO | RC0402JR-071KL | SMD RES 1K-5%-1/16W;0402 | -55°C to 155°C | R0402
2 | R11,R12 | 1M | 5% | Thick Film Resistor | 301010009 | YAGEO | RC0402JR-071ML | SMD RES 1M-5%-1/16W;0402 | -55°C to 155°C | R0402
4 | R45,R51,R52,R53 | 200K | 5% | Thick Film Resistor | 301012017 | YAGEO | RC0402JR-07200KL | SMD RES 200K-5%-1/16W;0402 | -55°C to 155°C | R0402
9 | R92,R93,R94,R95,R96,R97,R199,R200,R202 | 22R | 5% | Thick Film Resistor | 301010002 | YAGEO | RC0402JR-0722RL | SMD RES 22R-5%-1/16W;0402 | -55°C to 155°C | R0402
2 | R134,R475 | 2.2K | 5% | Thick Film Resistor | 301010039 | YAGEO | RC0402JR-072K2L | SMD RES 2.2K-5%-1/16W;0402 | -55°C to 155°C | R0402
21 | R106,R109,R110,R111,R114,R115,R116,R117,R333,R334,R336,R337,R581,R582,R583,R584,R585,R607,R608,R609,R610 | 33R | 5% | Thick Film Resistor | 301010034 | YAGEO | RC0402JR-0733RL | SMD RES 33R-5%-1/16W;0402 | -55°C to 155°C | R0402
9 | R175,R176,R177,R178,R179,R184,R185,R186,R188 | 47K | 5% | Thick Film Resistor | 301010005 | YAGEO | RC0402JR-0747KL | SMD RES 47K-5%-1/16W;0402 | -55°C to 155°C | R0402
1 | R640 | 0.1R | 5% | Thick Film Resistor | 301010264 | YAGEO | RL0805JR-070R1L | SMD RES 0.1R-5%-1/8W;0805 | -55°C to 155°C | R0805
2 | U8,U90 | SN74LVC1G07DCKR |  | Logic | 310050079 | TI | SN74LVC1G07DCKR | SMD IC Logic;SC-70-5 | -40°C to 125°C | SC70_5
1 | U6 | SN74LVC1G08DCKR |  | Logic | 310050811 | Texas Instruments | SN74LVC1G08DCKR | SMD IC Logic;SC70-5 | -40°C to 125°C | SC70_5
1 | U46 | SN74LVC2G241DCUT |  | Logic | 310050078 | TI | SN74LVC2G241DCUR | SMD IC Logic;US8(8-VFSOP) | -40°C to 125°C | vssop8cr
2 | D6,D7 | TLVH431AIDBZR |  | Specific IC | 310031702 | TI | TLVH431AIDBZR | SMD IC PMIC; SOT23-3 | -40°C to 85°C | sot95p240x120-3n
1 | U5 | TPD12S016RKTR |  | HDMI Companion Chip | 310070571 | TI | TPD12S016RKTR | SMD IC Interface;UQFN-24 | -40°C to 85°C | uqfn24_0d4_4x2x0_55mm
1 | U48 | TPS2051BDGNR |  | Power Switch | 310030211 | TI | TPS2051BDGNR | SMD IC PMIC;MSOP-8 | -40°C to 125°C | SOP8_1FH
1 | U10 | TPS3808G33DBVR |  | Monitor | 310031703 | Texas Instruments | TPS3808G33DBVR | SMD IC PMIC;5.3V SOT23-6 | -40°C to 125°C | SOT23_6
1 | U1 | TPS51200DRCR |  | Specific IC | 310031699 | Texas Instruments | TPS51200DRCR | SMD IC PMIC;10-VSON | -40°C to 85°C | VSON50P300X300X100-11N
1 | J33 | U.FL-R-SMT-1(10) |  | RF CONNECTOR | 320111077 | HRS | U.FL-R-SMT-1(10） | SMD U-FL Female CONN-Gold;3P-L2.6*W2.6*H1.25mm | -40°C to 90°C | ANT3S_26X26
1 | J41 | UB11123-4H9-4F |  | USB Connector | 320010075 | Foxconn | UB11123-4H9-4F | DIP USB A TYPE Female;4P-2.0-90D | -55°C to 85°C | usb_a_sh
1 | L30 | 4.7uH | 1.4A | Power Inductor | 303010293 | TDK | VLS252012HBX-4R7M-1 | SMD Inductor 4.7uH-20%-1.4A;L2.5*W2.0*1.2mm | -40°C to 105°C | L25X20
7 | L16,L17,L18,L19,L20,L21,L22 | 1uH | 3.6A | Inductor | 303011312 | Sunlord | WPN252012H1R0MT | SMD Inductor 1uH-20%-3.6A;L2.5*W2*1.2mm | -40°C to125°C | INDPW250X200X105N
1 | OSC1 | 32.768KHz |  | Oscillator | 306020621 | Interquip | 1651-L3273-BTBQYA | SMD Oscillator;32.768KHz-3.3V-30ppm;SMD-2520-4P-L2.5*W2.0*H0.95mm | -40°C to 85°C | X4S25X20
1 | X6 | 16.384MHz 10pF |  | Crystal | 306011046 | Interquip | 5ZAA16384102TFA5Q3 | SMD Crystal;16.384MHz-10pF-20ppm;SMD-2520-4P-L2.5*W2.0*H0.6mm | -40°C to 85°C | OSCCC250x200x60-4N
1 | X7 | 20MHz 18pF |  | Crystal | 306011047 | Interquip | 5ZAA20000181TFA2Q3 | SMD Crystal;20MHz-18pF-10ppm;SMD-2520-4P-L2.5*W2.0*H0.6mm | -40°C to 85°C | OSCCC250x200x60-4N
1 | X8 | 22.5792MHz 18pF |  | Crystal | 306011048 | Interquip | 5ZAA22579182TFA0Q3 | SMD Crystal;22.5792MHz-18pF-20ppm;SMD-2520-4P-L2.5*W2.0*H0.6mm | -40°C to 85°C | OSCCC250x200x60-4N
1 | X9 | 25MHz 18pF |  | Crystal | 306011049 | Interquip | 5ZAA25000182TFA0Q3 | SMD Crystal;25MHz-18pF-20ppm;SMD-2520-4P-L2.5*W2.0*H0.6mm | -40°C to 85°C | OSCCC250x200x60-4N
1 | U37 | AW-CM256SM |  | Wi-Fi Module | 317990667 | AzureWave | AW-CM256SM | SMD Combo Module;IEEE 802.11a/b/g/n/ac WIFI and Bluetooth 4.2,SDIO and UART Interface;LGA-44P-L12*W12*H1.7mm | -30°C to 85°C | WLBT90P1200X1200X160-47N
1 | J92 | B3B-ZR(LF)(SN) |  | Terminal Block | 320031246 | JST | B3B-ZR(LF)(SN) | DIP Female Header-Natural;3P-1.5mm | -25°C to 85°C | con3b35x60
2 | FB1,FB6 | 180R | 1.5A | Ferrite Bead | 303030701 | Murata | BLM18PG181SN1D | SMD Ferrite Bead 180R-1.5A;0603 | -55°C to 125°C | L0603
4 | C51,C52,C68,C463 | 15pF | 50V,NPO | Ceramic Capacitor | 302012582 | YAGEO | CC0402GRNPO9BN150 | SMD CAP Ceramic 15pF-50V-2%-NPO;0402 | -55°C to 125°C | C0402
1 | U14 | DP83867CRRGZR |  | ETH PHY | 310011319 | TI | DP83867CRRGZR | SMD IC PHY;10/100/1000 Ethernet Physical Layer Transceiver;VQFN-48 | 0°C to 70°C | qfn48_0d5_7x7mm
1 | U7 | EMMC16G-TB29-PZ90 |  | Memory | 310091085 | Kingston | EMMC16G-TB29-PZ90 | SMD IC Memory;16GB eMMC 5.1;VFBGA-153 | -25°C to 85°C | BGA153P5
1 | U13 | HD3SS3220RNHR |  | Type-C Controller | 310011318 | TI | HD3SS3220RNHR | SMD IC;10Gbps USB 3.1 Type-C 2:1 Mux with DRP Controller;VQFN-30 | 0°C to 70°C | wqfn30_0d4_4_5x2_5x0_8mm
1 | J37 | JTRJ45-4118NLF |  | RJ45 | 320140416 | LINK-PP | LPJG0801HBNL | DIP RJ45;1000M,Integrated Magnetics,G/Y 2 LEDs,Right Angle;16P-21.25*15.93*13.3mm | 0°C to 70°C | RJ45_MTCONN_JTRJ45-4118NLF
1 | J90 | MCTF-0606 |  | Card Connector | 320090376 | MTCONN | MCTF-0606 | SMD Micro SD Card Holder;With Detect Switch;13P-15.25*14.05mm | -25°C to 85°C | SD_HSF-COMPLIANT_MCTF-0606
2 | U91,U92 | PCMF2HDMI2SZ |  | Filter | 310990882 | Nexperia | PCMF2HDMI2SZ | SMD IC;Common-mode EMI filter for 2 differential channels with ESD protection;WLCSP-10 | -40°C to 85°C | WLCSP10C40p3x4_117x157x60N
2 | U88,U89 | PCMF2USB30Z |  | Common Mode Inductor | 310990881 | Nexperia | PCMF2USB30Z | SMD IC;Common-mode EMI filter for 2 differential channels with ESD protection;WLCSP-10 | -40°C to 85°C | WLCSP10C40p3x4_117x157x60N
1 | R658 | 36.5K | 1% | Thick Film Resistor | 301013074 | YAGEO | RC0402FR-0736K5L | SMD RES 36.5K-1%-1/16W;0402 | -55°C to 155°C | R0402
1 | R167 | 5.76K | 1% | Thick Film Resistor | 301013075 | YAGEO | RC0402FR-075K76L | SMD RES 5.76K-1%-1/16W;0402 | -55°C to 155°C | R0402
1 | R32 | 909K | 1% | Thick Film Resistor | 301013073 | YAGEO | RC0402FR-07909KL | SMD RES-909K-1%-1/16W;0402 | -55°C to 155°C | R0402
1 | U78 | STMPE811QTR |  | IC | 310100427 | ST | STMPE811QTR | SMD IC ADC;1.8V-3.3V,SPI and IIC interface,Resistive Touchscreen Controller;QFN-16 | -40°C to 85°C | QFN50P300X300X100-17N
3 | U15,U16,U40 | TLV75801PDBVR |  | LDO | 310032000 | TI | TLV75801PDBVR | SMD IC PMIC;LDO-ADJ-500mA;SOT23-5 | -40°C to 125°C | SOT23_5
2 | U17,U18 | TPD4E05U06DQAR |  | ESD | 304060295 | TI | TPD4E05U06DQAR | SMD Diode Array ESD;4 Channel,6 Gbps,5.5V;USON-10 | -40°C to 125°C | uson10_0d5_2d5x1x0d5mm
1 | U12 | TPS2121RUXR |  | Power Mux | 310032001 | TI | TPS2121RUXR | SMD IC Priority Power MUX;2.8V-22V 4.5A;VQFN-12 | -40°C to 125°C | vqfn12_0d5_2x2_5x1mm
1 | U3 | TPS6590379ZWSR |  | Power Management | 310031999 | TI | TPS6590379ZWSR | SMD IC PMIC;3.8V-5V,7x DCDC,7x LDO;NFBGA-169 | -40°C to 85°C | bga169c80p13x13_1200x1200x140
1 | J42 | UBF31-0170 |  | USB Connector | 320010939 | MTCONN | UBF31-0170 | SMD+DIP USB Type-C;Female,Flat Insert;24P-10*9.95*3.16mm | -55°C to 85°C | USB_MTCONN_UBF31-0170
1 | X4 | 37.4MHz 12pF |  | Crystal | 306011050 | AEL | X37M400000S002 | SMD Crystal;37.4MHz-12pF-10ppm;SMD-1612-4P-L1.6*W1.2*H0.3mm | -10°C to 60°C | X4S16X12

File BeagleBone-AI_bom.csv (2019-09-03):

Item | Embest P/N | Part Type | QTY | Location | Manufacturer | Manufacture P/N | Description | Package
1 | 1001001000780-02 | PCB | 1 |  | AVL | BeagleBone AI PCB Rev A1(Add FCC/CE Logo) | 12 layers PCB,glossy white Soldermask,Black Silkscreen,Immersion gold,8636*54.61mm,BeagleBone AI PCB Rev A1 (Add FCC/CE Logo) | -
2 | 1002001100053 | MPU | 1 | U4 | TI | AM5729BABCXEAR | IC ARM Dual Cortex-A15 Microprocessor FCBGA(ABC)-760 SMD JEDEC TRAY | SMD
3 | 1002003100376 | Memory | 1 | U7 | kingston | EMMC16G-TB29-PZ90 | IC,Memory,16GB,EMMC,EMMC16G-TB29-PZ90 ,FBGA153,SMD | SMD
4 | 1002004100054 | Power Management | 1 | U48 | TI | TPS2051BDGN | IC,Current-Limited Power-distribution Switches,TPS2051BDGN,8-MSOP-PowerPad,SMD | 8-MSOP-PowerPad
5 | 1002004100287 | Power Management | 1 | U1 | Texas Instruments | TPS51200DRCR | IC CONV DDR DDR2 DDR3 10SON
6 | 1002004100348 | Power Management | 1 | U10 | Texas Instruments | TPS3808G33DBVR | IC VOLT SUPERVISOR 3.3V SOT23-6 | SOT23-6
7 | 1002004100351 | Memory | 2 | U2,U11 | KINGSTON | D2516EC4BXGGB-U | DRAM Chip DDR3L SDRAM 4G-Bit 256Mx16 1.35V 96-Pin F-BGA | 96-Pin F-BGA
8 | 1002004100399 | Power Management | 1 | U3 | TI | TPS6590379ZWSR | IC TPS659037 Power Management Unit (PMU) for Processor NFBGA-169 SMD | NFBGA-169
9 | 1002006100080 | LDO | 1 | U40 | SG MICRO | SGM2032-ADJYN5G/TR | IC,300mA Low Power Low Dropout RF Linear Regulators,SGM2032-ADJYN5G/TR,SOT23-5,SMD | SOT23-5
10 | 1002008100067 | Logic | 1 | U6 | TI | SN74LVC1G08DCKR | IC,SINGLE 2-INPUT POSITIVE-AND GATE,SN74LVC1G08DCKR,SOT-353,SMD | SOT-353
11 | 1002008100076 | Logic | 1 | U46 | TI | SN74LVC2G241DCUT | IC,Dual Buffer and Line Driver,SN74LVC2G241DCUT,US8,SMD | US8
12 | 1002008100087 | Logic | 2 | U8,U90 | TI | SN74LVC1G07DCKR | IC,SINGLE BUFFER/DRIVER WITH OPEN-DRAIN OUTPUT,SN74LVC1G07DCKR,SC-70,SMD | SC-70
13 | 1002008100180 | Logic | 1 | U12 | TI | TXS0104ERGYR | IC,TXS0104E 4-Bit Bidirectional Voltage-Level Translator For Open-Drain and Push-Pull Applications 14-QFN,SMD" | SMD
14 | 1002010100194 | Interface | 1 | U72 | Pericom | PI3USB3102ZLE | IC USB3.0&USB2.0 SWITCH 32TQFN
15 | 1002010100214 | Interface | 1 | U22 | Texas Instruments | TUSB322IRWBR | IC USB PORT CONTROL TYPE-C 12X2Q | 12X2Q
16 | 1002016100028 | Ethernet | 1 | U45 | ATHEROS | AR8035-AL1B | IC,Ultra low-power single RGMII Gigabit Ethernet PHY,AR8035,QFN-40,SMD | QFN-40
17 | 1002020100004 | Specific IC | 1 | U78 | ST | STMPE811QTR | IC,S-Touch? advanced resistive touchscreen controller with 8-bit GPIO expander,STMPE811QTR,QFN-16,SMD | QFN-16
18 | 1002020100331 | Specific IC | 2 | D6,D7 | TI | TLVH431CDBZR | IC,Low-Voltage Adjustable Precision Shunt Regulators | sot95p240x120-3n
19 | 1003001100001 | Thick film Resistor | 86 | R7,R10,R14,R15,R55,R70,R89,R90,R100,R108,R130,R145,R146,R148,R149,R152,R159,R183,R201,R385,R461,R542,R543,R576,R577,R578,R579,R580,R611,R614,R615,R616,R617,R618,R619,R620,R621,R622,R623,R624,R625,R626,R627,R628,R629,R630,R631,R632,R633,R634,R635,R636,R637,R638,R639,R642,R643,R644,R645,R646,R652,R653,R662,R663,R664,R665,R666,R667,R668,R669,R680,R681,R682,R683,R684,R685,R686,R687,R688,R694,R695,R696,R697,R702,R706,R707 | YAGEO | RC0402JR-070RL | RES,0R,+/-5%,1/16W,SMD0402 | 402
20 | 1003001100004 | Thick film Resistor | 1 | R84 | YAGEO | RC0402FR-0710RL | RES,10R,+/-1%,1/16W,SMD0402 | 402
21 | 1003001100007 | Thick film Resistor | 9 | R92,R93,R94,R95,R96,R97,R199,R200,R202 | YAGEO | RC0402JR-0722RL | RES,22R,+/-5%,1/16W,SMD0402 | 402
22 | 1003001100010 | Thick film Resistor | 21 | R333,R334,R336,R337,R458,R459,R460,R462,R464,R466,R469,R470,R581,R582,R583,R584,R585,R607,R608,R609,R610 | YAGEO | RC0402JR-0733RL | RES,33R,+/-5%,1/16W,SMD0402 | 402
23 | 1003001100015 | Thick film Resistor | 10 | R26,R29,R468,R472,R473,R474,R476,R477,R479,R480 | YAGEO | RC0402FR-0749R9L | RES,49R9,+/-1%,1/16W,SMD0402 | 402
24 | 1003001100019 | Thick film Resistor | 1 | R294 | YAGEO | RC0402FR-07100RL | RES,100R,+/-1%,1/16W,SMD0402,ALT_CODE:15052701 | 402
25 | 1003001100020 | Thick film Resistor | 2 | R83,R660 | YAGEO | RC0402JR-07100RL | RES,100R,+/-5%,1/16W,SMD0402 | 402
26 | 1003001100025 | Thick film Resistor | 2 | R589,R595 | YAGEO | RC0402JR-07220RL | RES,220R,+/-5%,1/16W,SMD0402 | 402
27 | 1003001100026 | Thick film Resistor | 2 | R22,R88 | YAGEO | RC0402FR-07240RL | RES,240R,+/-1%,1/16W,SMD0402 | 402
28 | 1003001100034 | Thick film Resistor | 1 | R457 | YAGEO | RC0402FR-071KL | RES,1K,+/-1%,1/16W,SMD0402 | 402
29 | 1003001100035 | Thick film Resistor | 19 | R147,R150,R588,R590,R591,R592,R593,R594,R670,R671,R672,R673,R674,R675,R676,R677,R678,R679,R701 | YAGEO | RC0402JR-071KL | RES,1K,+/-5%,1/16W,SMD0402 | 402
30 | 1003001100038 | Thick film Resistor | 1 | R134 | YAGEO | RC0402JR-071K5L | RES,1K5,+/-5%,1/16W,SMD0402 | 402
31 | 1003001100046 | Thick film Resistor | 1 | R551 | YAGEO | RC0402JR-072K2L | RES,2K2,+/-5%,1/16W,SMD0402 | 402
32 | 1003001100047 | Thick film Resistor | 1 | R465 | YAGEO | RC0402FR-072K37L | RES,2K37,+/-1%,1/16W,SMD0402 | 402
33 | 1003001100057 | Thick film Resistor | 6 | R180,R189,R192,R193,R194,R554 | YAGEO | RC0402JR-074K7L | RES,4K7,+/-5%,1/16W,SMD0402 | 402
34 | 1003001100071 | Thick film Resistor | 32 | R1,R2,R13,R86,R338,R409,R418,R419,R420,R422,R423,R455,R475,R481,R482,R483,R485,R487,R488,R489,R491,R516,R530,R531,R537,R561,R562,R563,R564,R565,R704,R705 | YAGEO | RC0402FR-0710KL | RES,10K,+/-1%,1/16W,SMD0402 | 402
35 | 1003001100072 | Thick film Resistor | 54 | R4,R18,R19,R20,R24,R27,R54,R74,R82,R98,R99,R101,R102,R103,R104,R107,R112,R113,R119,R121,R124,R139,R155,R157,R169,R174,R175,R176,R177,R178,R179,R184,R185,R186,R188,R493,R541,R552,R566,R567,R572,R596,R598,R599,R600,R601,R602,R603,R604,R605,R606,R661,R690,R691 | YAGEO | RC0402JR-0710KL | RES,10K,+/-5%,1/16W,SMD0402 | 402
36 | 1003001100083 | Thick film Resistor | 1 | R58 | YAGEO | RC0402FR-0720KL | RES,20K,+/-1%,1/16W,SMD0402 | 402
37 | 1003001100099 | Thick film Resistor | 2 | R17,R91 | YAGEO | RC0402FR-0740K2L | RES,40K2,+/-1%,1/16W,SMD0402 | 402
38 | 1003001100107 | Thick film Resistor | 1 | R658 | YAGEO | RC0402FR-0752K3L | RES,52K3,+/-1%,1/16W,SMD0402 | 402
39 | 1003001100119 | Thick film Resistor | 13 | R3,R44,R168,R173,R387,R389,R390,R392,R553,R571,R689,R700,J92（ PIN1与PIN2之间） | YAGEO | RC0402JR-07100KL | RES,100K,+/-5%,1/16W,SMD0402 | 402
40 | 1003001100120 | Thick film Resistor | 2 | R656,R659 | YAGEO | RC0402FR-07100KL | RES,100K,+/-1%,1/16W,SMD0402 | 402
41 | 1003001100130 | Thick film Resistor | 2 | R545,R546 | YAGEO | RC0402JR-07200KL | RES,200K,+/-5%,1/16W,SMD0402 | 402
42 | 1003001100154 | Thick film Resistor | 2 | R11,R12 | YAGEO | RC0402JR-071ML | RES,1M,+/-5%,1/16W,SMD0402 | 402
43 | 1003001100451 | Thick film Resistor | 1 | R640 | Yageo | RL0805JR-070R1L | RES,0R1,+/-5%,1/8W,SMD0805 | 805
44 | 1003001100518 | Thick film Resistor | 25 | R25,R30,R31,R33,R34,R36,R37,R39,R40,R42,R43,R123,R125,R126,R128,R129,R131,R132,R136,R137,R140,R142,R143,R160,R161 | YAGEO | RC0402FR-0747RL | RES,47R,+/-1%,1/16W,SMD0402 | 0402
45 | 1003001100565 | Thick film Resistor | 1 | R657 | YAGEO | RC0402FR-0780K6L | RES,80K6,+/-1%,1/16W,SMD0402 | 0402
46 | 1003001100576 | Thick film Resistor | 2 | R9,R85 | YAGEO | RC0402FR-07499RL | RES,499R,+/-1%,1/16W,SMD0402 | 0402
47 | 1003001100645 | Thick film Resistor | 1 | R57 | YAGEO | RC0402FR-0718KL | RES,18K,+/-1%,1/16W,SMD0402 | 402
48 | 1003001101493 | Thick film Resistor | 1 | R540 | YAGEO | RC0402FR-07909KL | RES,909K,+/-1%,1/16W,SMD0402 | 0402
49 | 1004001100005 | Ceramic Capacitor | 1 | C92 | MURATA | GRM1555C1H100JA01D | CAP,10PF,+/-5%,C0G,50V,SMD0402 | 402
50 | 1004001100011 | Ceramic Capacitor | 2 | C334,C337 | MURATA | GRM1555C1H220JA01D | CAP,22PF,+/-5%,C0G,50V,SMD0402 | 402
51 | 1004001100030 | Ceramic Capacitor | 2 | C1,C462 | MURATA | GRM155R71H102KA01D | CAP,1NF,+/-10%,X7R,50V,SMD0402 | 402
52 | 1004001100039 | Ceramic Capacitor | 96 | C9,C10,C11,C17,C18,C19,C22,C23,C24,C25,C36,C40,C79,C95,C97,C100,C101,C102,C103,C104,C118,C119,C122,C125,C131,C136,C138,C139,C140,C141,C145,C146,C148,C154,C155,C158,C162,C165,C166,C171,C174,C175,C178,C181,C182,C185,C186,C187,C189,C190,C193,C197,C199,C201,C202,C203,C205,C206,C207,C209,C210,C211,C212,C213,C218,C220,C221,C222,C223,C224,C227,C230,C231,C232,C233,C234,C235,C236,C237,C238,C242,C245,C255,C256,C257,C258,C259,C261,C262,C269,C270,C271,C272,C299,C483,C494 | MURATA | GRM155R71C103KA01D | CAP,10NF,+/-10%,X7R,16V,SMD0402 | 402
53 | 1004001100047 | Ceramic Capacitor | 60 | C5,C6,C8,C20,C35,C41,C42,C49,C60,C61,C69,C80,C81,C87,C88,C98,C99,C123,C143,C144,C147,C149,C153,C159,C163,C184,C225,C226,C281,C285,C286,C320,C321,C325,C327,C335,C336,C340,C345,C347,C348,C350,C351,C352,C353,C439,C440,C441,C443,C444,C445,C446,C457,C466,C472,C491,C492,C496,C497,C498 | MURATA | GRM155R71C104KA88D | CAP,100NF(0.1uf),+/-10%,X7R,16V,SMD0402 | 402
54 | 1004001100057 | Ceramic Capacitor | 22 | C106,C107,C108,C109,C179,C204,C214,C254,C260,C273,C274,C275,C276,C277,C279,C283,C339,C346,C480,C489,C490,C495 | MURATA | GRM155R61A105KE15D | CAP,1UF,+/-10%,X5R,10V,SMD0402 | 402
55 | 1004001100058 | Ceramic Capacitor | 1 | C216 | MURATA | GRM155R61C105KA12D | CAP,1UF,+/-10%,X5R,16V,SMD0402 | 402
56 | 1004001100059 | Ceramic Capacitor | 9 | C38,C43,C117,C121,C133,C134,C151,C152,C157 | MURATA | GRM155R60J225ME15D | CAP,2.2UF,+/-20%,X5R,6.3V,SMD0402 | 402
57 | 1004001100124 | Ceramic Capacitor | 6 | C126,C164,C169,C172,C278,C282 | MURATA | GRM188R61C225KE15D | CAP,2.2UF,+/-10%,X5R,16V,SMD0603 | 603
58 | 1004001100126 | Ceramic Capacitor | 3 | C2,C3,C464 | MURATA | GRM188R61A475KE15D | CAP,4.7UF,+/-10%,X5R,10V,SMD0603,Alt_Code:15051801 | 603
59 | 1004001100127 | Ceramic Capacitor | 11 | C114,C115,C127,C128,C132,C156,C194,C195,C196,C442,C456 | MURATA | GRM188R61C475KAAJD | CAP,4.7UF,+/-10%,X5R,16V,SMD0603 | 603
60 | 1004001100129 | Ceramic Capacitor | 23 | C4,C7,C37,C89,C90,C91,C113,C116,C120,C124,C130,C161,C170,C180,C198,C208,C291,C292,C295,C300,C344,C349,C461 | MURATA | GRM188R61A106KE69D | CAP,10UF,+/-10%,X5R,10V,SMD0603 | 603
61 | 1004001100130 | Ceramic Capacitor | 3 | C39,C96,C188 | MURATA | GRM188R60J226MEA0D | CAP,22UF,+/-20%,X5R,6.3V,SMD0603 | 603
62 | 1004001100164 | Ceramic Capacitor | 15 | C12,C26,C93,C94,C105,C111,C192,C263,C264,C265,C266,C293,C294,C297,C298 | MURATA | GRM21BR60J476ME15L | CAP,47UF,+/-20%,X5R,6.3V,SMD0805 | 805
63 | 1004001100185 | Ceramic Capacitor | 1 | C326 | MURATA | GRM32ER61A476ME20L | CAP,47UF,+/-20%,X5R,10V,SMD1210 | 1210
64 | 1004001100198 | Ceramic Capacitor | 2 | C481,C482 | MURATA | GRM32ER60J107ME20L | CAP,100UF,+/-20%,X5R,6.3V,SMD1210,1000pcs/Reel | 1210
65 | 1004001100239 | Ceramic Capacitor | 4 | C13,C14,C15,C16 | MURATA | GRM1555C1H240JA01D | CAP,24pF,+/-5%,C0G,50V,SMD0402 | 402
66 | 1004001100311 | Ceramic Capacitor | 1 | C58 | MURATA | GRM188R61A226ME15D | CAP, CERM, 22uF, 10V, +/-20%, X5R, 0603 | 603
67 | 1004001100319 | Ceramic Capacitor | 8 | C51,C52,C68,C338,C341,C342,C343,C463 | MURATA | GRM1555C1H150GA01D | CAP,15pF,+/-2%,C0G,50V,SMD0402 | 402
68 | 1004001100345 | Ceramic Capacitor | 10 | C110,C112,C168,C176,C177,C183,C200,C215,C217,C296 | Yageo | CC0402MRX5R5BB106 | CAP,10UF,+/-20%,X5R,6.3V,SMD0402 | 0402
69 | 1004001100401 | Ceramic Capacitor | 1 | C268 | MURATA | GRM1555C1H1R5CA01D | Cap Ceramic 1.5pF, +-0.25pF, 50V, C0G, 0402 | 0402
70 | 1005001100194 | Inductor | 7 | L16,L17,L18,L19,L20,L21,L22 | Gausstek | DI20A102M1U | Inductor,1uH,+/-20%,Ir=2.2A,Is=3.1,0.085ohm,SMD,2.5*2.0*1mm | SMD
71 | 1005004100057 | Inductor | 1 | L30 | TDK | VLS252012ET-4R7M | Power Inductor,Magnetic shielded,4.7uH,1.05A,0.338ohm,2.5x2.0x1.2mm,SMD | 2520
72 | 1005004100062 | Inductor | 1 | L15 | SUMIDA | CDRH2D18/HPNP-4R7NC | Power Inductor,Magnetic shielded,4.7uH,1.2A,0.14ohm,3X3X1.8mm,SMD | 3x3mm
73 | 1005004100077 | Inductor | 2 | L1,L2 | GAUSSTEK | SP04O203M1U | Power Inductor,Magnetic shielded,1uH,idc4.5A,27mohm,4.3x4.0x2.0mm,20%,SMD,TR | 4.3x4.0x2.0mm
74 | 1005005100012 | Ferrite Bead | 3 | FB2,FB3,FB6 | MURATA | BLM18PG181SN1D | Ferrite Bead,180ohm@100MHz,+/-25%,1500mA,0.09ohm,SMD0603 | 603
75 | 1005005100058 | Ferrite Bead | 1 | FB5 | MURATA | BLM15PD121SN1D | Ferrite Bead,120ohm@100MHz,+/-25%,1300mA,0.09ohm,SMD0402 | 402
76 | 1006001100015 | LED | 6 | D1,D2,D3,D4,D5,D8 | EVERLIGHT | 19-217/G7C-AN1P2/3T | LED,Super Yellow Green,Water Clear,20mA,SMD0603, 569.5~577.5nm | 603
77 | 1006002100003 | Diode | 1 | D77 | DIODES | 1N5819HW-7-F | Diode,Schottky Diode,1N5819HW-7-F,40V,1A,SOD-123,SMD,-65~125,TR | SOD-123
78 | 1006002100006 | Diode | 2 | D81,D82 | DIODES | B360A-13-F | Diode,Schottky Diode,B360A-13-F,60V,3A,SMA,SMD | SMA
79 | 1006003100004 | Diode | 1 | Q19 | NXP | BAT54C,215 | Diode,Schottky Barrier(Double) Diodes,BAT54C,215,30V,200mA,SOT-23,SMD | SOT-23
80 | 1006004100023 | Diode | 1 | D76 | ON | MM5Z5V1ST1G | Diode,Zener Diode,MM5Z5V1ST1G,5.1V,+/-2%,200 mW,SOD523,SMD,-65~155,AEC-Q101,TR | SOD-523
81 | 1006005100016 | Diode | 2 | D78,D79 | NXP | PRTR5V0U2X,215 | Diode,TVS,PRTR5V0U2X, 5.5V,SOT-143B,SMD | SOT-143B
82 | 1006005100019 | Diode | 5 | D21,D22,D23,D24,D25 | ON | ESD5B5.0ST1G | Diode,TVS,ESD5B5.0ST1G,5V,50W,SOD-523,SMD | SOD-523
83 | 1006005100089 | Diode | 2 | D46,D47 | TOPS | ESD0402-V05L | Diode,TVS,ESD0402-V05L, 5V, 0.1pF,0402,SMD | 402
84 | 1006012100001 | Transistor | 3 | Q1,Q4,Q14 | DIODES | MMBT2907A-7-F | Transistor,PNP,MMBT2907A-7-F,60V,600MA,SOT-23,SMD | SOT-23
85 | 1006014100031 | MOSFET | 1 | Q15 | FAIRCHILD | FDMA908PZ | MOSFET,Single P-Channel PowerTrench MOSFET,-12A, -12V,12.5 mohm,microFET2x2(8Pin),SMD | microFET2x2(8Pin)
86 | 1006015100003 | MOSFET | 1 | Q17 | FAIRCHILD | 2N7002 | Mosfet,N-Channel,2N7002,60V,115mA,SOT-23,SMD | SOT-23
87 | 1006015100009 | MOSFET | 1 | Q18 | ON | BSS138LT1G | Mosfet,N-Channel,BSS138LT1G,50V,0.2A,SOT-23,SMD | SOT-23
88 | 1006015100011 | MOSFET | 2 | T1,T2 | VISHAY | Si1902CDL-T1-GE3 | Mosfet,N-Channel,Si1902CDL-T1-GE3,20V,385mohm,1.5A,SOT-363,SMD | SOT-363
89 | 1008001100120 | Oscillator | 1 | OSC1 | INTERQUIP | 1651-L3273-BTBQYA | Oscillator,1651-L3273-BTBQYA,32.768KHz,+/-30ppm,3.3V,2520-4 pads,SMD | SMD
90 | 1008002100155 | Crystal | 1 | X4 | AEL | X37M400000S002 | XTAL,37.4MHz,12PF 1.6x1.2mm,,X37M400000S002, SMT TR (ftol;10ppm,ftmp:10ppm,ESR:60ohm(max),-10~60) | SMD
91 | 1008002100252 | Crystal | 1 | X6 | Interquip | 5ZAA16384102TFA5Q3 | Crystal,5ZAA16384102TFA5Q3,16.384MHZ,+/-20PPM,10PF,-40 to + 85°C,SMD2520-4 pad | SMD
92 | 1008002100253 | Crystal | 1 | X7 | Interquip | 5ZAA20000181TFA2Q3 | Crystal,5ZAA20000181TFA2Q3,20MHZ,+/-10PPM,18PF,-40 to + 85°C,SMD2520-4 pad | SMD
93 | 1008002100254 | Crystal | 1 | X8 | Interquip | 5ZAA22579182TFA0Q3 | Crystal,5ZAA22579182TFA0Q3,22.5792MHZ,+/-20PPM,18PF,-40 to + 85°C,SMD2520-4 pad | SMD
94 | 1008002100255 | Crystal | 1 | X9 | Interquip | 5ZAA25000202TFA0Q3 | Crystal,5ZAA25000202TFA0Q3,25MHZ,+/-20PPM,20PF,-40 to + 85°C,SMD2520-4 pad | SMD
95 | 1009002200073 | Pin Socket | 2 | P8,P9 | MTCONN | JT254F-D180-850-223-001-G | Connector,Pin Socket,Straight,Female,2x23Pin,2.54MM pitch,8.5,3.0,Gold Flash 1u, black,DIP | DIP
96 | 1009007100107 | USB Connector | 1 | J42 | MTCONN | UBF31-0170 | Connector,USB type C port,female,flat insert,SMT/THT; | SMT
97 | 1009007200069 | USB Connector | 1 | J41 | Foxcon | UB11123-4H9-4F | Connector,USB A port,4 Position,female,Right Angle,30u GXT Contact,black,DIP | DIP
98 | 1009008100005 | HDMI Connector | 1 | J91 | FCI | 10118241-001RLF | Connector,HDMI Receptacle, Type D, Right Angle,DIP+ SMT leg | SMD
99 | 1009014200068 | Terminal Block | 1 | J92 | JST | B3B-ZR(LF)(SN) | Connector, Wire-To-Board Top Entry, ZH Series, Through Hole, Header, 3PIN, 1.5 mm, Tin Plated Contacts | DIP
100 | 1009017100086 | Card Connector | 1 | J90 | MTCONN | MCTF-0606 | Connector,MicroSD Card CONN with detect switch,Gold Flash,Black,SMD | SMD
101 | 1009019100014 | RF Connector | 1 | J33 | HIROSE | U.FL-R-SMT-1(10) | Connector,Coaxial Connector,U.FL-R-SMT-1,6GHZ,SMD,TR U.FL-R-SMT-1(10) Packing for2,500 pcs/reel or U.FL-R-SMT-1(40) Packing for4,000 pcs/reel or U.FL-R-SMT(01) Packing for 1000pcs/pack | SMD
102 | 1009023100008 | Modular Jack | 1 | J37 | MTCONN | JTRJ45-4118NLF | Connector,RJ45 Jack with integrated magnetics and G/(G+Y) leds,Right Angle,1000M,Top contact,Gold Flash 6u,Black,21.35x15.95x13.54MM,DIP | DIP
103 | 1010001100030 | Tactile Switch | 2 | S1,S3 | C&K | KMR231GLFS | Switch,Tactile,300gf+/-50gf,black housing,black plunger,4.6*2.8*1.9MM,SMD | KMR2
104 | 1013002100020 | Filter | 2 | FL1,FL2 | Murata | NFM21PC474R1C3D | CAP Feedthru 0.47UF 20% 16V 0805 | SMD
105 | 1013002100028 | Filter | 2 | U88,U89 | NXP | PCMF2USB30Z | Common-mode EMI filter for differential channels with integrated ESD protection
106 | 1013002100030 | Filter | 2 | U91,U92 | Nexperia | PCMF2HDMI2S | EMI filter with integrated ElectroStatic Discharge protection two differential channels,PCMF2HDMI2S,SMD | SMD
107 | 1105002000038 | Wi-fi Module | 1 | U37 | AzureWave | AW-CM256SM | IEEE 802.11 a/b/g/n/ac WIFI with Bluetooth 4.2 combo SDIO and UART Stamp Module,AW-CM256SM,SMD

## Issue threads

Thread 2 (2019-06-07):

SW: need Tensorflow/Python integration with TIDL

jadonk, 2019-06-07:

jadonk, 2019-09-17:
Tensorflow Lite support is on the roadmap for 2020Q1.

PrashantDandriyal, 2020-03-18:
With the release of [TIDL 3.15.1](http://downloads.ti.com/processor-sdk-linux/esd/docs/latest/linux/Foundational_Components/Machine_Learning/tidl.html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), TensorFlow and TensorFlow Lite has been added to the _supported frameworks_ among _Caffe, TensorFlow Lite and ONNX_ although, **not yet** a verified model like the _Jacinto11, MobileNetV2 ,etc_.

The _model import_ feature of TIDL there is provides constraint on the supported operators and layers. Irrespective of the framework, the supported layers are
```Convolution Layer
Pooling Layer (Average and Max Pooling)
ReLU Layer
Element Wise Layer (Add, Max, Product)
Inner Product Layer (Fully Connected Layer)
Soft Max Layer
Bias Layer
Deconvolution Layer
Concatenate layer
ArgMax Layer
Scale Layer
PReLU Layer
Batch Normalization layer
ReLU6 Layer
Crop layer
Slice layer
Flatten layer
Split Layer
Detection Output Layer
```

But for the supported operators, during the import process, some operators/layers are combined or converted into TIDL layers. For TensorFlow specifically, the supported operators are:

TensorFlow Operator | TIDL Layer
-- | --
Placeholder | TIDL_DataLayer
Conv2D | TIDL_ConvolutionLayer
DepthwiseConv2dNative | TIDL_ConvolutionLayer
BiasAdd | TIDL_BiasLayer
Add | TIDL_EltWiseLayer
Mul | TIDL_ScaleLayer
FusedBatchNorm | TIDL_BatchNormLayer
Relu | TIDL_ReLULayer
Relu6 | TIDL_ReLULayer
MaxPool | TIDL_PoolingLayer
AvgPool | TIDL_PoolingLayer
ConcatV2 | TIDL_ConcatLayer
Slice | TIDL_SliceLayer
Squeeze | See note below
Reshape | See note below
Softmax | TIDL_SoftMaxLayer
Pad | TIDL_PadLayer
Mean | TIDL_PoolingLayer

Whereas for TensorFlow Lite,
TensorFlow Operator	|TIDL Layer
--|--
Placeholder|	TIDL_DataLayer
CONV_2D	|TIDL_ConvolutionLayer
TRANSPOSE_CONV	|TIDL_Deconv2DLayer
DEPTHWISE_CONV_2D	|TIDL_ConvolutionLayer
ADD	|TIDL_EltWiseLayer
MUL	|TIDL_ScaleLayer
RELU	|TIDL_ReLULayer
RELU6	|TIDL_ReLULayer
MAX_POOL_2D	|TIDL_PoolingLayer
AVERAGE_POOL_2D	|TIDL_PoolingLayer
CONCATENATION	|TIDL_ConcatLayer
RESHAPE	|See note below
SOFTMAX	|TIDL_SoftMaxLayer
ARG_MAX	|TIDL_ArgMaxLayer
PAD	|TIDL_PadLayer
MEAN	|TIDL_PoolingLayer
FULLY_CONNECTED	|TIDL_InnerProductLayer

Note:
>“Reshape” and “Squeeze” are supported by being coalesced into other layers:
If “Reshape” immediately follows “Squeeze”, they both are coalesced into TIDL_FlattenLayer.
If “Reshape” immediately follows “AvgPool”, “Reshape” is coalesced into TIDL_PoolingLayer.
If “Reshape” immediately follows TIDL_InnerProductLayer, it is coalesced into TIDL_InnerProductLayer.

Source: [Official docs for TIDL: Foundational Components ](http://downloads.ti.com/processor-sdk-linux/esd/docs/latest/linux/Foundational_Components/Machine_Learning/tidl.html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)

matthewanderson23, 2020-04-28:
Any updates on whether TF Lite support is imminent?

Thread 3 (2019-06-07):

SW: need mainline WiFi/BT driver support

jadonk, 2019-06-07:
Should also include 4.14-ti/4.19-ti backports.

vlasov01, 2019-11-16:
I'd like to connect BBAI to connect to a BT speaker.
I'm wondering if there are any workarounds to use BT to accomplish this?

`sudo bluetoothctl
[bluetooth]# show
No default controller available
`

`sudo dmesg | egrep -i 'blue|firm'
[   50.217975] brcmfmac: brcmf_c_preinit_dcmds: Firmware version = wl0: Mar  1 2015 07:29:38 version 7.45.18 (r538002) FWID 01-6a2c8ad4
[   51.907105] Bluetooth: Core ver 2.22
[   51.907296] Bluetooth: HCI device and connection manager initialized
[   51.907335] Bluetooth: HCI socket layer initialized
[   51.907369] Bluetooth: L2CAP socket layer initialized
[   51.907460] Bluetooth: SCO socket layer initialized
[   51.940582] Bluetooth: Generic Bluetooth SDIO driver ver 0.1
[   63.455873] Bluetooth: BNEP (Ethernet Emulation) ver 1.3
[   63.455897] Bluetooth: BNEP filters: protocol multicast
[   63.455948] Bluetooth: BNEP socket layer initialized

`

nullr0ute, 2020-08-16:
Is the broadcom NVRAM file published somewhere?

sPyOpenSource, 2021-02-14:
I have the same problem with Bluetooth.

sPyOpenSource, 2021-02-14:
You need to compile and install overlay: https://github.com/beagleboard/BeagleBoard-DeviceTrees/blob/v4.19.x-ti-overlays/src/arm/am5729-beagleboneai.dts
Then download https://github.com/RPi-Distro/bluez-firmware/blob/master/broadcom/BCM4345C0.hcd put into /etc/firmware
```
hciattach /dev/ttyS5 bcm43xx 921600
sleep 3
hciattach /dev/ttyS5 bcm43xx 921600
```
Then after reboot everytime using
`btattach -B /de/ttyS5 -S 921600`

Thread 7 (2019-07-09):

Doc:  The SRM pin tables are a bit hard to navigate

MarkAYoder, 2019-07-09:
I've copied them to some Google Sheets to aid in navigation.
PRU Pins: https://docs.google.com/spreadsheets/d/19u2rtqVGChSOd0_8ZJj_E3XosuGBpWy7j633__siOvw/edit?usp=sharing
P8 Pins: https://docs.google.com/spreadsheets/d/1opaOLjF7_EDNCR3g5NiEILsJba8h5ZumSeBwOvD1-6Q/edit?usp=sharing
P9 Pins: https://docs.google.com/spreadsheets/d/12qkmnyM3qgxL-F6tBKBaA220u_hGWrLgVg9rrCykZ2Q/edit?usp=sharing

I can add them to the Wiki and to a pull request if you'd like.

--Mark

jadonk, 2019-07-14:
@MarkAYoder yes, please submit your improvements. @cwicks is working on the SRM with some help from @JohnThanks and @ErikWelsh.

MarkAYoder, 2019-07-16:
@cathywicks I don't see how to submit improvements to the Wiki.  I found the paths above easier to use than the tables in the wiki.  Maybe you could add the links to the Wiki.

--Mark

jadonk, 2019-07-17:
@MarkAYoder there should be an edit button you can use on the wiki pages.

cathywicks, 2019-07-17:
Hi Mark. I’ve heard we should go ahead and put the pin tables in a
scrolling chart. I’ll work on that by the weekend. I would love to link to
any chart folks have that is printable. Do you have one?

On Tue, Jul 16, 2019 at 11:04 PM Jason Kridner <notifications@github.com>
wrote:

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

MarkAYoder, 2019-07-17:
Cathy:
  I've copied the pin mux tables to Google Sheets.  They appear to be nicely printable.

PRU Pins: https://docs.google.com/spreadsheets/d/19u2rtqVGChSOd0_8ZJj_E3XosuGBpWy7j633__siOvw/edit?usp=sharing
P8 Pins: https://docs.google.com/spreadsheets/d/1opaOLjF7_EDNCR3g5NiEILsJba8h5ZumSeBwOvD1-6Q/edit?usp=sharing
P9 Pins: https://docs.google.com/spreadsheets/d/12qkmnyM3qgxL-F6tBKBaA220u_hGWrLgVg9rrCykZ2Q/edit?usp=sharing

The PRU pin table is missing the pr2 entries.

I don't know how the edit the wiki, so it looks like you'll have to include the links.

--Mark

cathywicks, 2019-07-17:
thanks Mark!  I can include the links on the SRM

On Wed, Jul 17, 2019 at 7:10 AM Mark A. Yoder <notifications@github.com>
wrote:

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

jadonk, 2019-09-18:
@cathywicks adding the links would be good. I've tried to make a "master sheet" at https://docs.google.com/spreadsheets/d/1fE-AsDZvJ-bBwzNBj1_sPDrutvEvsmARqFwvbw_HkrE/edit?usp=sharing

@MarkAYoder can you review the section 7 and section 8 header pin information?

MarkAYoder, 2019-09-20:
I see the spreadsheet, but I don't what is section 7 and 8.

silver2row, 2021-02-22:
Hello...please forgive me bringing up old times here but are the links good for P8 and P9 for the AI?

Seth

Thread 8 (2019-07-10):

Pin mapping for pr2 is missing

MarkAYoder, 2019-07-10:
In section 6.12.3 PRU-ICSS Pin Access there is a table for the pr1 mappings, but I don't see one for pr2.

jadonk, 2019-07-17:
@cathywicks ^^^

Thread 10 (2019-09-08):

Problems with input power muxing using Schottky ORing diodes?

jks-prv, 2019-09-08:
Thanks for recently adding the rev A1 design files, especially the schematic.

Are you guys sure about using Schottky ORing diodes (D81,82) for input multiplexing between the USB-C and cape power-in sources? There are a couple problems I can see.

Depending on current draw by the AI you might be exceeding the power dissipation of the diodes. Their Pd is spec'd at 850 mW and you'll hit that by putting only ~1.5A through them
(half of what the USB-C input is capable of). The BBB avoided this of course by using low-loss FET muxing inside the PMIC.

I ran some simulations of your Q15 PFET + B360A diode circuit and over the USB-C 5V power adapter voltage supply range spec of 4.75 - 5.5V you're not going to meet the VDD Vmin input spec on your USB-C CCL (TUSB322I U22). It's short about 0.2V depending on the Vf of the diodes. [Simulation results](http://kiwisdr.com/files/BBAI.2A.png) with AI drawing ~2A.

If it's late in the game to be making changes you might at least want to see if you can spec a better Schottky with lower Vf (e.g. SSB44). A much better solution would be to use something like a TPS2120 in place of the diodes.

jadonk, 2019-09-17:
Cape expansion only ever specified up to 500mA over SYS_VDD.

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

jadonk, 2019-09-18:
Providing a bit more margin would be a good update for rev A2.

jks-prv, 2019-09-20:
First, congrats on shipping rev A1 yesterday. I've ordered one and will test with my cape ([kiwisdr.com](http://kiwisdr.com)) which powers the BBB/G via P9-5,6 and is in turn fed with switched 5V from the PMIC via P9-7,8. So these issues are very important for my product if the AI is to be an effective performance upgrade.

> Cape expansion only ever specified up to 500mA over SYS_VDD [really SYS_5V]

Agreed, but that's not what I'm talking about. Please refer to this picture:
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
Powering the BBB from the cape via P9-5,6 (as an alternative to the DC-in jack) is allowed per SRM 8.6.2 "Expansion board external power". Those pins together allow 2A, so no problem powering the BBB plus 500mA of sequenced (switched) cape power on P9-7,8 going back out again. I use this arrangement because the DC-in jack on my cape has additional filtering compared to the DC-in jack on the BBB. But I still need power to my board to be sequenced by the PMIC so as not to damage the BBB. Hence I use P9-5,6 as BBB power-in and P9-7,8 as cape power-in. The AI supports this configuration so no problem.

(1) (2) As mentioned in the first post the D81,82 Schottky diodes may have heat dissipation and excessive voltage drop problems (relative to VDD Vmin spec of U22) depending on the total 5V current draw and Vf of the diodes. The PMIC, U48 and other downstream users of VDD_5V (including my cape) will have no problem with the diode Vdrop because they are all LDOs with low input Vmin. Points (1) and (2) are my main area of concern.

(3) This issue is just for completeness. I'd be surprised if it makes any difference to anyone. The BBB SRM allows for P9-5,6 to be bidirectional, i.e. if powered from the DC-in jack the cape can receive power on P9-5,6 (PMIC unswitched) in addition to P9-7,8 (switched). The AI precludes this configuration due to the unidirectional D82. Replacing D81,82 with MOSFET switching would solve this problem.

jadonk, 2019-09-26:
Can you propose a circuit?

jadonk, 2019-09-26:
Also, your pictures are fantastic. Can I use them in the documentation?

jks-prv, 2019-09-26:
I'm going to dead bug a TPS2120 in place of D81,82 and try it out. In Q9k on a reel from Mouser the part is US $0.86 which is a little pricey. But you can deduct the cost of the diodes from that. And also I'm sure you guys get better than distribution pricing from TI.

Sure, use/modify the pics as you wish. A .pdf and the OpenOffice .odg source are on http://kiwisdr.com/files/Schottky.[pdf,odg]

embedded-solutions, 2019-11-07:
I want to contribute to discussion with some measurements. I performed some simple tests to see the voltage drop on diode by measuring voltage on pins P9 7,8pins.

On the plot we can see complete boot sequence and voltage drop

1 - BBAI powered from lab power supply without load on pins 7,8
 (black - voltage on pins 5,6 | green - voltage on pins 7,8)
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

2 - BBAI powered from lab power supply with 500mA load on pins 7,8
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

3 - BBAI powered from USB C supply with 500mA load on pins 7,8
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

In the last case board does not boot at all.

buzmeg, 2020-05-07:
This should really have something like an "ideal diode" or a dual ideal diode like the LTC4413 (I'm sure TI has an equivalent somewhere) if there is no way to do this inside the PMIC.

jadonk, 2020-05-14:
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

buzmeg, 2020-06-27:
Seems like a lot of components just for an ideal diode, but, yeah, that should do.

However, I don't think you want to enable PRI mode.  You probably want simple "Pick the higher voltage" mode.

With the PR1 configuration, you can have unwanted switching around 4V if the TypeC_VBUS is struggling.  With "higher voltage" mode, the switching point is set by the stronger/higher of the two voltages and likely isn't at 4V.

For example, the system is drawing power from TypeC_VBUS which sinks below 4V because it can't keep up.  The TPS2121 switches over to VDD_CAPE_5V which releases the load on TypeC_VBUS.  At that point, TypeC_VBUS comes back up to above 4V and the TPS2121 switches back to it.  At which point, the problem starts again.

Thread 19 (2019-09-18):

HW: HDMI hotplug detection not working

jadonk, 2019-09-18:
End user HDMI feedback:

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

This will be fixed in rev A2.

For rev A1, you'll need to have the monitor plugged in when booting BeagleBone AI or manually set the resolution.

jadonk, 2020-05-14:
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

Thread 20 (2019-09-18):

HW: add extra DCAN

jadonk, 2019-09-18:
Feedback from Michel Catudal...

G19 and G20, which have DCAN1 and GPIO, should be brought to the headers.

jadonk, 2020-04-23:
Proposal to add those balls to P8.07 and P8.08.

jadonk, 2020-05-14:
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

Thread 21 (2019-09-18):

HW: wire mods required to enable JTAG

jadonk, 2019-09-18:
Got this message forwarded to me today about the board's JTAG:

Hi Bill

I finally manage how to use the Allegro Board Viewer.

It’s confirmed that the JTAG pins are shorted together. I’m not sure if they even connected to the SOC.

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

It looks like R199 and R200 are just connected together in this photo above. SOC -> R200 -> R199 -> SOC ( the red trace that has the letter JTAG_RTCK on it)

And the pins 9-11 on the JTAG connectors are directly connected to each other

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

So we can cut this trace, and the trace between R199 and R200, then blue wires to the R200 and R199. We only have to do 1 blue wire.

That will probably fixe it :-)

Best regards
Thanh

sgturner, 2019-10-03:
I someone able to pinpoint where R199 and R200 are on the PCB (since there are no R and C references on the silkscreen)?

dar-jan, 2019-10-03:
Stephen, you've right. PCB silkscreen without Names is hard to recognise. Resistors are near the sdcard corner (R199 at the corner and R200 first outside), see:
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
The pdf with PCB from documentation  (https://github.com/beagleboard/beaglebone-ai/blob/master/BeagleBone-AI_brd.pdf) presents only top side, without bottom...

sgturner, 2019-10-03:
Hi Dariusz,

Can you pinpoint on the below image?.  Thanks

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

dar-jan, 2019-10-03:
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
Pure uP JTAG signals appear on right side of resistors at your picture.

sgturner, 2019-10-07:
I believe I have JTAG working on the BB-AI.

1. I cut the trace joining JTAG_TCK and JTAG_RTCK here:

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

2. Unsoldered and resoldered R199 and R200.  Wired R200 to the JTAG header pin 11 (TCK).  Did not wire RTCK as it is not used by the XDS110 JTAG debugger that I'm using.  Soldered a 20 pin header (with pin 6 removed) to P2

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

```
[Start: Texas Instruments XDS110 USB Debug Probe]

Execute the command:

%ccs_base%/common/uscif/dbgjtag -f %boarddatafile% -rv -o -S integrity

[Result]

-----[Print the board config pathname(s)]------------------------------------

C:\Users\AUDIOS~1\AppData\Local\TEXASI~1\
    CCS\ccs910\0\0\BrdDat\testBoard.dat

-----[Print the reset-command software log-file]-----------------------------

This utility has selected a 100- or 510-class product.
This utility will load the adapter 'jioxds110.dll'.
The library build date was 'Aug 26 2019'.
The library build time was '13:34:49'.
The library package version is '8.3.0.00003'.
The library component version is '35.35.0.0'.
The controller does not use a programmable FPGA.
The controller has a version number of '5' (0x00000005).
The controller has an insertion length of '0' (0x00000000).
This utility will attempt to reset the controller.
This utility has successfully reset the controller.

-----[Print the reset-command hardware log-file]-----------------------------

The scan-path will be reset by toggling the JTAG TRST signal.
The controller is the XDS110 with USB interface.
The link from controller to target is direct (without cable).
The software is configured for XDS110 features.
The controller cannot monitor the value on the EMU[0] pin.
The controller cannot monitor the value on the EMU[1] pin.
The controller cannot control the timing on output pins.
The controller cannot control the timing on input pins.
The scan-path link-delay has been set to exactly '0' (0x0000).

-----[Perform the Integrity scan-test on the JTAG IR]------------------------

This test will use blocks of 64 32-bit words.
This test will be applied just once.

Do a test using 0xFFFFFFFF.
Scan tests: 1, skipped: 0, failed: 0
Do a test using 0x00000000.
Scan tests: 2, skipped: 0, failed: 0
Do a test using 0xFE03E0E2.
Scan tests: 3, skipped: 0, failed: 0
Do a test using 0x01FC1F1D.
Scan tests: 4, skipped: 0, failed: 0
Do a test using 0x5533CCAA.
Scan tests: 5, skipped: 0, failed: 0
Do a test using 0xAACC3355.
Scan tests: 6, skipped: 0, failed: 0
All of the values were scanned correctly.

The JTAG IR Integrity scan-test has succeeded.

-----[Perform the Integrity scan-test on the JTAG DR]------------------------

This test will use blocks of 64 32-bit words.
This test will be applied just once.

Do a test using 0xFFFFFFFF.
Scan tests: 1, skipped: 0, failed: 0
Do a test using 0x00000000.
Scan tests: 2, skipped: 0, failed: 0
Do a test using 0xFE03E0E2.
Scan tests: 3, skipped: 0, failed: 0
Do a test using 0x01FC1F1D.
Scan tests: 4, skipped: 0, failed: 0
Do a test using 0x5533CCAA.
Scan tests: 5, skipped: 0, failed: 0
Do a test using 0xAACC3355.
Scan tests: 6, skipped: 0, failed: 0
All of the values were scanned correctly.

The JTAG DR Integrity scan-test has succeeded.

[End: Texas Instruments XDS110 USB Debug Probe]
```

Next step is to find a GEL file for the BB-AI.  I note the latest release of TI Code Composer (v9.1.0) does not even have an AM5729 target

mgsb, 2019-11-06:
I would like to try this, too. Would you clarify for me what you did with R199 and R200? I don't understand what you mean by: "Unsoldered and resoldered R199 and R200."?

sgturner, 2019-11-06:
You can see what I did here:

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

I unsoldered R199 and R200 and then resoldered them to the left hand pad.  Only connected up R200 (TCK)

EnzoS1469, 2019-12-12:
Hi,
are above hw modifications valid for XDS560v2 JTAG debugger too ?
Specifically, I read that RTCK is not wired because  XDS110 JTAG debugger is not using it: do I need to wire in case of  XDS560v2 JTAG debugger ?

Last question: what are the impacts of these modifications ? Is any functionality limited/dropped ?

Thank you in advance,
Enzo

rsjdesouza, 2020-05-05:
Enzo,

I was able to work with my Blackhawk XDS560v2 but tied both signals so I could potentially achieve more stability and higher speeds. By using the TCK in the rising edge, I was able to reach up to 26MHz of TCK.

[BBAI_XDS560v2_test.txt](https://github.com/beagleboard/beaglebone-ai/files/4582007/BBAI_XDS560v2_test.txt)

I followed sgturner's procedure above with a slight difference.

As recommended by the section _Non-buffered JTAG Signal Termination_ of the [XDS Target Connection Design](https://software-dl.ti.com/ccs/esd/documents/xdsdebugprobes/emu_xds_target_connection_guide.html), I moved the 22Ω termination resistor (R200) of the TCK signal to be close to the emulation header, while I left the 22 (R199) of the RTCK as near the device as possible. I used very thin _wire wrap_ wire and some kapton tape to keep things in place.

Also, it is possible to cut the connection between pins 9 (RTCK) and 11 (TCK) of the emulation header after it was installed (that was my case). I used a small and very thin exacto knife to scrape between the pads of the header. Since the connection is in the bottom layer, I was very careful to not go too deep as I was afraid to cut other tracks on inner layers (I didn't verify this).

A picture of the modifications is shown below.

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

jadonk, 2020-05-14:
Rev A1/A1a:
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

Rev A2:
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

udayshukla14, 2020-10-22:
Hello,
I have recently purchased BB AI board. I have done the modifications as per the discussions on this page to support spectrum debugger.
After modifications, as soon as I connect the debugger adapter to the 20 pin connector on BB AI, it turns off automatically.
Has anyone faced similar issues ?
Please note, I have retained all 20 pins intact on the JTAG connector.

jostmp, 2022-05-20:
@udayshukla14 did you resolve the power off issue? I am seeing the same thing when I attach an XDS110 adapter to the board.

udayshukla14, 2022-05-21:
Sorry @jostmp , unfortunately I had to drop the project on BB since I could not resolve the issue

jostmp, 2022-05-27:
I found that with my XDS110 I could not use the 20 pin TI adapter. As soon as I connected to the board it powered down. Removing pin 6 as noted by @sgturner and using a 20 pin 50mil ARM debug cable connected directly to the board and XDS110 all works well.

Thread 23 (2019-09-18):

HW: Small I2C nvmem/eeprom for board identifier

jadonk, 2019-09-18:
Mainline open source software for TI components expect I2C EEPROM for a board identifier.

BeagleBone AI rev A1 uses the eMMC linear boot partition for board identifier and serial number information.

jadonk, 2020-05-14:
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

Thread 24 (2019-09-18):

HW: need pull-down on console uart RX line

jadonk, 2019-09-18:
@embest-tech said:

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

In assembly of rev A1a, R173 is removed and a pull-down is added on J92 pin 2.

For rev A2, the PCB will be modified to avoid the need for this unusual assembly step.

arashed31, 2019-09-20:
Can you try this with a pull up resistor on both side of U46? The standard is to keep a logic high on UART RX to indicate RS232 idle state.

VladAugust, 2019-10-10:
J92 pin 2 should be pulled up to VCC because

>  The standard is to keep a logic high on UART RX to indicate RS232 idle state.

sharifsonic, 2020-01-11:
hi,
how can we boot BB AI from sd card slot?
didnt find any instructions

DCelectronics, 2020-01-31:
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

I am not sure if the question relates to uart RX issue.
BeagleBone AI should automatically boot from the microSD once a valid OS image is found on the microSD.
Using the recommended Debian image, which at the time of this writing is found at:
https://debian.beagleboard.org/images/am57xx-debian-9.9-lxqt-armhf-2019-08-03-4gb.img.xz
on a quality microSD should work "right out of the burner".
If you are booting on microSD and you want to switch back to eMMC, perform a complete poweroff, remove the microSD from its holder, and power up the BeagleBone AI.
There is no BOOT button like the one found on BeagleBone Black.

sharifsonic, 2020-02-01:
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

Thanks, sorry for posting in the wrong place

DCelectronics, 2020-02-02:
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

No worries, you have to get started from somewhere.
I would much rather you get your question answered.

BerndMoe, 2020-03-05:
Hello,

I have a new BB AI Rev. A1 and it shutdown after overheat. Now I search for solving of the problem and I found this thread.
The head of this thread is "need pull-down". @embest-tech write that need a pull up, that is correct. When you connect the Rx with a resistor to Tx, so the Rx side receive the Tx without connection to a UART terminal. So you have design a hardware UART loop.
The most picture in the web and my BB AI have a resistor between pin 1 and 2, so we have a pull-down. Without UART connection exists no problems. Only when you after booting connect a UART the Rx side receive a failure byte automatically.

Have fun.

anvesh-design, 2020-03-06:
Hi,
i am new to beagle bone. i would like to know why there is a SN74LVC2G241 at UART0? why can't direct connection to Tx and Rx to header pins.

thank you,
anvesh

arashed31, 2020-03-06:
The IO pins on the processor can get damaged if you try to drive the pins
from an external device while the processor is off. So the buffer IC is
used to prevent that from occurring.

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

DCelectronics, 2020-03-15:
100% agree with "The IO pins on the processor can get damaged if you try to drive the pins from an external device while the processor is off. So the buffer IC is used to prevent that from occurring."

I have a BB AI Rev. A1
There is a resistor between pins J92-1 and J92-2.
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
Also. the resistor R173 is installed (populated on the board). The R173 is a "weak" pull up but the SN74LVC2G241 buffer (which has low output resistance driver) will assert whatever signal floats on pin U46-2 (the input of the buffer). They put a "weak" pull down resistor to prevent the pin from floating, and the GND net was convenient (they didn't have to route 3V3 net).
Beaglebone.org did the same thing for BB Black.

I have an FTDI UART cable, and I noticed that it has an internal pull-up RX resistor which addresses the concern regarding "The standard is to keep a logic high on UART RX to indicate RS232 idle state."

If you use an FTDI UART cable, I strongly recommand to plug the UART cable before powering  your BB and disconnect it after you power off your BB WHILE the UART cable is also connected to (and powered from) your host computer.

Regarding the overheating issue, I use a fan, and it is effective.

DCelectronics, 2020-03-17:
Suggested changes for revision A2 are:
Add a new 100K pull-up resistor (R?)
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
Make R173 "NI" (not installed).
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
The 100K resistor R? can be added next to U46, where one can conveniently route the VDD_3V3 net to the resistor.
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

jadonk, 2020-05-14:
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

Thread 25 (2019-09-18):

HW: position of microSD may impact existing case designs

jadonk, 2019-09-18:
Because the microSD card cage orients cards flipped from BeagleBone Black, some existing case designs may not allow for the microSD card to be inserted or removed as previously designed. For rev A2, we plan to move the microSD card cage 1mm closer to the microHDMI such that the travel path for the microSD card will be more similar to that on BeagleBone Black, despite the orientation change.

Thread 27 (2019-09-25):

input_opencv.so cannot be found

mzwtjp, 2019-09-25:
I followed the tidl introduction to build and run classification demo, but I get the folloeing.
(I have update/upgraded my environmment before trying to build this sample.)
Anything I am missing?

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

No input_opencv.so:

>debian@beaglebone:/var/lib/cloud9$ ls /usr/lib/mjpg-streamer/
>input_file.so  input_http.so  input_uvc.so  output_file.so  output_http.so  output_rtsp.so  output_udp.so

jadonk, 2019-09-26:
```
sudo apt update
sudo apt install -y mjpg-streamer-opencv-python
```

Closed 2019-09-26.

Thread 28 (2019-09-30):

SW: default /dev/spidev1.0 spi2 mosi/miso reversed compared to BBB

jks-prv, 2019-09-30:
I'm still researching this issue (I don't know yet where to look to find the '5729 spi driver code). But I thought I better mention it now and possibly save someone some grief in these early days.

I have the AI spi2 working using my own dts derived from am5729-beagleboneai-roboticscape.dts.
When in master mode the BBB defines spi0 as:
```
P9.17 = spi0_cs0
P9.18 = spi0_d1(mosi)
P9.21 = spi0_d0(miso)
P9.22 = spi0_sclk
```
BBAI defines spi2 as:
```
P9.17a = spi2_cs0
P9.18a = spi2_d0
P9.21b = spi2_d1
P9.22b = spi2_sclk
```
Yes, d[01] are reversed w.r.t the P9 pins. But this is okay. There are new bits in the '5729 spi controller to assign the I/O role of d[01] to be whatever you want (i.e. it's no longer fixed like it was in the '3359).

The problem is that the default when you open /dev/spidev1.0 seems to be
```
P9.18a = spi2_d0(miso)
P9.21b = spi2_d1(mosi)
```
i.e. you get output on P9.21 which is the opposite of the BBB behavior (output on P9.18)
Everthing else about spi2 is fine: cs0 and sclk are correct, I can change speeds and word length etc.

I wrote a user-land program to mmap() the spi2 dev regs. For AM572x TRM rev/K the relevant pages are:
- 24.4.2.1 page 5930 describes that the spi2_d[01] I/O role is determined by MCSPI_CHxCONF bits IS, DPE1 and DPE0
- 24.4.4.1 page 5942 block diagram shows nicely how these bits control the interface pins
- Table 24-333 page 5980 describes the MCSPI_CHxCONF reg

The documented reg reset value from above is `IS,DPE[01]=110` which is `spi2_d[01]=mosi,miso` which is correct and compatible with BBB. However before even opening /dev/spidev1.0 I observe `IS,DPE[01]=001` which is the exact opposite (`spi2_d[01]=miso,mosi`). I can force the bits to `=110`, but after an open or ioctl on /dev/spidev1.0 the bits go back to `=001`. So driver software someplace is definitely setting them this way.

From show-pins.pl:
```
P9.22b                   240  A26 0 fast rx  up  spi2_sclk        kiwisdr (cape_pins_kiwi)
P9.21b                   241  B22 0 fast rx  up  spi2_d1          kiwisdr (cape_pins_kiwi)
P9.18a                   242  G17 0 fast rx  up  spi2_d0          kiwisdr (cape_pins_kiwi)
P9.17a                   243  B24 0 fast     up  spi2_cs0         kiwisdr (cape_pins_kiwi)

```

In the .dts for d[01] I've tried various combinations of PIN_INPUT and PIN_OUTPUT in the DRA7XX_CORE_IOPAD(). It doesn't make any difference. I was hoping the driver might pay attention to those in setting the MCSPI_CHxCONF bits.

jks-prv, 2019-10-01:
Found the solution. Simply add `ti,pindir-d0-out-d1-in` to your .dts file:
```
&mcspi2 {
	#address-cells = <1>;
	#size-cells = <0>;
	status = "okay";
	ti,pindir-d0-out-d1-in;
...
```

Jayasudhaa, 2020-08-04:
Hi,

i am struggling to configuring spi on beagle bone AI.
how can i do it?

juvinski, 2021-01-05:
Thanks man,  I was strugling and loosing until I found your post :+1:
:clinking_glasses:

Closed 2019-10-01.

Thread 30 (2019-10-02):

ALG format?

andy-cruey, 2019-10-02:
Could someone please export the PCB in .alg format to make it easy to import into Altium Designer?

jadonk, 2020-05-14:
Is that an option in Allegro? Can you tell me where to find it?

andy-cruey, 2020-05-15:
I've not used allegro in a few years. The .alg used to be their version of saving the board file in ascii format. It was fairly simple to do a save as and choose ascii format xxxx.alg. Maybe they changed it since it made it much easier to import into Altium?

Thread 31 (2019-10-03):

PCB in PADS format

sgturner, 2019-10-03:
Is it possible to get the PCB in a PADS PCB compatible file (.ASC)?
thanks

jadonk, 2020-04-23:
Can you tell me where to export that in Allegro?

mkjel, 2020-05-07:
were you able to export the layout?

jadonk, 2020-05-14:
No one told me what to extract from Allegro. I'm not an allegro expert, but I do have Allegro.

mkjel, 2020-05-14:
Feel free to call me at 801 662-9243 – regards Mike

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

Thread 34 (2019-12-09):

Cortex-M4 sample code

reneherrero, 2019-12-09:
There's a lot of focus on the AI pieces of this board, but I find the 2x dual Cortex-M4 co-processors aren't getting the attention they deserve.

To anyone possibly sharing my sentiment, here's the closest I've been able to find:
* The Processor SDK for Linux: http://software-dl.ti.com/processor-sdk-linux/esd/AM57X/latest/index_FDS.html
* A demo project in Rust using the M4s and mailbox on the X15: https://github.com/cambridgeconsultants/rust-beagleboardx15-demo

Hope this helps

silver2row, 2020-01-13:
Hello,

Nice!

Seth

PrashantDandriyal, 2020-03-21:
The Processor SDK 3.15 for the AM572x can be found here : http://downloads.ti.com/processor-sdk-linux/esd/docs/latest/linux/Foundational_Components/Machine_Learning/tidl.html

 The following snippets help in highlighting the role of the A15 processors, although not in the form of a pseudocode or sample codes.

* In the software stack, as can be summarised in the figure:
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

In cases when user uses TIDL + DSPs or alternatively TIDL + EVEs or a combination of both (TIDL + DSPs + EVEs), the software layers used are:
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

* Another use case of the A15 is to use it for maximum performance. TIDL supports network layer distribution among the (4 EVEs + 2DSPs) accelerators present in the AM572x processor. Among the recommended settings, it is mentioned:
>  _SoftMax layer_ is terminal layer it is advised to do SoftMax either on **A15** (in user space) or using DSP.

aditya-gumparthi, 2021-07-30:
hey @reneherrero did you find any more resources? c++ ? i'm in the same place today 😄

reneherrero, 2021-07-30:
This seems to be the only option: https://www.ti.com/tool/PROCESSOR-SDK-AM57X

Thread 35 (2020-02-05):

BeagleBone AI SPI Enable

Zeki411, 2020-02-05:
Hello, Everyone !
i am so brand new to BeagleBone AI (AM5729) and now i am trying to enable SPI on it. I have tried turn it on by adding some following line in uEnv.txt but it didn't work:

cmdline=coherent_pool=1M net.ifnames=0 quiet cape_universal=enable
uboot_overlay_addr4=/lib/firmware/BB-SPIDEV0-00A0.dtbo
uboot_overlay_addr5=/lib/firmware/BB-SPIDEV1-00A0.dtbo

Can anyone help me, pls ?

Lander-liu, 2020-03-21:
I met the same problem about uart ,so anyone help us?

silver2row, 2021-02-22:
Hello,

I think, and I am not affiliated at all except that I use their products, making a .dts file is a starter and then turning that into a .dtbo w/ the help of their scripts could be beneficial.

Seth

silver2row, 2021-03-18:
Hello Again,

Try here: https://groups.google.com/g/beagleboard/c/NFMZiBIPvno/m/2t_Oczx-AQAJ

Seth

Closed 2021-07-01.

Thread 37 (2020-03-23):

How to enable uart 1 on the beaglebone AI

Lander-liu, 2020-03-23:
here is the BB-UART1-00A0 Decompile file， I find the regester has some problem, so anyone can help?

/dts-v1/;

/ {
	compatible = "ti,beaglebone", "ti,beaglebone-black", "ti,beaglebone-green";
	part-number = "BB-UART1";
	version = "00A0";
	exclusive-use = "P9.24", "P9.26", "uart1";

	fragment@0 {
		target-path = [2f 00];

		__overlay__ {

			chosen {

				overlays {
					BB-UART1-00A0 = "Thu Aug  1 16:09:14 2019";
				};
			};
		};
	};

	fragment@1 {
		target = <0xffffffff>;

		__overlay__ {

			P9_24_pinmux {
				status = "enabled";
			};

			P9_26_pinmux {
				status = "enabled";
			};
		};
	};
/*
	fragment@1 {
		target = <0xffffffff>;

		__overlay__ {

			P9_24_pinmux {
				status = "disabled";
			};

			P9_26_pinmux {
				status = "disabled";
			};
		};
	};
*/
	fragment@2 {
		target = <0xffffffff>;

		__overlay__ {

			pinmux_bb_uart1_pins {
				pinctrl-single,pins = <0x184 0x20 0x180 0x20>;
				linux,phandle = <0x1>;
				phandle = <0x1>;
			};
		};
	};

/*
	fragment@2 {
		target = <0xffffffff>;

		__overlay__ {

			pinmux_bb_uart1_pins {
				pinctrl-single,pins = <0x184 0x8 0x180 0x28>;
				linux,phandle = <0x1>;
				phandle = <0x1>;
			};
		};
	};

*/

	fragment@3 {
		target = <0xffffffff>;

		__overlay__ {
			status = "okay";
			pinctrl-names = "default";
			pinctrl-0 = <0x1>;
		};
	};

	__symbols__ {
		bb_uart1_pins = "/fragment@2/__overlay__/pinmux_bb_uart1_pins";
	};

	__fixups__ {
		ocp = "/fragment@1:target:0";
		am33xx_pinmux = "/fragment@2:target:0";
		uart1 = "/fragment@3:target:0";
	};

	__local_fixups__ {

		fragment@3 {

			__overlay__ {
				pinctrl-0 = <0x0>;
			};
		};
	};
};

iahn0, 2020-04-24:
I think uart1 is dedicated to console for beagleboneAI. I had no problem for console. We were able to FDDI usb converter to debug slot(3pins).

If you are interested in, I was able to uart3  ttyS2 ( P9.22, P9.21) by adding the following part into custom.dtsam5729-beagleboneai-custom.dts . I also updated am5729-beagleboneai.dts file and compile to dtb files.  Copied to /boot/dtbs/
And you also need to clean up the second pins by deactivating pins.

Please refer to the resource the following link from element 14. It is very  helpful.
 I have used the basic .dts file from the following link. https://www.element14.com/community/community/project14/visionthing/blog/2019/11/16/beagleboard-ai-brick-recovery-procedure

This is my own way so you may want to change as you would like to do.

//Beginning section, defining pin header on external port
#define P9_21 (0x3400 + 4 * 241) // PID is 241 //0x37C4
#define P9_22a (0x3400 + 4 * 167) // PID is 167 //unused //0x369C
#define P9_22b (0x3400 + 4 * 240) // PID is 241 //0x37C0
//paste the following part
&uart3 {
 status = "okay";
 pinctrl-names = "default";
 pinctrl-0 = <&uart3_pins>;
};
&dra7_pmx_core {
 uart3_pins: uart3 {
  pinctrl-single,pins = <
   DRA7XX_CORE_IOPAD( P9_21, MUX_MODE1 ) // P9.21 uart3_txd
   DRA7XX_CORE_IOPAD( P9_22b, PIN_INPUT_PULLUP | MUX_MODE1) // P9.22b uart3_rxd
   DRA7XX_CORE_IOPAD( P9_22a, MUX_MODE15) // P9.22a driver_off //shared-pin
  >;
 };
};

Insuk

p.s. I also shared my tests and information on
https://groups.google.com/forum/embed/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.

iahn0, 2020-04-24:
From schematic diagram, it looks like P9.24 and P9.26 are belong to uart10 group.
And Header P9.26 pin is sharing with ball number E21 ( need to  set mode to uart10 rxd  ) and ball number AE2 (need to set mode 15 for deactivating it instead of gpio mode, I think ).

Physical address UART10 is 0x4AE2 B000.
In my beagle-AI, it was mapped to:  ttyS3 (aka ttyO3)
4ae2b000.serial/tty/ttyS3

I hope it is helpful.

paulwuertz, 2021-08-24:
> hi, I have the same problem. I need to use Uart10 as ttyS1. Please give me some ideas, what shoule i do.

I am quite a dummy for reloading device trees for pinmuxing myself, but I just made UART10 on pins P9.24 and P9.26a work ^^
Following this guide[1] and finding this overlay[2] on github I came up with this [file](https://github.com/beagleboard/beaglebone-ai/files/7042442/am5729-beagleboneai-custom.txt)  (should end with .dtb, but github only excepts .txt :P )

Follwing these steps from[1]:

```bash
cd ~ #(or wherever you want to clone the next line to)
git clone https://github.com/beagleboard/BeagleBoard-DeviceTrees -b v4.14.x-ti
nano BeagleBoard-DeviceTrees/src/arm/am5729-beagleboneai-custom.dts #(paste the dts file below)
cd ../../BeagleBoard-DeviceTrees
make src/arm/am5729-beagleboneai-custom.dtb
sudo cp src/arm/am5729-beagleboneai-custom.dtb /boot/dtbs
sudo nano /boot/uEnv.txt #(configure: dtb=am5729-beagleboneai-custom.dtb)
sudo reboot
```

where the `am5729-beagleboneai-custom.dts` is the file mentioned above.

Before reboot I looked at all devices under `/dev/tty`. After reboot there was one more `/dev/ttyO1`, and when I did `echo foobar > /dev/ttyO1` I saw some 9600,8N,1 communication on the line ^^

[1] https://www.element14.com/community/community/project14/visionthing/blog/2019/11/16/beagleboard-ai-brick-recovery-procedure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
[2] https://github.com/MalavPatel3501/BeagleBone-AI--mpBBAI-IO-Python-Library/blob/master/am5729-beagleboneai-mpcustom.dts

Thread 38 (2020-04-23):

HW: Possible cost reduction/simplification with single chip USB3 mux

jadonk, 2020-04-23:
Use TI HD3SS3220 instead of U22 (TI TUSB322IRWBR) and U72 (Pericom PI3USB3102ZLE) to save on size, cost, and complexity.

jadonk, 2020-05-14:
Rev A1:
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

Proposed Rev A2:
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

PrasanthElavarthi, 2020-07-26:
Are pin 12 and pin 22 of HD3SS3220 left floating? I cannot find a netlabel 3220_ID other than pin 12.

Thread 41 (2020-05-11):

HW: Possible wiring issue with the I2C on the PMIC

mwelling, 2020-05-11:
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

The I2C2 pins appear to be swapped at the PMIC.

jadonk, 2020-05-14:
The DVS should be at 0x12 on the PMIC I2C2. We don't seem to have a driver loaded to use it. I'm still researching if any software should be using it.

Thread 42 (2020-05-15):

HW: Adjust the eMMC pull-ups

jadonk, 2020-05-15:
I'm not sure if this is needed, but it is proposed for Rev A2:

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

DCelectronics, 2020-07-16:
According to the AM57xx Schematic Checklist, Section 2.12:
"For eMMC implementations, 47K-50K pull-up resistors are only needed on the first data signal (DAT0) and on the command signal. They are not required on the DAT7:DAT1 connections as these are provided within the eMMC device at start-up."
https://www.ti.com/lit/pdf/sprack7

According to the Kingston Embedded Multi-Media Card documentation for EMMC15G-TB29, page9:
"The eMMC device includes internal pull-ups for data lines DAT1-DAT7."
http://static6.arrow.com/aropdfconversion/600abac7089ab69d925e54c048b3013f15c7066d/kingston_emmc16g-tb29-pz90_2020-02-07_13-45-15.pdf

Thus, we can make R175 through R179, R184 and R185 "Not Installed".

We have the 22R (R202) series resistor on MMC2_CLK to eliminate possible signal reflections on the signal that can cause false clock transitions. However, I did  not confirm if R202 is placed as close to the processor as possible.

The VDD_EMMC is connected to 1V8 through R702 (0R), and 1V8 for I/O would support maximum data bus throughput of 400 MB/s (Mode HS400).

All these are consistent with other eMMC related reference designs I have worked on.

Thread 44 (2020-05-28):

Editor Eagle

kissup77, 2020-05-28:
Using latest eagle SW, I had opened files but it shows error "Start tag  ..."

kissup77, 2020-05-28:
I tried to open it with the latest EAGLE software

pdp7, 2020-05-28:
What files are you attempting to open in EAGLE

The BeagleBone AI was designed in Cadance Allegro.

BeagleBoard.org Foundation has contracted KiCad Professional Services to convert the design to KiCad, which is open source CAD software.

kissup77, 2020-05-28:
OMG, I thought it was designed with EAGLE. Let me try to open with Cadence Allegro

kissup77, 2020-05-28:
Actually I will need x,y coordinates to make samples of it. Can you share it with me?

pdp7, 2020-05-28:
@kissup77 do you mean centroid coordinates for a Pick n Place machine?

@jadonk do we have that information?

jadonk, 2020-06-03:
@pdp7 It should be part of the generated Gerbers, which we need to clean up. I might be able to regenerate it. Ideally, we'd verify against the production files.

kissup77, 2020-06-03:
One of Cadence Expert provides me x,y coordinates information files. It is resolved. Thanks.

Closed 2020-06-03.

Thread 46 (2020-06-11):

pin mux table doesn't show 'a' vs. 'b' on the P8 and P9 header pins.

MarkAYoder, 2020-06-11:
The following pru pins appear on both the 'a' and 'b' sides of the pin headers, but the table doesn't show which side it's on.  Here are the pins and their bit numbers.

Header  a       b
P8_27   17   16
P8_32   12    0
P8_45   18    13
P8_46   19    20

P9_31   10    7

jadonk, 2020-06-15:
Can you please link to the table or section the table is in, like https://github.com/beagleboard/beaglebone-ai/wiki/System-Reference-Manual#pru-icss1-pin-access ?

Also, please feel free to edit the wiki page.

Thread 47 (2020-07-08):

Which program should I use to open artwork files?

kissup77, 2020-07-08:
https://github.com/beagleboard/beaglebone-ai/tree/master/HW
I want to open the Artwork file.
I tried to open it with Altium, Pads, Eagle, but it failed.
Which program should I use to open artwork files?

pdp7, 2020-07-08:
Unfortunately, the design files are Cadence Allegro.  I believe there is a viewer here for Windows users: https://www.cadence.com/en_US/home/tools/allegro-downloads-start.html

However, we are currently having the design converted to KiCad.  We will announce when that is ready and add it to the repo.  And our goal is to use KiCad for future BeagleBoard.org designs.

pdp7, 2020-07-08:
If you have a more immediate need, please email me drew@beagleboard.org and I can see what the status is on the kicad conversion

Closed 2020-07-09.

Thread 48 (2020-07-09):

uart debugger not working

kissup77, 2020-07-09:
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
I attached the debugger as shown, but I can't see it.
The firmware used "AM5729 Debian 10.3 2020-04-06 16GB eMMC IoT TIDL Flasher".
The baud rate is 115200.
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
Is there something wrong with us?

DCelectronics, 2020-07-13:
It appears to me that you have correctly connected the GND, TX and RX, and the baud rate is correct (I just checked the one I have on my desk).

I suggest you use a regular image (not a flasher image, unless you intent to wipe your eMMC and re-install Debian)
https://debian.beagleboard.org/images/am57xx-debian-10.3-iot-tidl-armhf-2020-04-06-6gb.img.xz

Also, I suggest you check for shorts where the wires were soldered on the board (note that there is a tiny resistor between RX and GND pin on the board) and make sure that you have selected the correct COM port (I tend to have more the one USB-UART adaptors on my computer).

This cable would also make UART connections easier (I am posting this because this cable was not easy to find it).
https://www.newark.com/element14/1103004000156/beaglebone-ai-serials-cable/dp/50AH3702?MER=sy-me-pd-mi-acce

kissup77, 2020-07-13:
There is no short between RX and GND. I had checked with Voltmeter. No short.
So, It looks like CPU does not operate properly. Are there any point to check in voltage level? OSD should bring out 3.3V in VDD_3V3 while it does not bring up that voltage. What should I look more? I suspect PGOOD() or PSENSE pin option since it does not look like operate/run properly.

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

kissup77, 2020-07-13:
There is no short between RX and GND. I had checked with Voltmeter. No short.
So, It looks like CPU does not operate properly. Are there any point to check in voltage level? OSD should bring out 3.3V in VDD_3V3 while it does not bring up that voltage. What should I look more? I suspect PGOOD or PSENSE pin option since it does not look like operate/run properly.

DCelectronics, 2020-07-14:
How do you power your Beaglebone AI board?
What power supply do you use (wall-wart, powered USB hub etc), and what is its current rating?

You can get the Beaglebone AI schematic from here:
https://github.com/beagleboard/beaglebone-ai/raw/master/BeagleBone-AI_sch.pdf
Go to page 14 of 19 (section D2) and look at the connector P9.
GND pins 1, 2
VDD_3V3 pins 3, 4
VDD_CAPE_5V pins 5, 6
VDD_5V pins 7, 8
I suggest you check the voltages on these pins.

A side note, it has been a while since I last looked at the Beaglebone AI SRM, and the team has made lots of progress.
https://github.com/beagleboard/beaglebone-ai/wiki/System-Reference-Manual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

silver2row, 2021-03-18:
Hello...is that a BBG?

Seth

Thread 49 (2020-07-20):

Beagle board AI does not work.

kissup77, 2020-07-20:
When I insert the SD card with Flasher firmware(AM5729 Debian 10.3 2020-04-06 16GB eMMC IoT TIDL Flasher) and power it on, the board does not work.
led does not turn on except PWR led.
No output even on debug port.
Previously, it turned out to work.
How can I solve this problem?
Best regards
CH Cho

Closed 2020-07-21.

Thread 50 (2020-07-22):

DDR3 RAM Capacity Beaglebone AI

PrasanthElavarthi, 2020-07-22:
Hi. If I want to increase the capacity of the RAM to 4GB can I use the unused pins of DDR2?
Should I give any power inputs ? I noticed in DDR1 module we connected DDR1_ECC_DQS pin to VDD_DDR via 1k resistor and DDR1_ECC_DQSn to ground via 1k resistor.
Should we do anything similar to that?
And can I use 1Gx16 memory chips?

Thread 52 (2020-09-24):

how to Beagle AI factory reset

louiey, 2020-09-24:
Hello.

I got BB AI and tried to update its image according to guild from beagle introduction, it says I must update BB image to latest.
I followed according to guide and all of sudden, my BB shutdown during "sudo apt upgrage" and terminal said that "bb shutdown automatically due to its internal temperature is too high..." so removed power and power on again after few minutes and it's working and I could access via 192.168.7.2.
I started update image again but it requested some instruction to recover issue and I followed accordingly and I tried to update again but I couldn't connect at "http://repos.rcn-ee.com/debia" and keep failed to update or install something.
My BB AI seems to be cannot connect at server or internet so I would like to try factory reset.
How can I try factory reset with my BB AI?

louiey, 2020-09-24:
I thought instruction at "http://beagleboard.org/getting-started#update" is just for SD card only but it has more information how to update eMMC.

[http://beagleboard.org/getting-started#update](url)
[https://elinux.org/Beagleboard:BeagleBoneBlack_Debian#Flashing_eMMC](url)

Closed 2020-09-24.

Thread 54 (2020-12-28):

Unable to boot from EMMC while inserting a blank SD card

KoKoHomask, 2020-12-28:
When an SD card is not available, it can be started from EMMC. But when I insert a blank SD card, it fails to boot from EMMC.

KoKoHomask, 2020-12-29:
I need to put the program on the eMMC and use an SD card to store the data. But when I insert an empty SD card, the board card cannot boot the system from eMMC

KoKoHomask, 2020-12-29:
Resolved. With the R689 resistor removed, I can boot from eMMC when inserting an SD card. Will later versions add a BOOT Swtich button?

Closed 2020-12-29.

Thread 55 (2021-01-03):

Missing data about several P9 pins - 7.1.2.11 P9.32-P9.40 or 7.1.2.13 P9.43-P9.46

juvinski, 2021-01-03:
Hi Guys

Where I can find the register addressess or pin mux for the P9 missing pins?
I wish to use this pins for prugpio.

Thanks

juvinski, 2021-01-03:
Sorry guys,

I made a hudge mistake. please ignore this issue.

Closed 2021-01-03.

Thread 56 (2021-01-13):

USB-C port cannot be used as host

mvduin, 2021-01-13:
For some time now I've heard of people who need USB 3 strugging to use the USB-C port, which is the BBAI's only USB 3 port, in host mode (using a charging hub).  Recently I finally got around to digging into it, and my conclusion is:  it cannot work,  at least not if _either_ the BBAI _or_ the hub complies with the USB standard (if both violate USB standard then those violations might perhaps in some cases fortuitously interact to yield a working result, but that's obviously terrible to rely on).

Here's why:

When connecting devices via USB-C, initially one side has to become sourcing host (i.e. host data-role and source power-role) and one side has to become sinking device (i.e. device data-role and sink power-role), or no connection will be established.  Becoming initial-host **requires** being able to supply VBUS power, hence a VBUS-powered device like the BBAI will _always_ initially negotiate device role on connect.  Even if the BBAI is powered via P9, it lacks the ability the provide VBUS to the USB-C connector, hence it still cannot negotiate initial host role.

After these initial roles are established it is possible for the devices to subsequently swap data role (i.e. which side is host and which side is device) and/or power role (i.e. which side is source (i.e. supplies VBUS power) and which is sink), which is the only way you can become a sinking host or sourcing device.  However, these role swaps can only be done using USB Power Delivery (PD) signalling.  Unfortunately the USB-C controller on the BBAI (TUSB322I) does not support PD signalling, nor does its replacement on rev A2 (HD3SS3220), hence it cannot perform a data role swap.

Since the BBAI can neither be initial-host nor perform a data role swap, there is no way for it to ever have host role on its USB-C port.  Forcing the usb subsystem into host mode via sysfs will merely cause the BBAI to violate the usb specification and may result in a drive conflict.  It does not change the negotiated role, hence it will not result in successful connection (unless the other side _also_ violates the usb specification).

The only real fix is to use a USB-C controller with support for PD communication, specifically data role swap.  (Or, in retrospect, another option would have been to use a dedicated USB3 host (instead of the USB2 host port) and limit the Type-C port to USB2 instead of doing it the other way around, since it seems more likely people would want the beaglebone to be USB3 host than to be USB3 device.)

wiebel, 2021-02-16:
This make the whole USB-C situation even more ridiculous.  Running the BBAI at full speed requires easily north of 2A at 5V which is fine for a USB-C Powersource (although even most Powerbanks are more likely to suport 9V@2A than 5V@2.5A), but in the likely case of using it as a USB client, even my beefy Thinkpad sometimes fail to deliver. So one might like to use a powered HUB, but that leaves us with a USB 3 Type A Port, as true USB-C are not existant as of now, and USB Type A is rated at a 0.9A, while most hubs will deliver 1.5-2A with a reasonable voltage Ddop, at times (boottime to be precise) the voltage browns out rebooting the BBAI. Learning that it will also not work as a host, which could be done as most USB-C Hubs feature a USB-C power input, makes one really wish to have the good old barrel jack back. To sum it up: To use USB 3 at all it must be powered via P9.
Note that the preinstalled debian comes with an older kernel having a 400Mhz mode available, which uses less power at the cost of beeing unbearably slow.

vvv-ca, 2021-05-29:
You just need a splitter cable to provide power externally (or from the other USB port - lots of those online for use with smartphones and power banks) and it works just fine. You might have to wait for the attached device to reconnect if you restart the BBAI since the vbus won't loose power but it usually takes less than 10 seconds.

mvduin, 2021-09-19:
> You just need a splitter cable to provide power externally

I'm assuming you replied purely based on the subject instead of actually reading the post, since this is an awful "solution" for something that is not even the problem under discussion in this thread. I was already assuming the connected device supplies power, typically by using a charging hub/dock, since otherwise the BBAI obviously doesn't have power.  There is no way to make a USB-C "splitter cable" unless either
1. there's actually a whole bunch of electronics in the "cable"
2. the cable is a blatant violation of every relevant spec, only works in limited situations with certain devices (rather than consistently and reliably), sabotages the overcurrent protection designed into the usb standard, and probably risks damaging devices.

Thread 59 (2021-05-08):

Device tree overlay for ov2640 camera module with Beaglebone AI

Anitha241991, 2021-05-08:
We want to use ov2640 camera module with Beaglebone AI for our project. We found that ov2640.ko.xz is available under in the Linux Buster version 10. kernel version 4.19.

We understand that we will have to make the dtbo file to make the kernel understand our pin connections. However, all literature online is related to $pins and $slots which is obsolete.

We want to write our device tree overlay and go the route where just editing the uEnv.txt is enough to make kernel pick the dtbo.

Can you please guide us with the proper steps as we are kind of lost here.

niyazFattahov, 2021-07-17:
How you gonna connect dvp camera to BBAI?
It does not have camera inputs,  only lcd output according to schematics

Anitha241991, 2021-07-17:
Okay thank you.

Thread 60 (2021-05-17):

Error on the UART definition pins

juvinski, 2021-05-17:
Hi,

in the UART resume, there mention to UART5 as P9.13 and P9.15, but the pin descriptions the correct would be P9.11 and P9.13.

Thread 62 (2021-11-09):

BeagleBone AI doesn't work via USB

bogdanys, 2021-11-09:
Hi everyone!
I just got a new BeagleBone AI and I'm trying to connect it to PC via USB. When I connect it to PC it is shown a new device called VAYU, and keeps appears and dissaperas. On the other hand, it light up just one led, the led near USB C port. I tried to connect the board to other PC and works immediately. Also, when it connect to other PC, at other device is shown other name, not VAYU. I installed the BONE_D64.exe driver, I uninstalled the VAYU driver that is shown but nothing change.

Closed 2021-11-10.

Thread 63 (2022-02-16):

CAD STEP model faulty

kokalz, 2022-02-16:
The current version of the .step model appears to be broken. The import fails with Solidworks 2020 SP4 and Autodesk Viewer.
Any chance for an updated revision?

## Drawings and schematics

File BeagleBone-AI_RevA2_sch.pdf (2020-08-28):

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
# Sheet

# Sheet Name

01 | Index Page
02 | Block Diagram
03 | PMIC1
04 | PMIC2
05 | AM57x SYSTEM
06 | DDR PART1
07 | DDR PART2
08 | DDR VTT/LEDs
09 | MMC/UBOOT
10 | AM57x Interface 1

# 11 AM57x Interface 2

12 | Processor Power
13 | Processor Power Decoupling
14 | Exp Conn
15 | WIFI

# Schematic: BeagleBone AI

# 16 Gigabit Ethernet 17 USB Type C 18 ADC/TF/Debug

19 | HDMI

A1

REV | Description | BY
| Revision History
2. Page 3: Added C21=2.2uF to U3 Pin C1.
1. Changed schematic and PCB revision to A2.
3. Page 5: Deleted the net alias name JTAG_TCK of P2 Pin9.
4. Page 9: Changed R175-R179,R184,R185,R186,R188 from 10K to 47K.

# 6. Page 17: Changed the USB Type C port controller circuit, Used U13(TI HD3SS3220)

instead of U22 (TI TUSB322IRWBR) and U72 (Pericom PI3USB3102ZLE).
7. Page 18: Added pull-down resistor R708=100K to UART1_RX, set R173=NI(100K).
5. Page 14: Added EEPROM U9 for Board ID.
Added optional 0R resistor to tie CPU Pin AB10 to P9 Pin13. Added 0R resistor to tie DCAN(CPU Pin G19 G20) to P8 Pin7 Pin8.

# 8. Page 19: Changed the HDMI companion chip, Used U15(TI TPD12S016) instead of

U12 (TI TXS0104ERGYR).

# Used TI TLV758P instead of U40 (SG MICRO SGM2032-ADJYN5G/TR) for

ADC voltage reference/supply.

# DATE

12/24/2018

# Seeed

Initial Release | Embest
A2 | 04/24/2020
A2 | 1. Page 14: Deleted D82 B360A-13-F. 2. Page 17: Changed the power MUX circuit, Used U12(TI TPS2121) instead of Q15 D81 D82 Q19. 3. Page 19: Deleted Q19 and net H5V, tied FB7 to VDD_5V instead of H5V. | 04/30/2020 | Seeed
A2 | 05/12/2020 1. Page 16: Changed Ethernet PHY from ATHEROS AR8035-AL1B to TI DP83867CRRGZ.

A2

1. Page 10: Changed R134 from 1.5K to 2.2K.

05/15/2020

# 2. Page 16: Changed R475 from 10K to 2.2K; Removed R138, as "JTAG pins can be left unconnected if not used" from TI's suggestion

3. Page 16: Added some FBs and CAPs for Three-Supply Mode, but set them to NI, just reserved.

# Seeed

# Seeed

A2 | 1. Page 3: Fixed the wiring issue with the I2C2 on the PMIC. | 05/18/2020 | Seeed
2. Page 17: Changed R60 from NI to 0R; R35 from 4.7K to NI(200K),
| added R191=NI(4.7K); R52 from 10K to 200K; Set R46=0R, R47=NI(0R).
1. Page 16: Changed the definition of PHY_LED, keep the status like BBB.
A2
3. Page All: Added the Seeed's BOM to SCH.
06/08/2020 | Seeed Title: Size: | Document Number: | Rev: Draw By: | Date: | Sheet: | of
https://www.seeedstudio.com A3 | A2 Seeed | Wednesday, July 15, 2020 | 1 | 19 BeagleBone AI AM57x 01 Index Page Title: Size: | Document Number: | Rev: Draw By: | Date: | Sheet: | of
https://www.seeedstudio.com A3 | A2 Seeed | Wednesday, July 15, 2020 | 1 | 19 BeagleBone AI AM57x 01 Index Page Title: Size: | Document Number: | Rev: Draw By: | Date: | Sheet: | of
https://www.seeedstudio.com A3 | A2 Seeed | Wednesday, July 15, 2020 | 1 | 19 BeagleBone AI AM57x 01 Index Page

# B e a g l e B o n e A I A M 5 7 x B L O C K D i a g r a m

# D D R 3 L

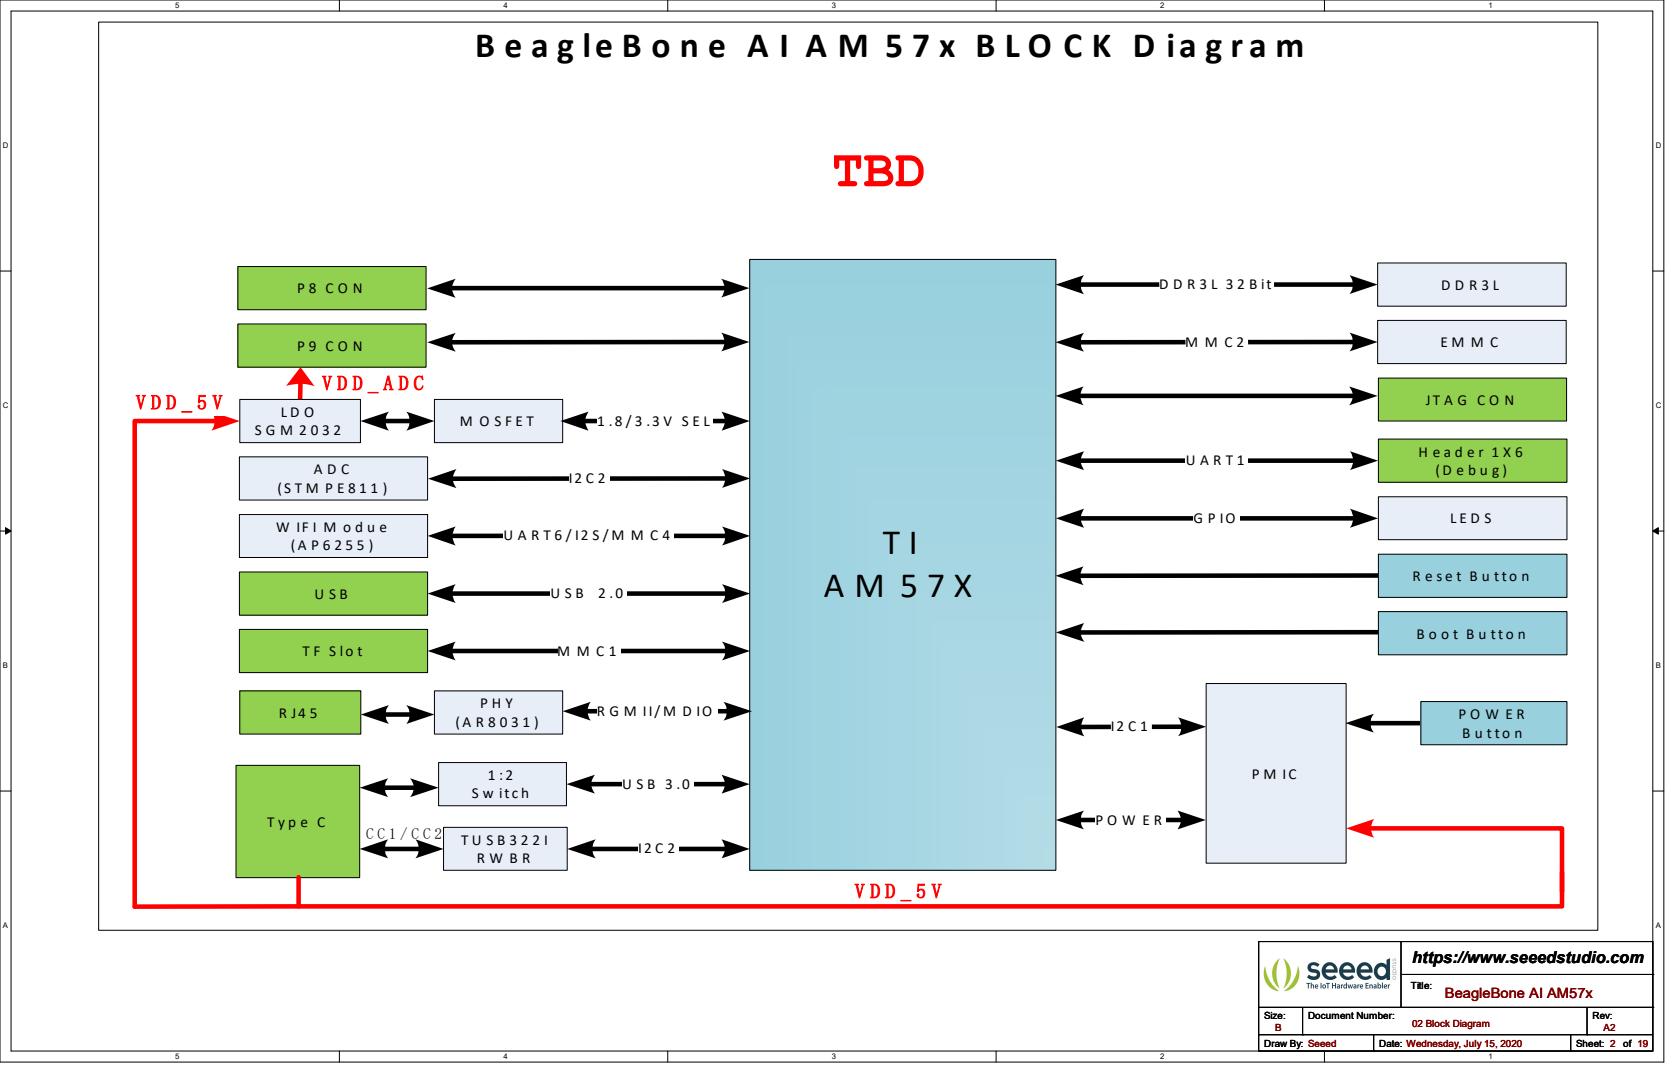
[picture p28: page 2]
TBD; Title: Size:; Document Number:; Rev: Draw By:; Date:; Sheet:; https://www.seeedstudio.com B; A2 Seeed; Wednesday, July 15, 2020; 19 BeagleBone AI AM57x; 02 Block Diagram

D D

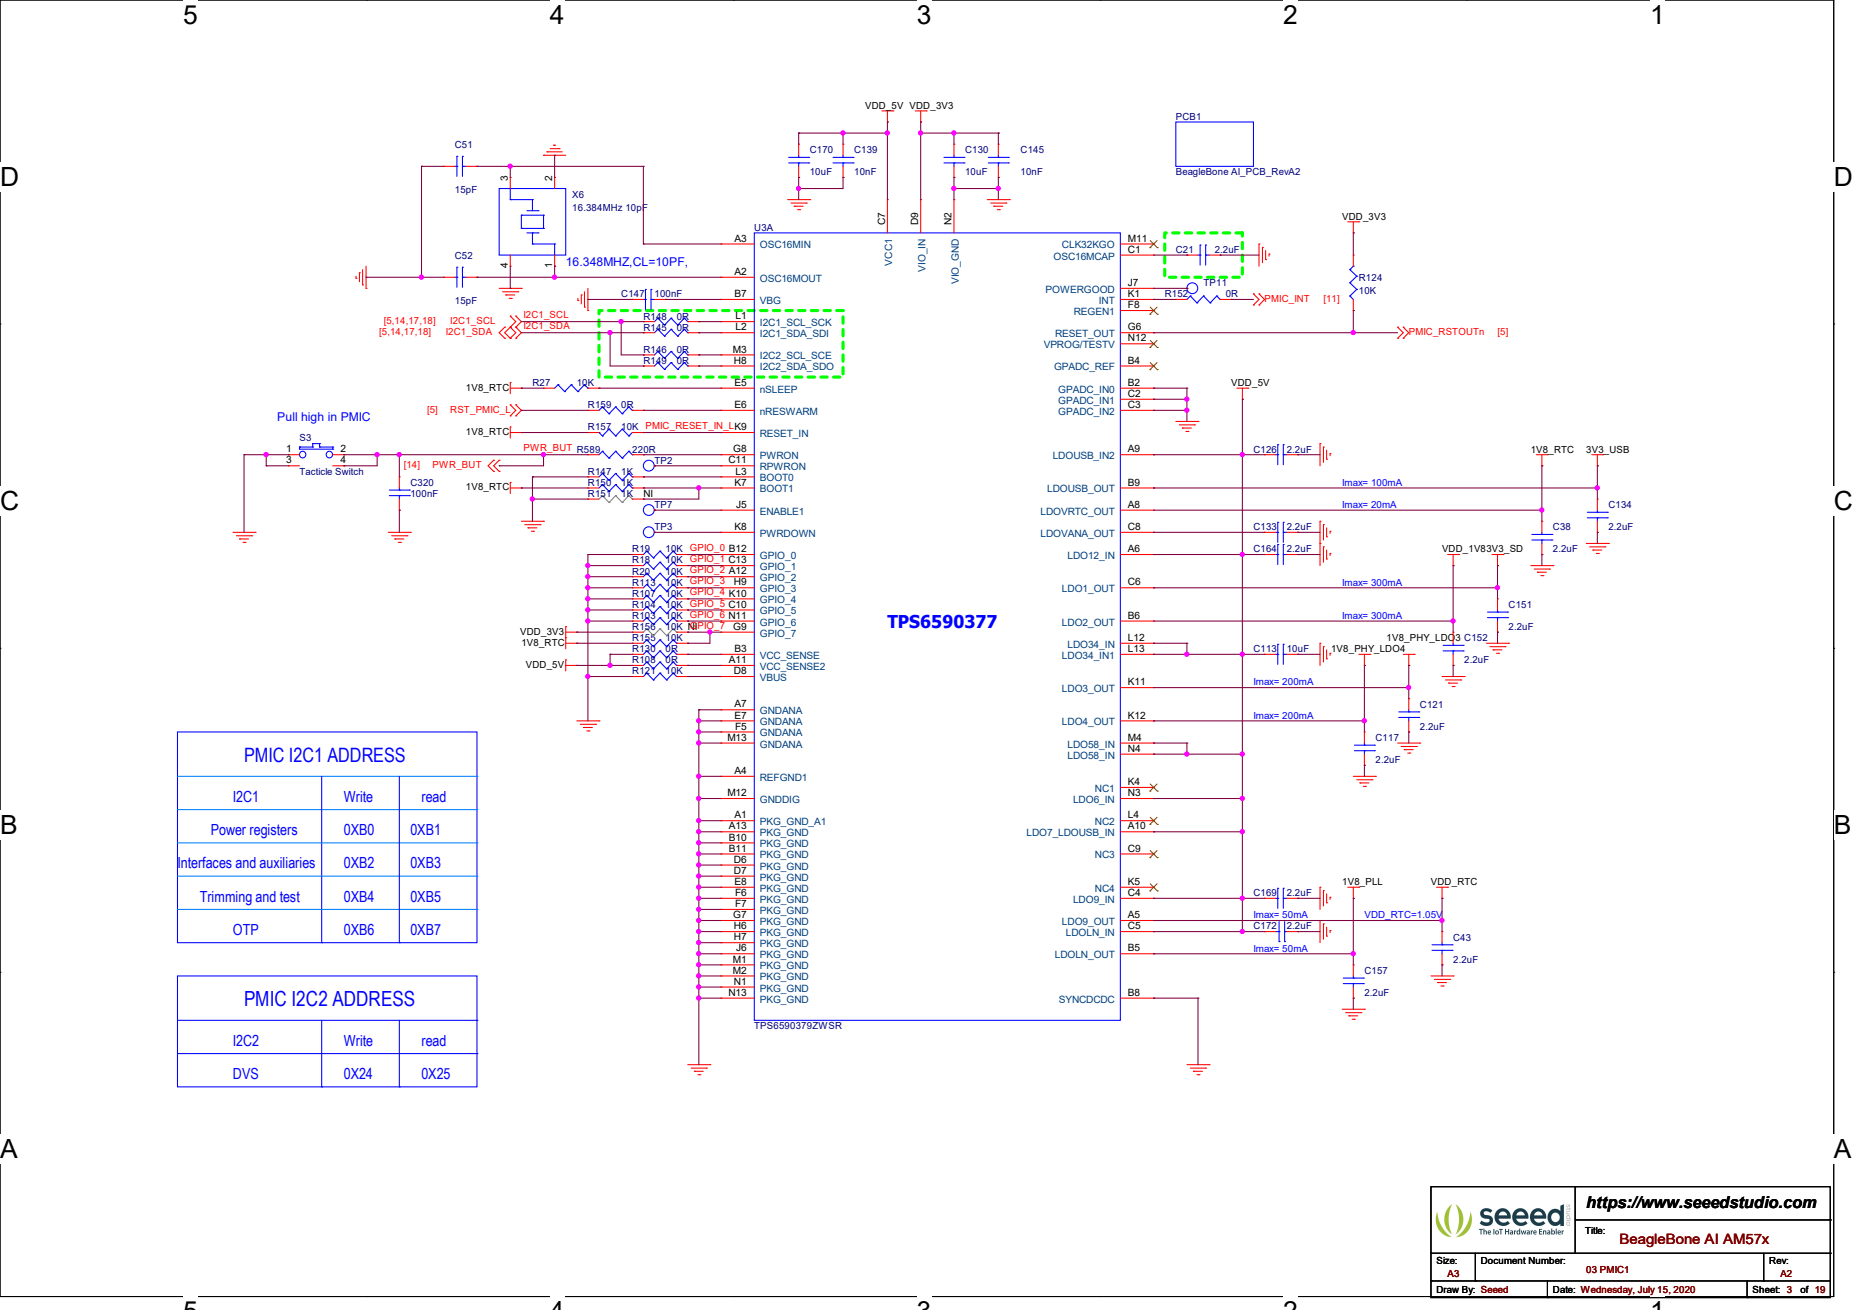
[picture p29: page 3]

INT K1 REGEN1 F8 RESET_OUT G6 VPROG/TESTV N12 GPIO_0 B12 GPIO_1 C13 GPIO_2 A12 GPIO_3 H9 GPIO_4 K10 GPIO_5 C10 GPIO_6 N11 GPIO_7 G9 VCC_SENSE B3 VCC_SENSE2 A11 VBUS D8

Pull high in PMIC

D D

# 4.7uF C127

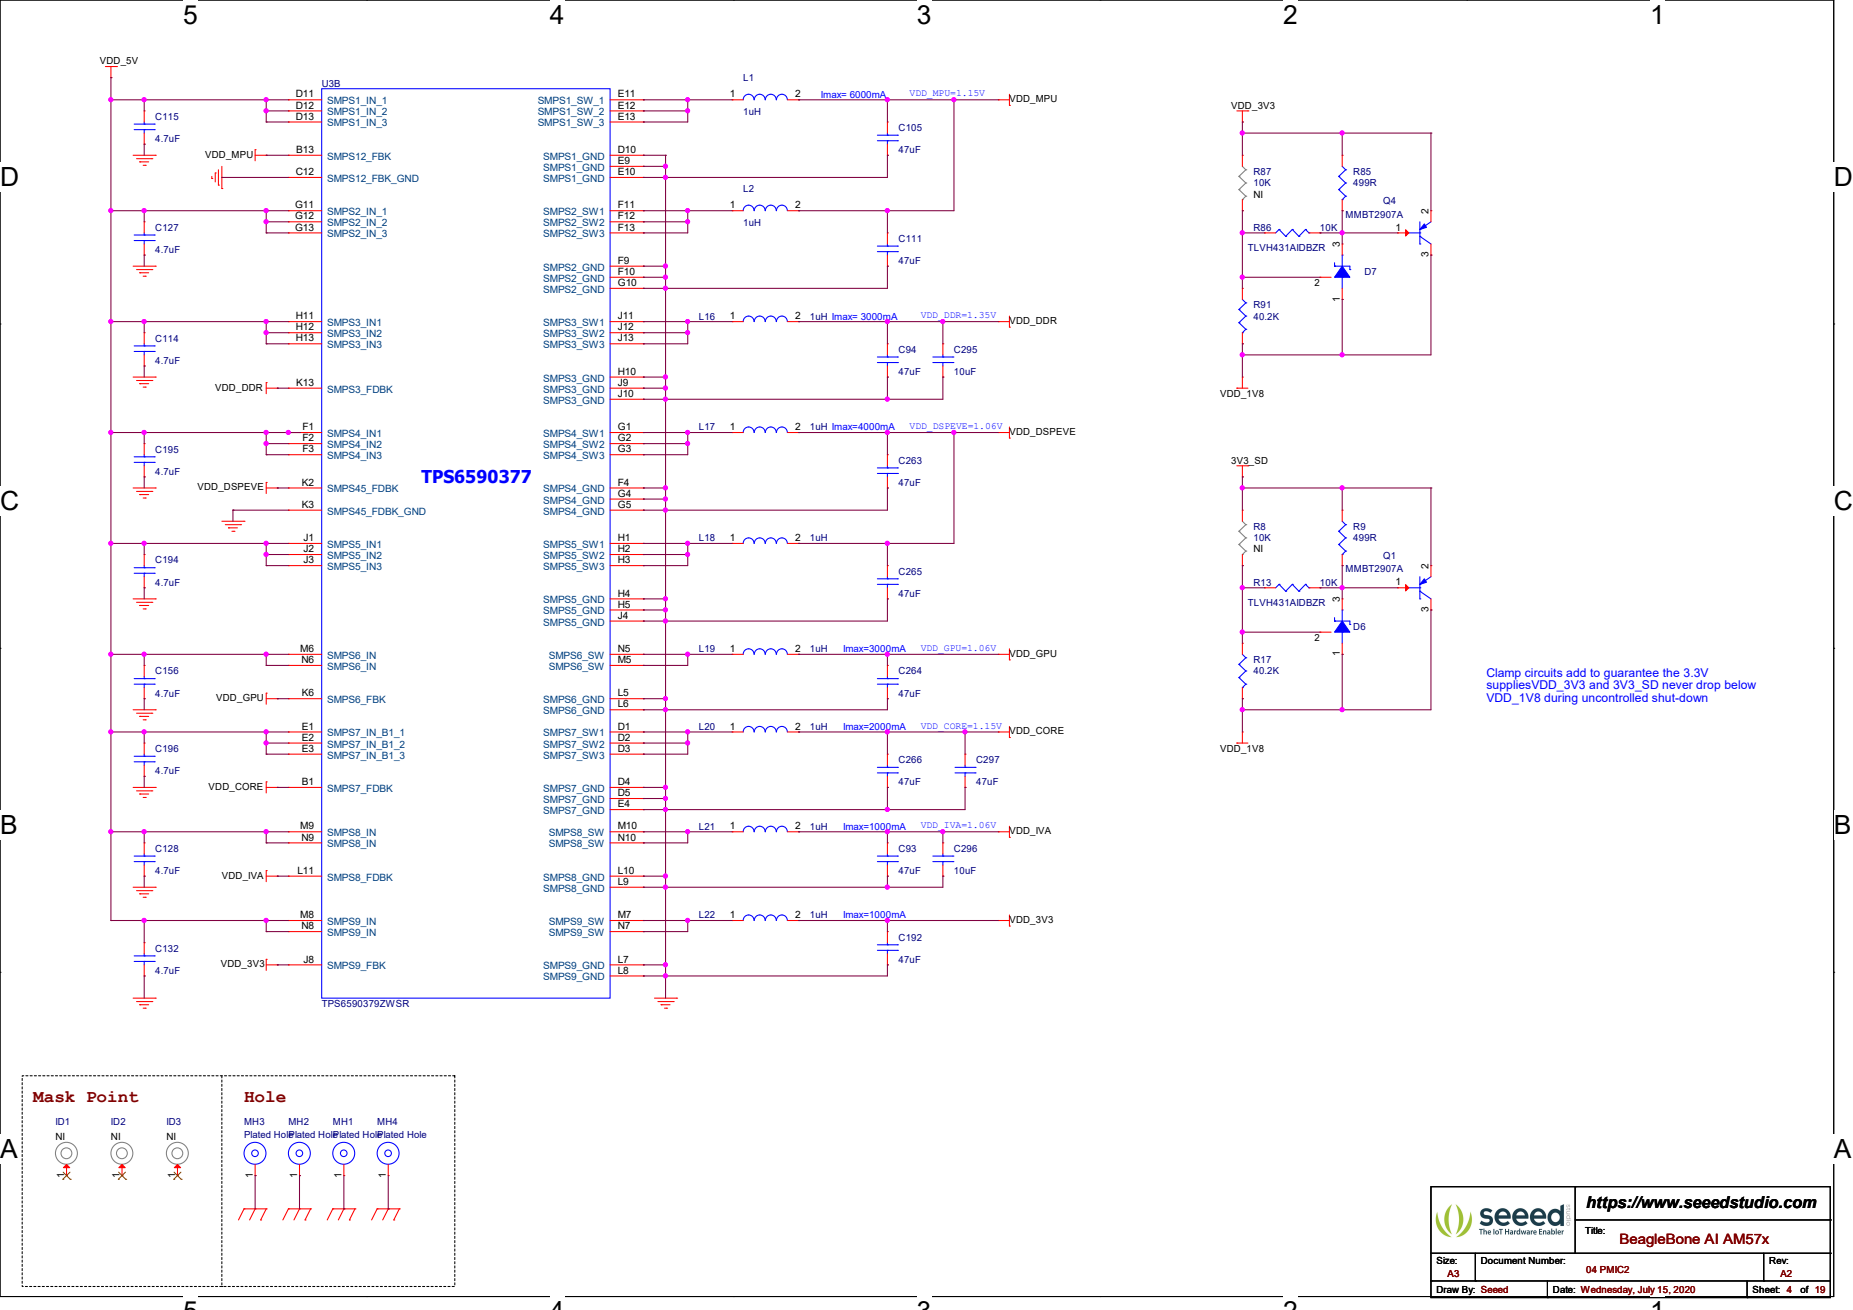
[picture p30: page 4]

Clamp circuits add to guarantee the 3.3V
suppliesVDD_3V3 and 3V3_SD never drop below
VDD_1V8 during uncontrolled shut-down
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

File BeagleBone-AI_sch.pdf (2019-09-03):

# BeagleBone AI AM57x

# SCHEMATIC PAGE

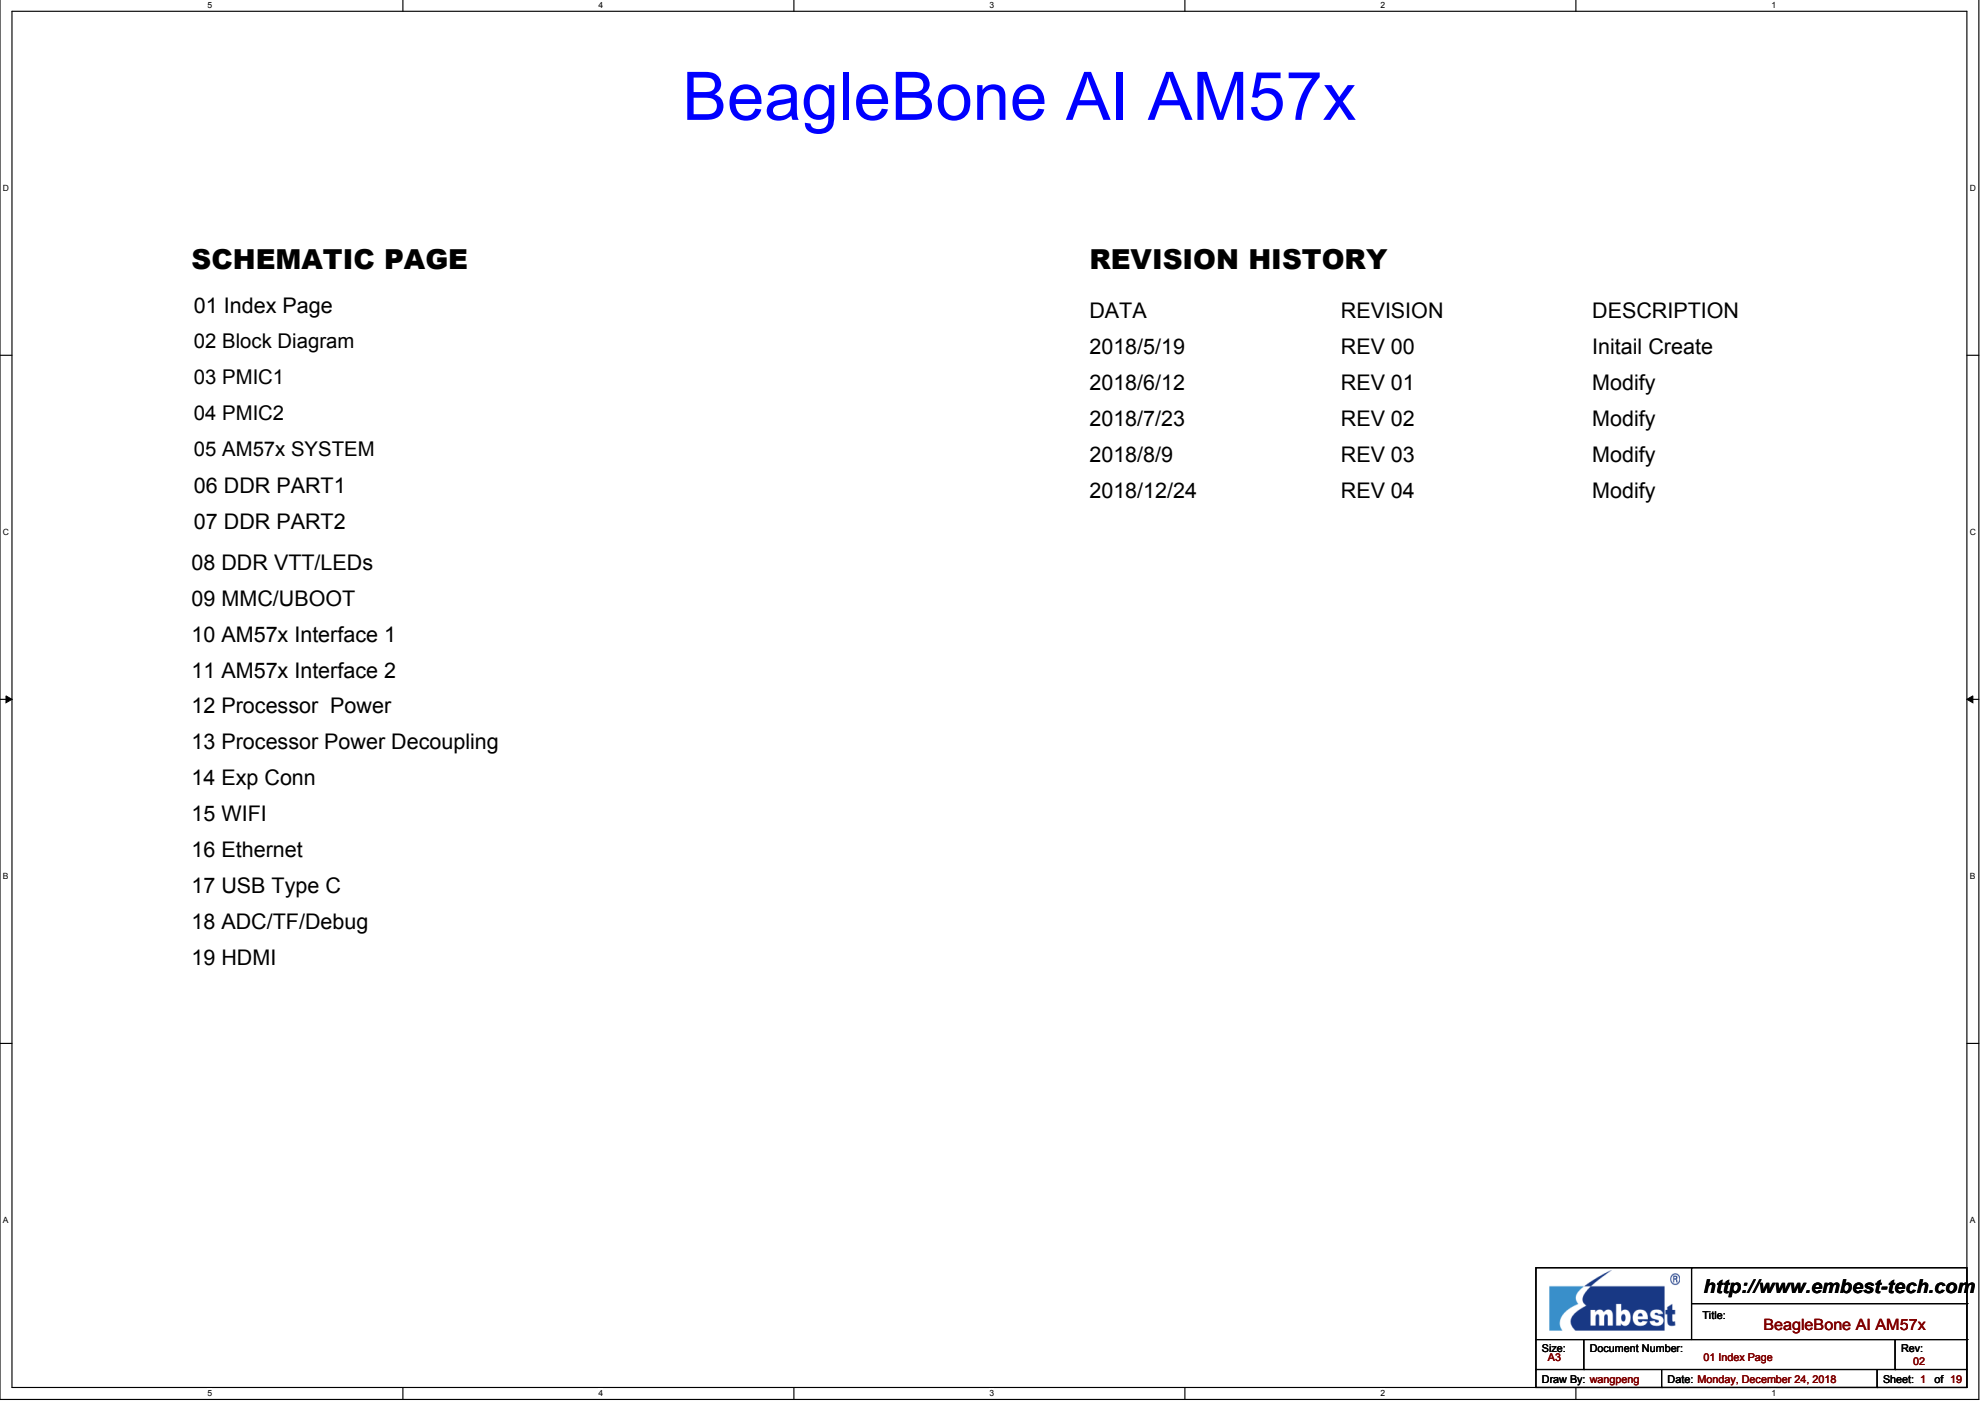
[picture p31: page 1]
07 DDR PART2; 06 DDR PART1; 04 PMIC2; 03 PMIC1; 05 AM57x SYSTEM; 02 Block Diagram; 01 Index Page; REVISION HISTORY; DATA; REVISION; DESCRIPTION; REV 00; Initail Create; REV 01; Modify; REV 02; REV 03; REV 04; Title:; Size:; Document Number:; Rev:; Draw By:; Date:; Sheet:; BeagleBone AI AM57x; wangpeng; Monday, December 24, 2018

08 DDR VTT/LEDs
09 MMC/UBOOT
10 AM57x Interface 1
11 AM57x Interface 2
12 Processor Power
13 Processor Power Decoupling
14 Exp Conn
15 WIFI
16 Ethernet
17 USB Type C
18 ADC/TF/Debug
19 HDMI

http://www.embest-tech.com

# B e a g l e B o n e A I A M 5 7 x B L O C K D i a g r a m

# D D R 3 L

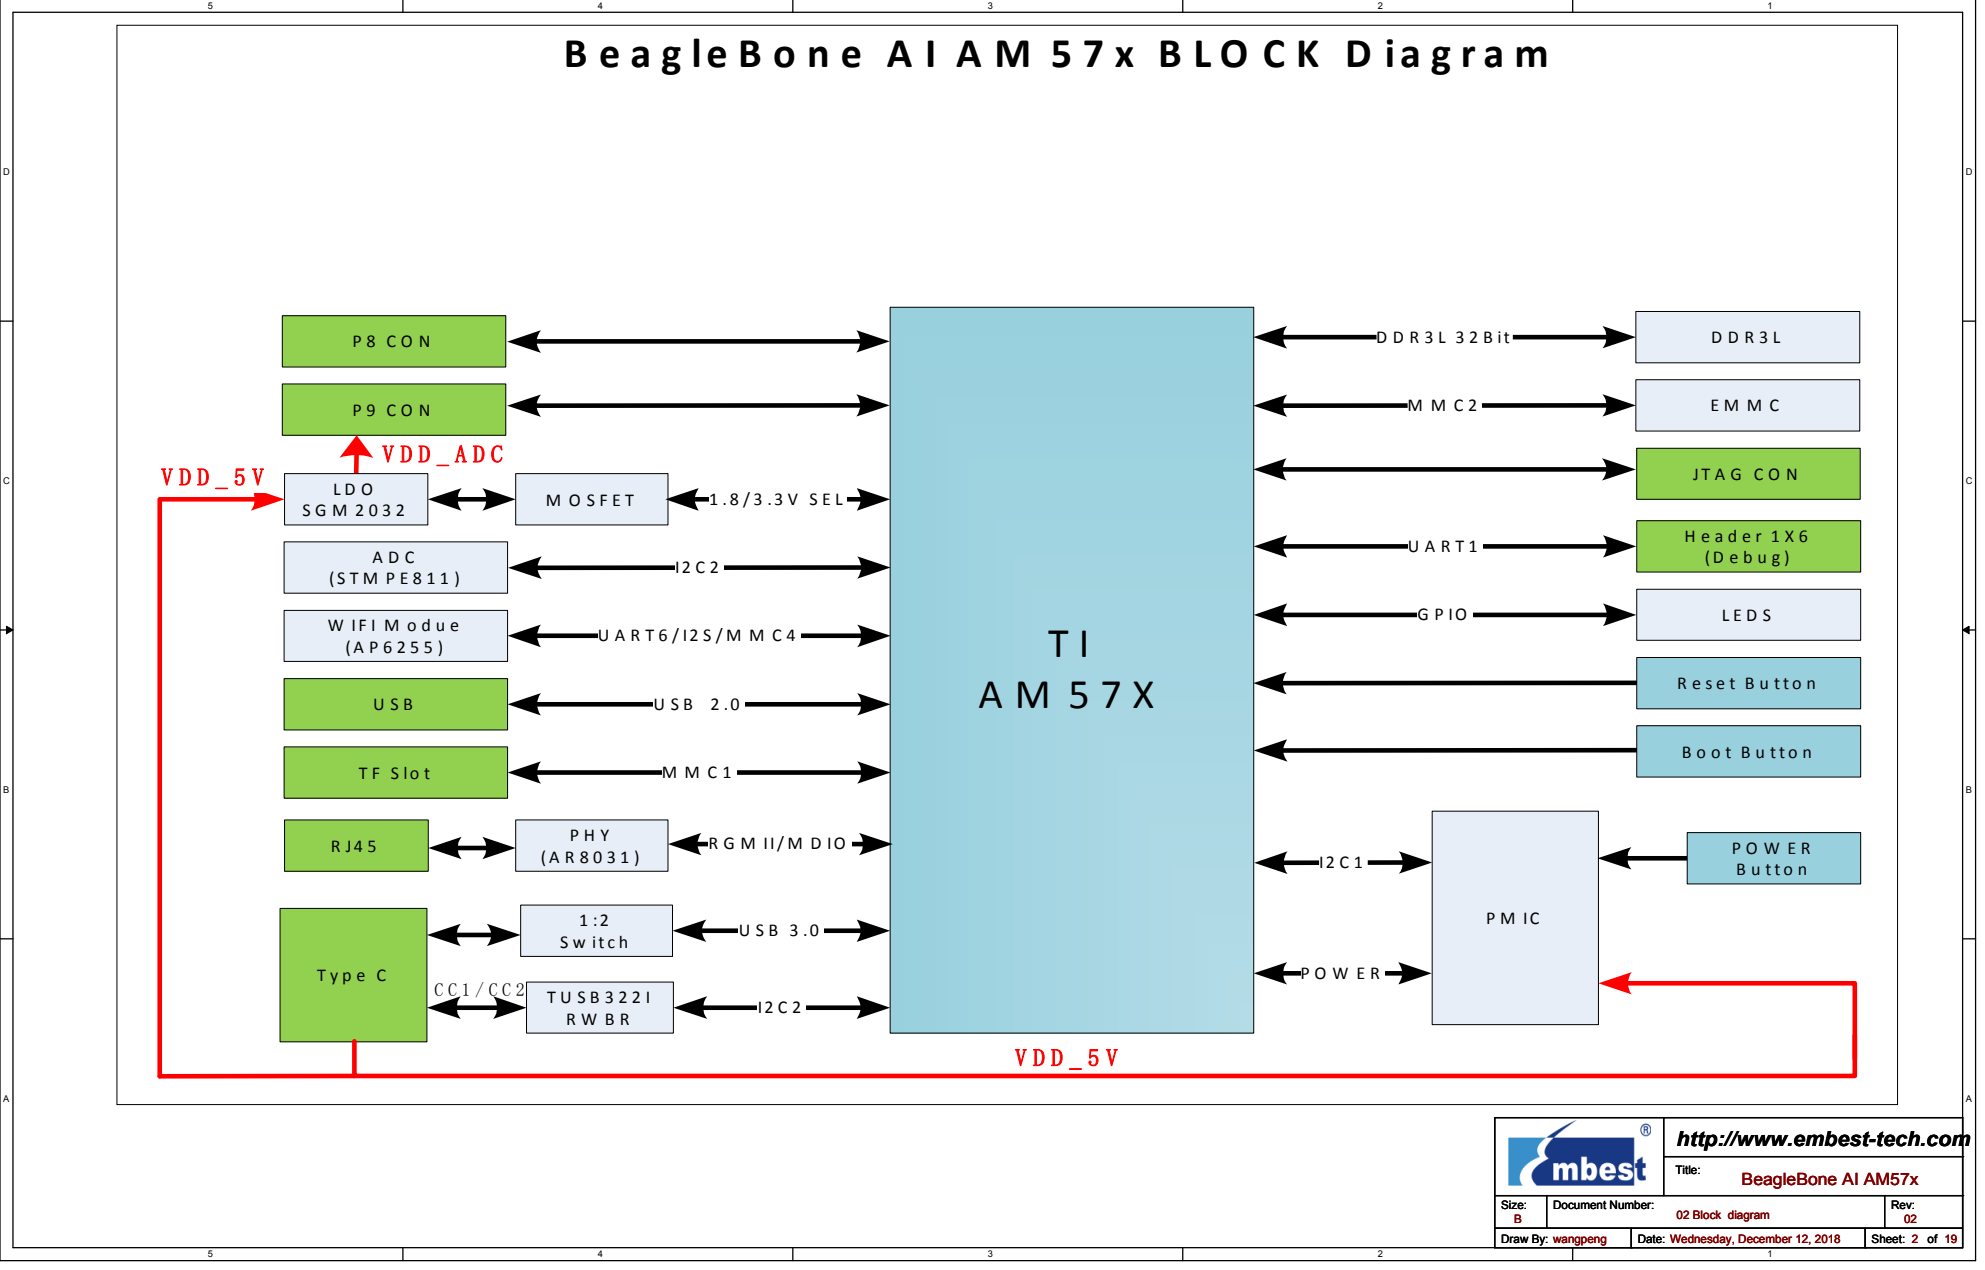
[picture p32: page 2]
Title:; Size:; Document Number:; Rev:; Draw By:; Date:; Sheet:; 02 Block diagram; BeagleBone AI AM57x; wangpeng; Wednesday, December 12, 2018

http://www.embest-tech.com

D | D

16.348MHZ,CL=10PF,

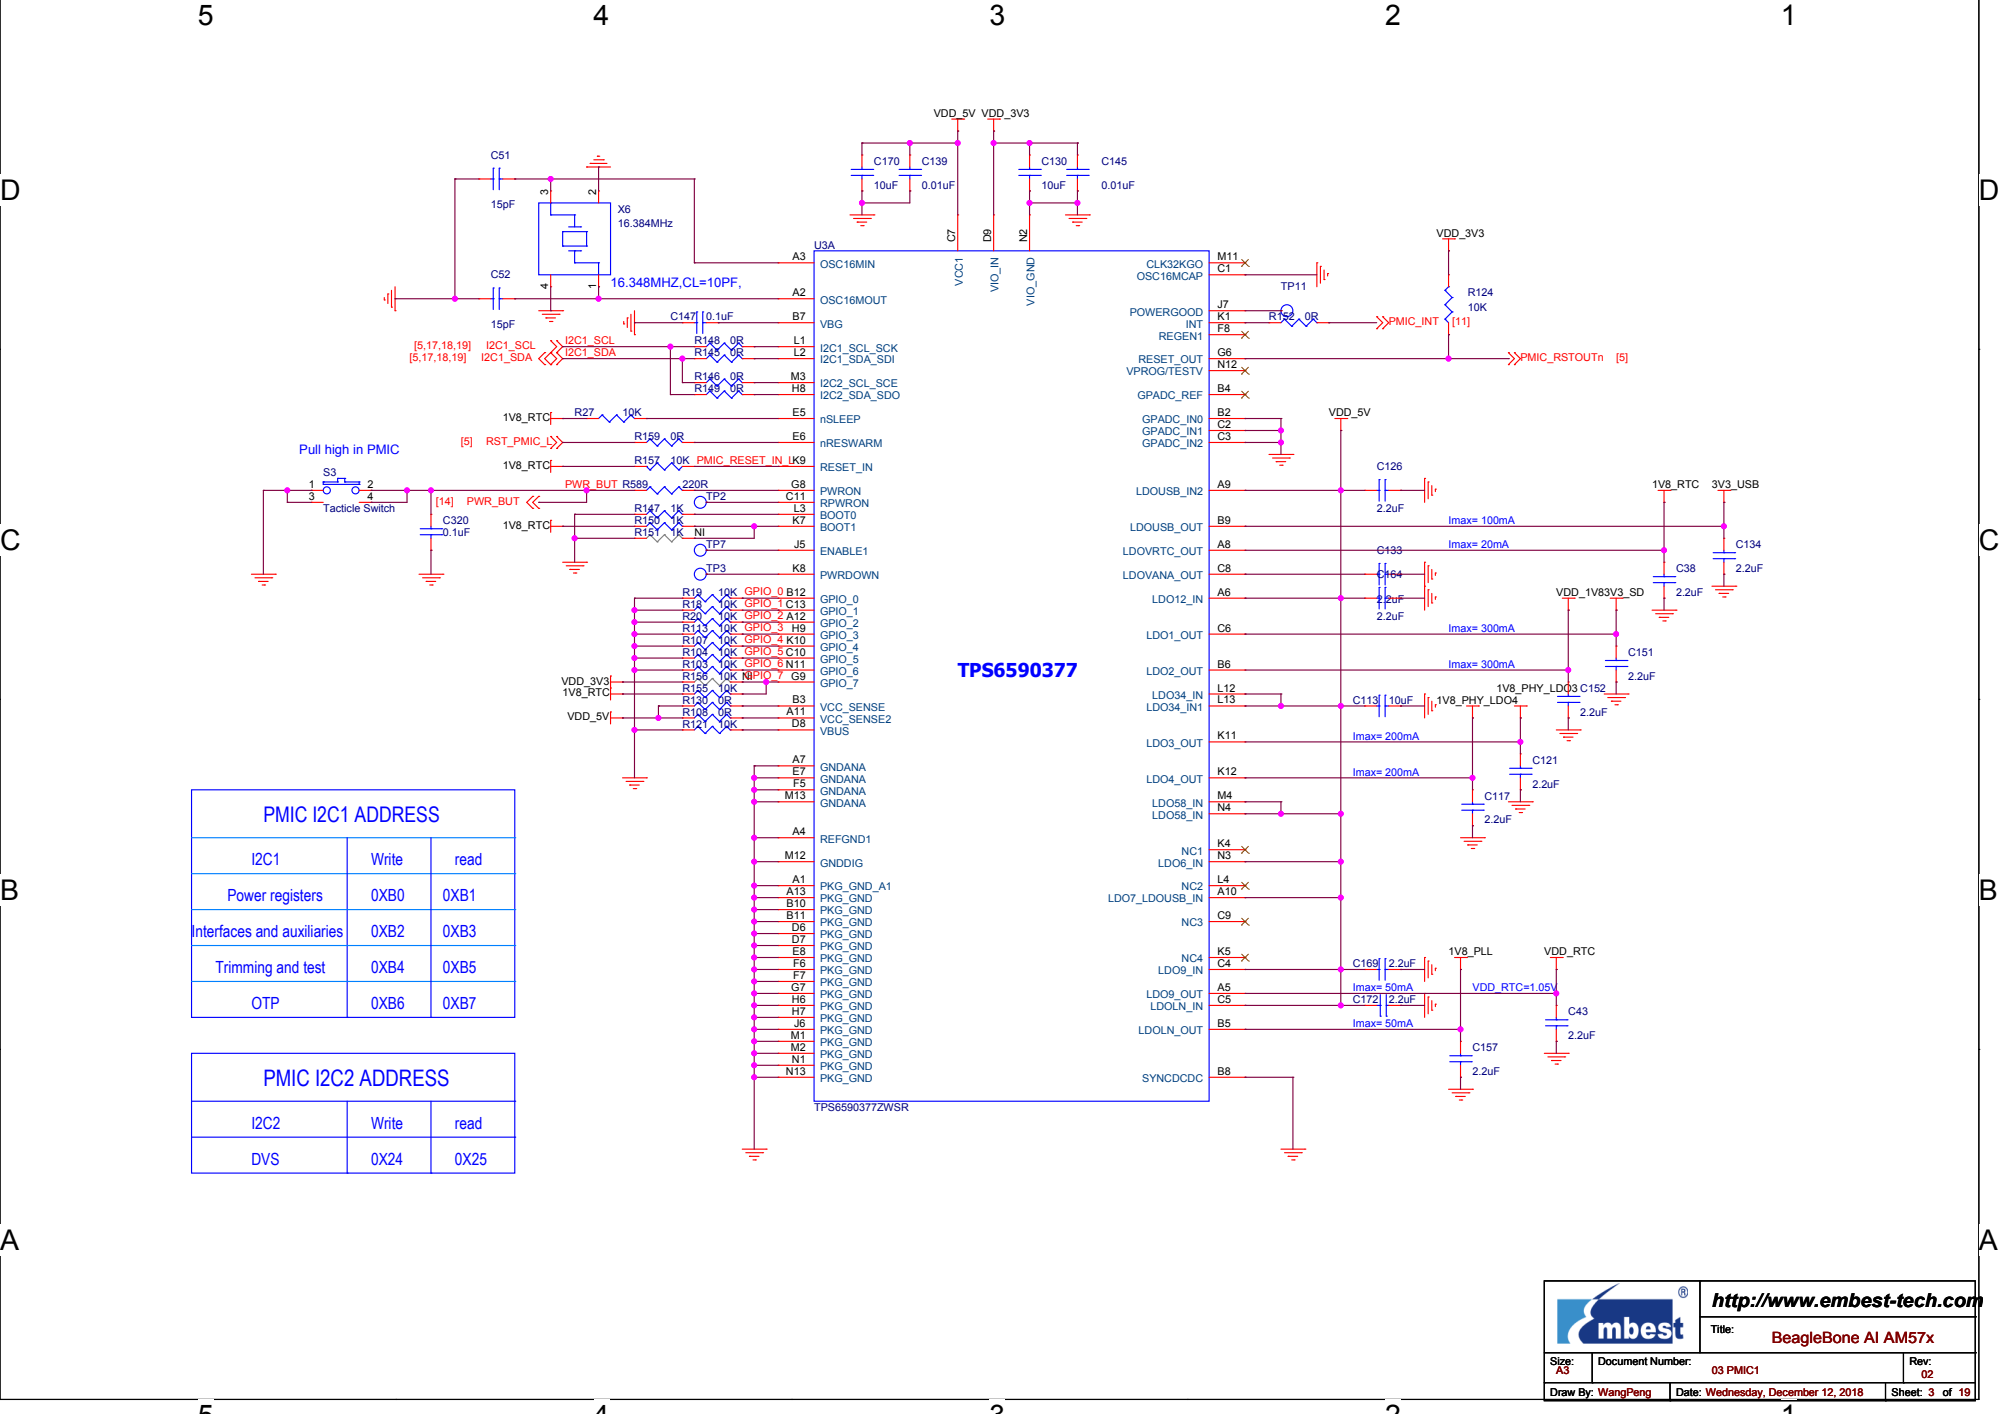
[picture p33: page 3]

Pull high in PMIC

http://www.embest-tech.com

D | D

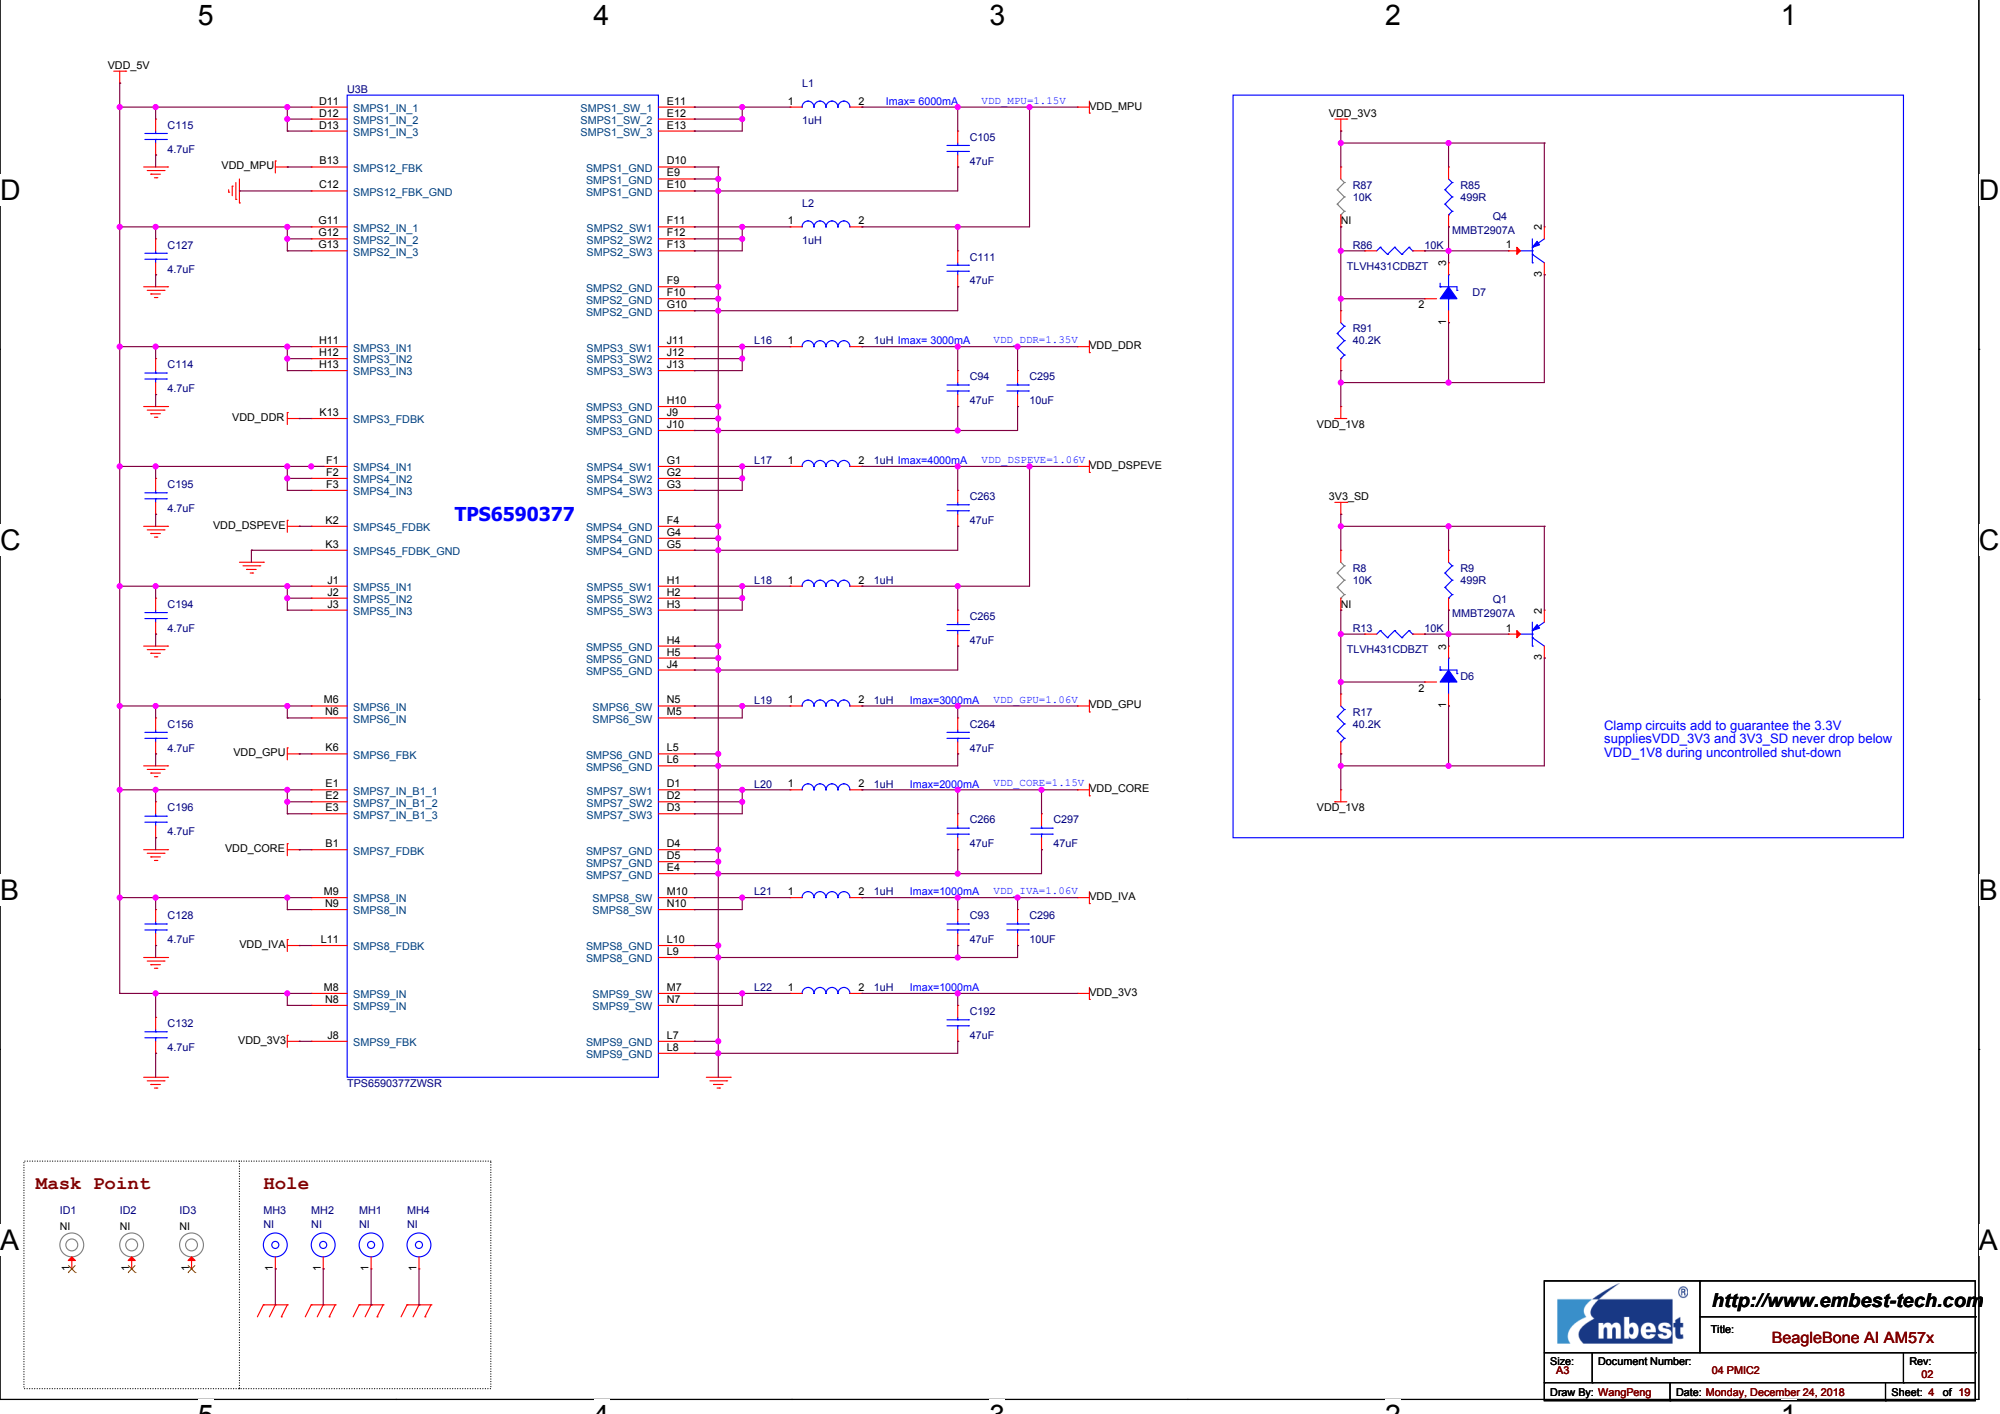
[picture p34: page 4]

Clamp circuits add to guarantee the 3.3V
suppliesVDD_3V3 and 3V3_SD never drop below
VDD_1V8 during uncontrolled shut-down

http://www.embest-tech.com

20MHZ,CL=18PF,

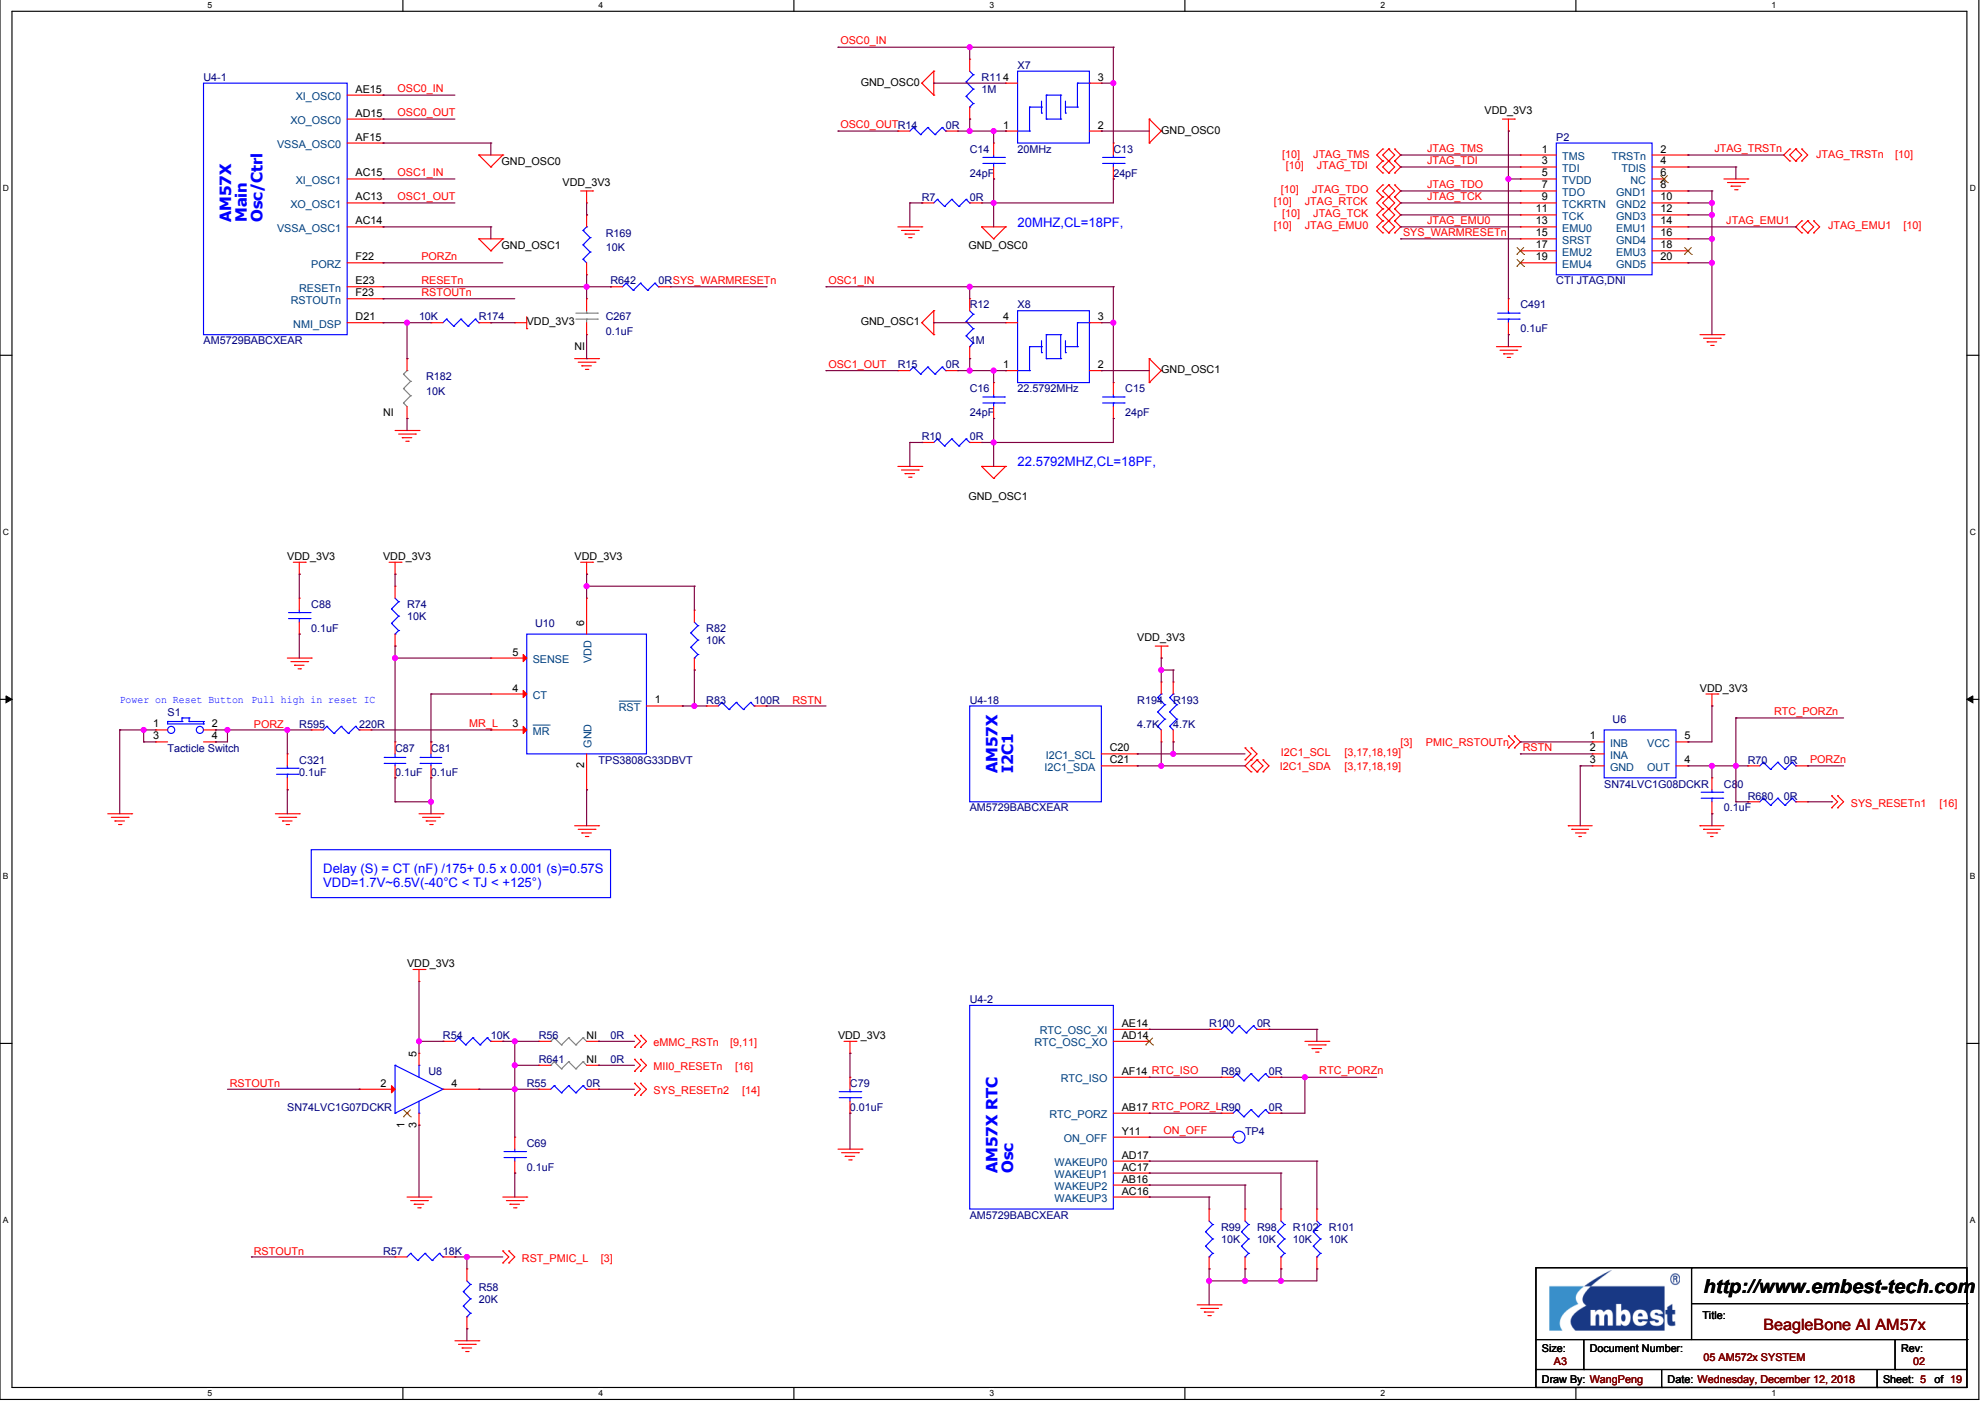
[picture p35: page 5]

Power on Reset Button Pull high in reset IC

http://www.embest-tech.com

D | D

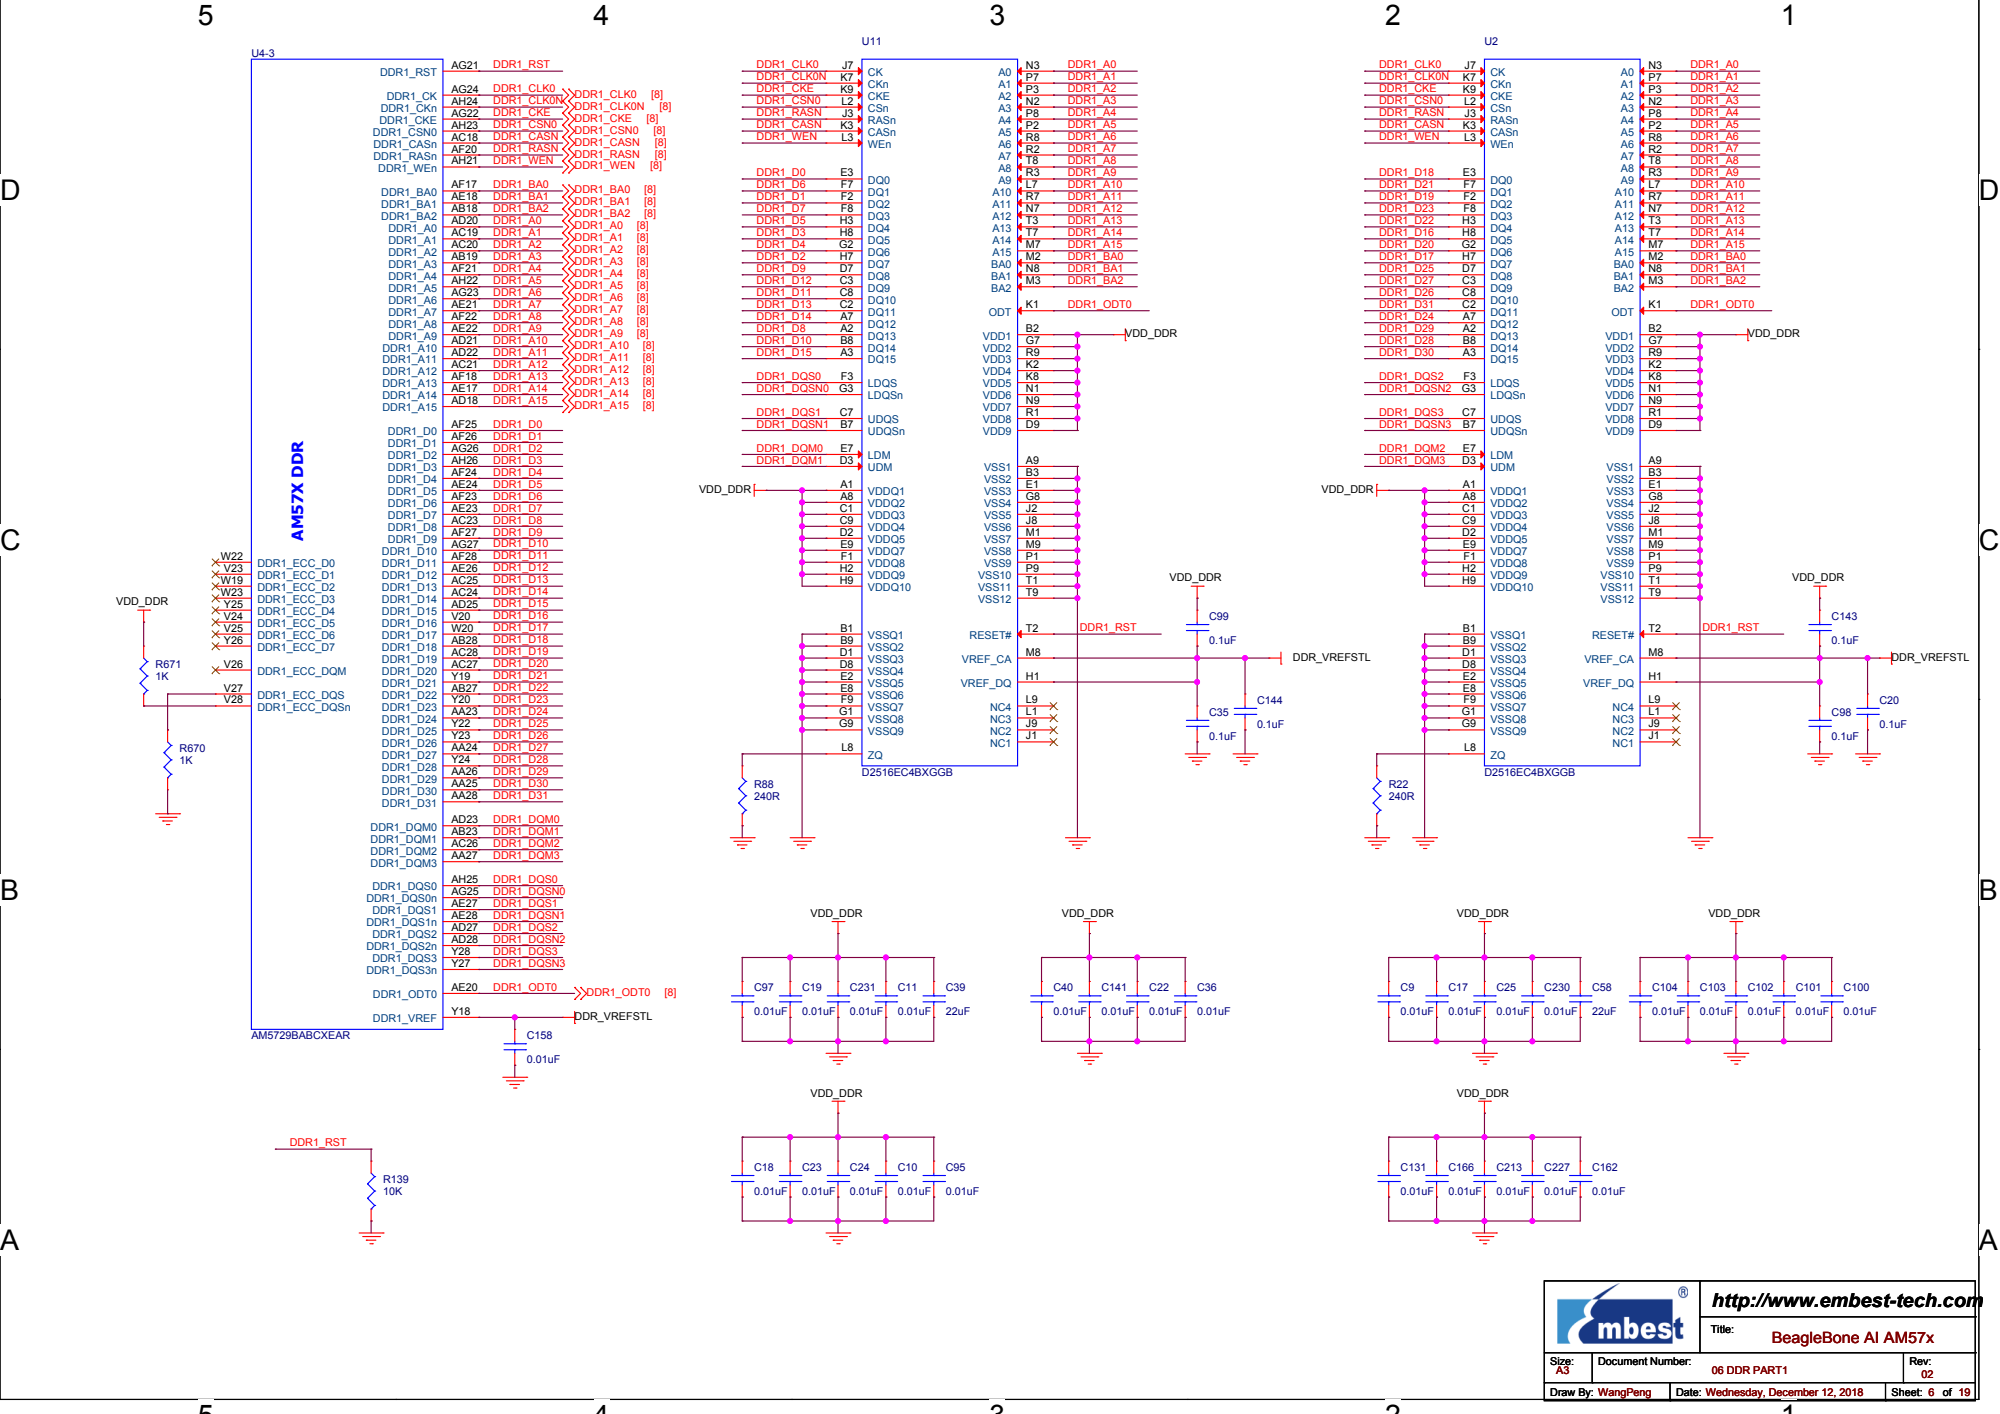
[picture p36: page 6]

http://www.embest-tech.com

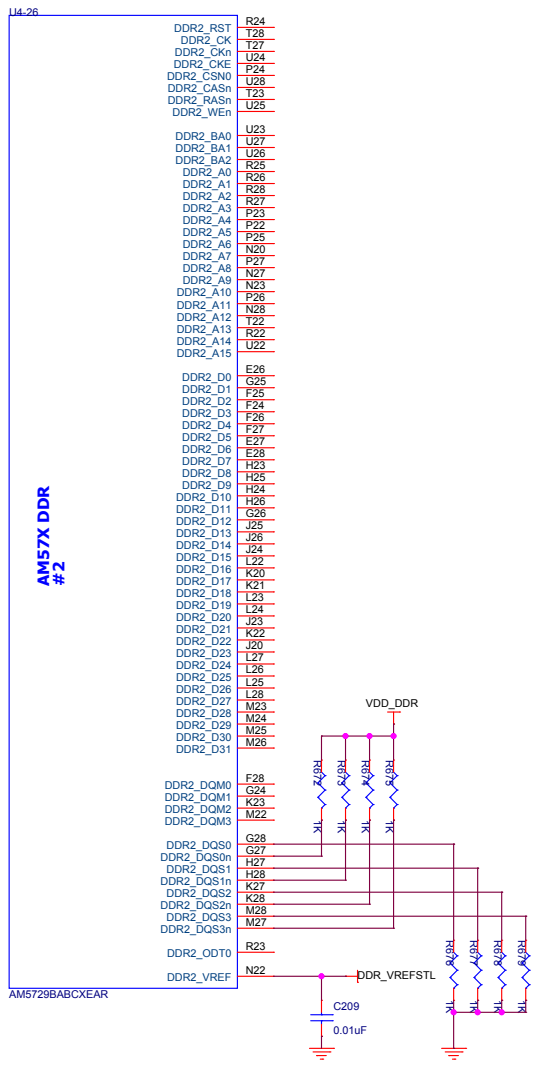
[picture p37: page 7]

http://www.embest-tech.com

### POWER LED

LED | VTT

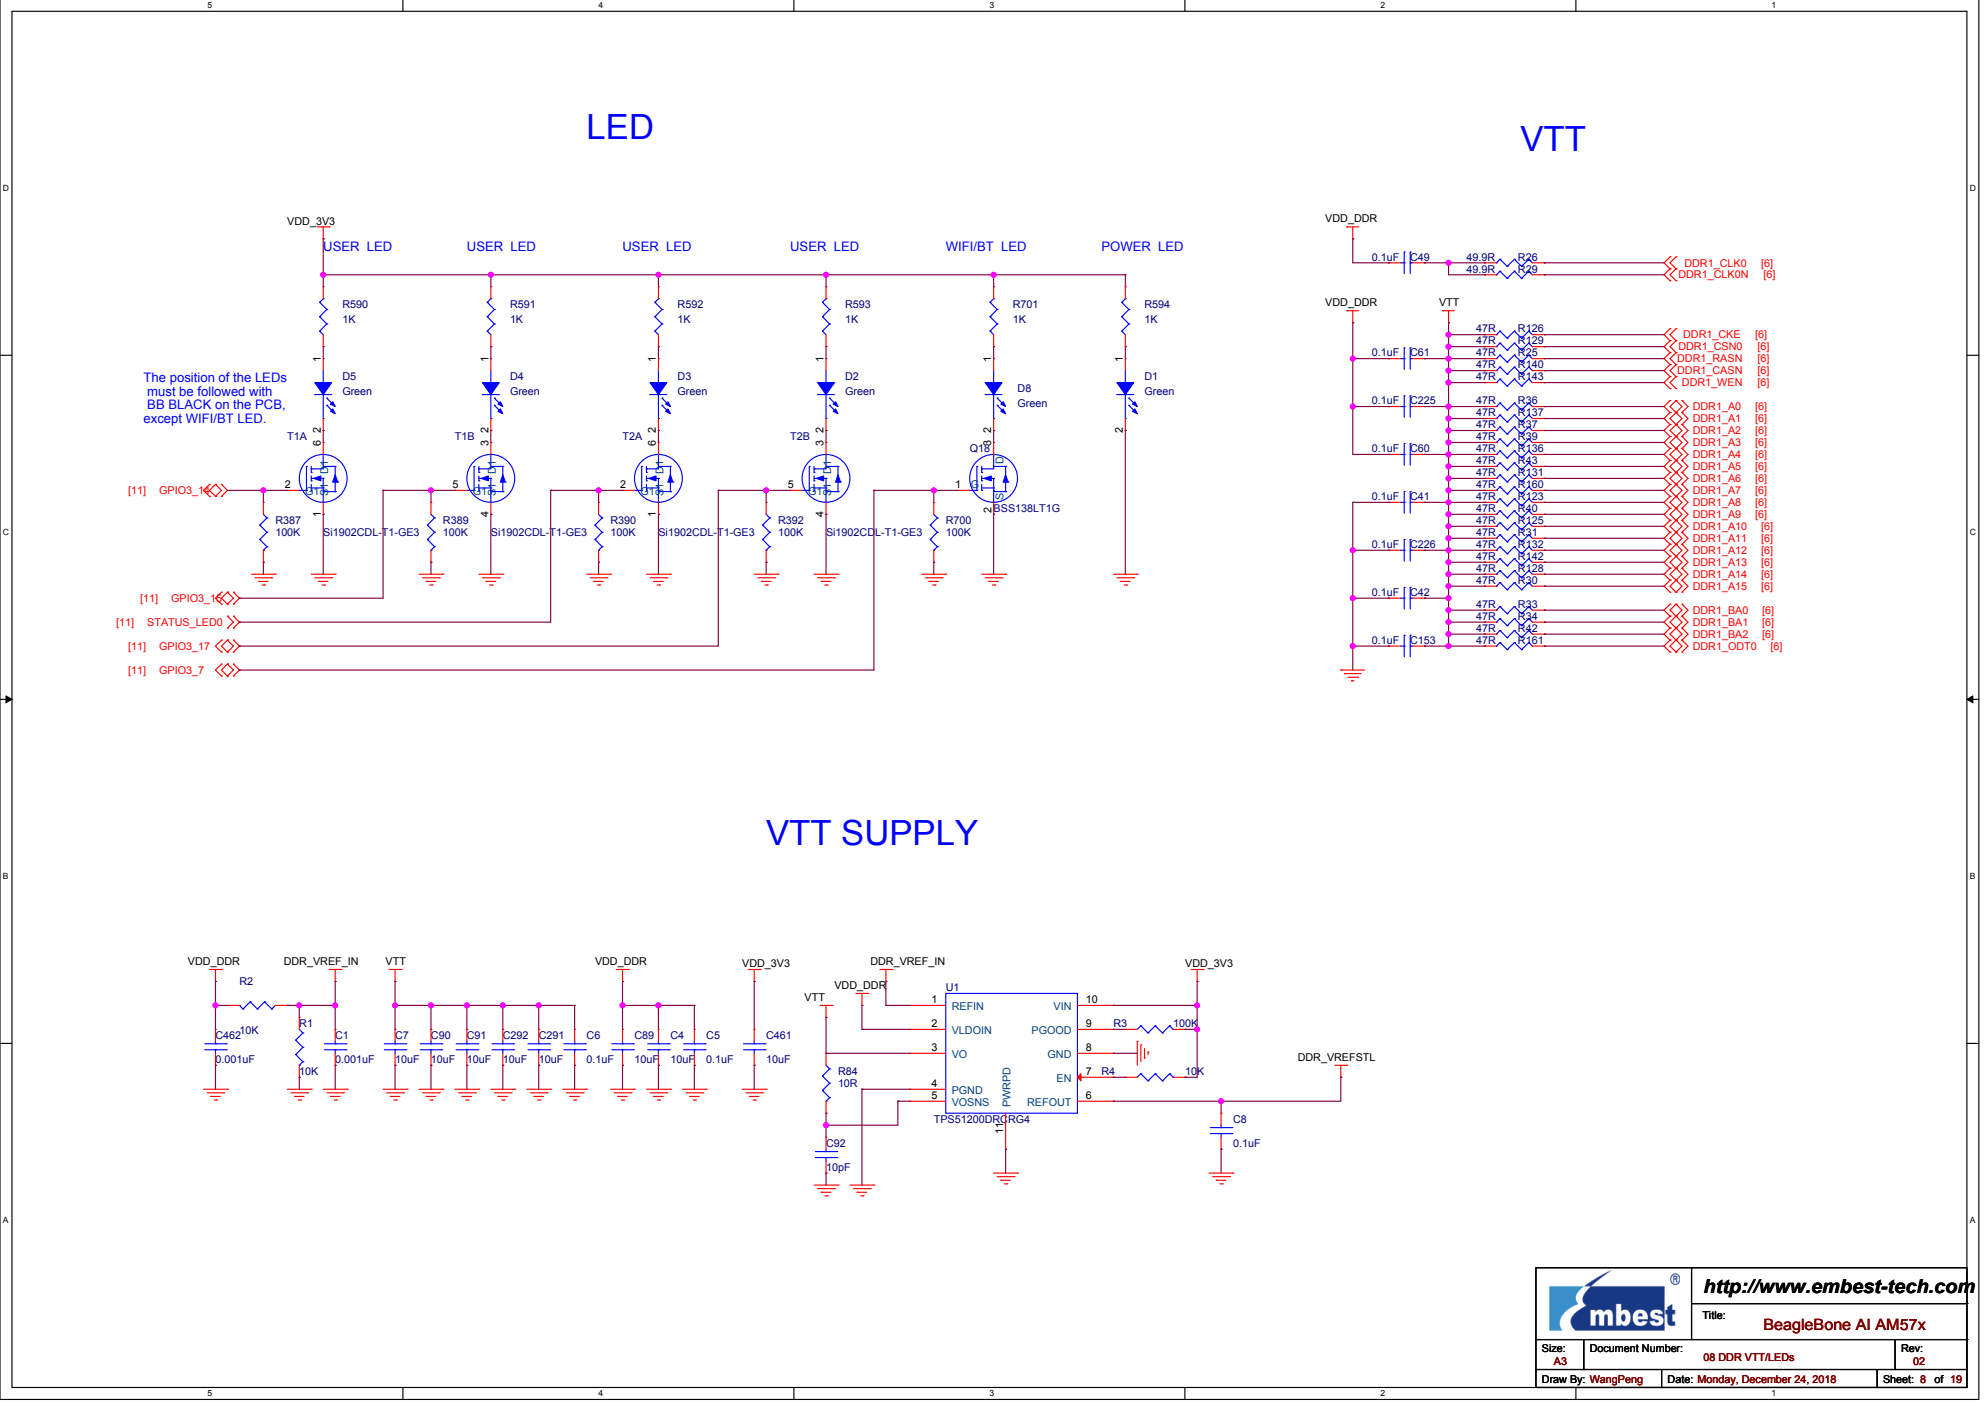
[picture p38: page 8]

The position of the LEDs
must be followed with
BB BLACK on the PCB,
except WIFI/BT LED.

http://www.embest-tech.com

MMC3_DAT2/PR2_MII_MR1_CLK | AC9 R⁶⁰² ¹⁰K | R⁶⁰⁴ ¹⁰K

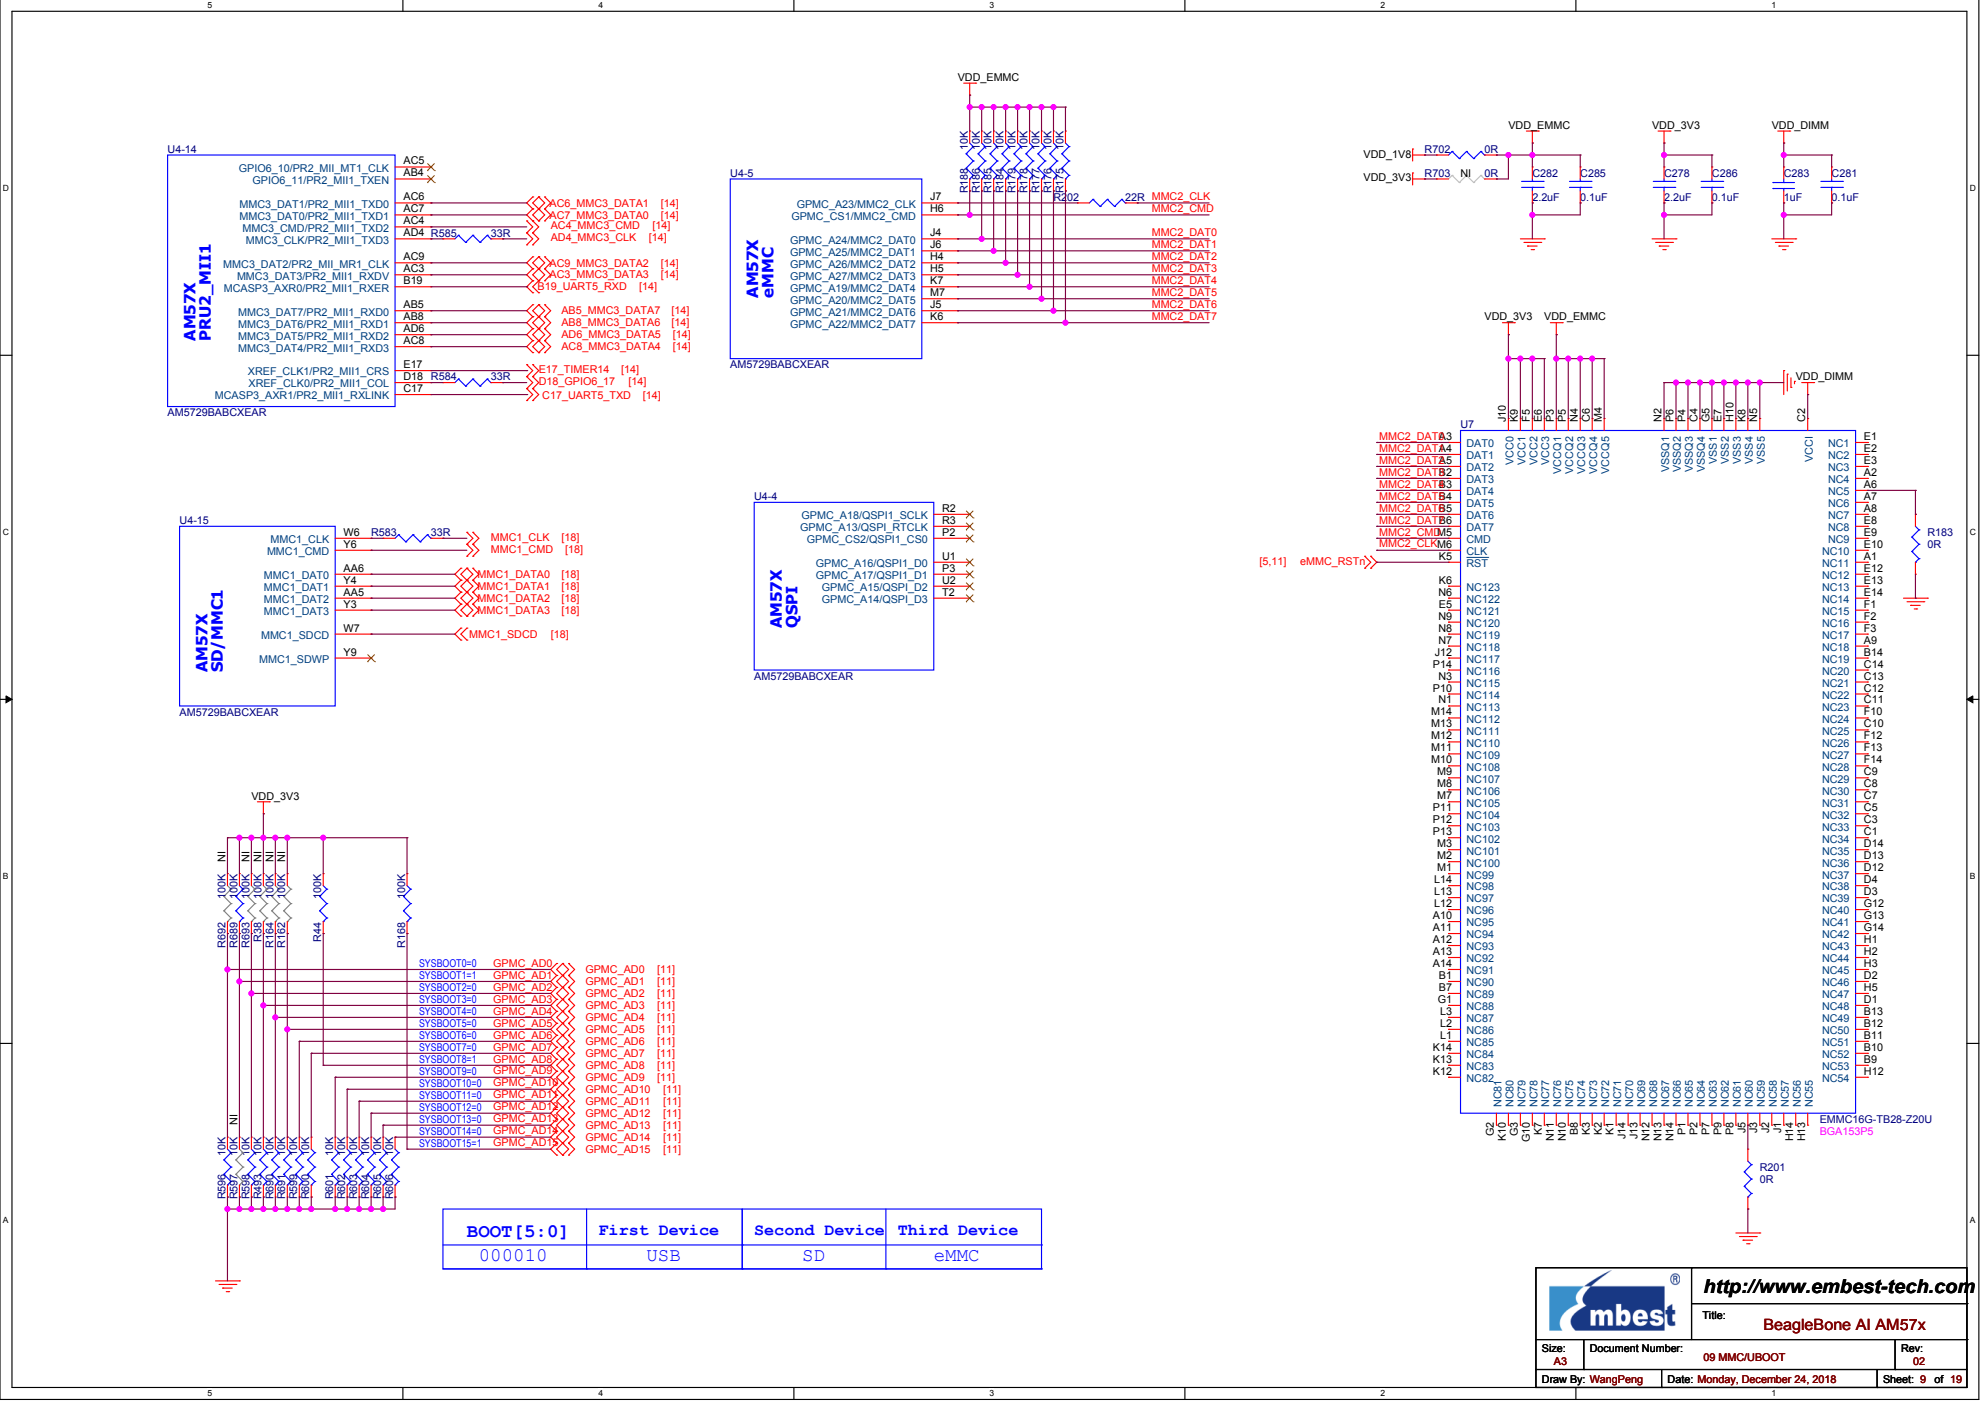
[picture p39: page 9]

http://www.embest-tech.com

D | D

### R97 R96 R92 R93 R94 R95 Should close to


USB_RX/USB_TX differential impedance:90Ω±7 %
USB3.0 (SuperSpeed) Tracelength (Total MAX on PCB):3500 mil

http://www.embest-tech.com


http://www.embest-tech.com


http://www.embest-tech.com


http://www.embest-tech.com

# Exp Connect


http://www.embest-tech.com


http://www.embest-tech.com

# ETHERNET

### R458 R459 R460 R462 R464 R466 Should close to


http://www.embest-tech.com

### STUB on TypeC_D+ or TypeC_D-no greater than 3.5 mm


USB1_DP or DM pair differential impedance:90Ω±10 %
USB1_ DP or DM pair common mode impedance:45Ω±10

Place close to interface

USB 3.0 Layout Parameters:
USB_RX or TX pair differential impedance:90Ω±7 %
USB3.0 (SuperSpeed) Tracelength (Total MAX on PCB):3500 mil

All PCMF2USB30 place close to Interface

SSRX/SSTX differential impedance:90Ω±7 %

USB2_DP or DM pair differential impedance:90Ω±10 %
USB2_ DP or DM pair common mode impedance:45Ω±10

http://www.embest-tech.com

# ADC


http://www.embest-tech.com

## CMF+ESD


http://www.embest-tech.com

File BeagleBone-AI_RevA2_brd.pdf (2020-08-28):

# ART FILM - ASSEM_TOP

# C325 C300 C286 C278


# ART FILM - ASSEM_BOT

R616



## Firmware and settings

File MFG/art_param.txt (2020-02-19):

DEVICE-TYPE           GERBER_RS274X
OUTPUT-UNITS          INCHES
FILM-SIZE             2400000 1600000
FORMAT                2.5
ABORT-ON-ERROR        NO
SCALE                 1
SUPPRESS-LEAD-ZEROES  YES
SUPPRESS-TRAIL-ZEROES NO
SUPPRESS-EQUAL        YES
UNDEF-APT-CONT        NO

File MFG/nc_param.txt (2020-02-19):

INTEGER-PLACES         2
DECIMAL-PLACES         5
X-OFFSET               0.000000
Y-OFFSET               0.000000
FEEDRATE               1
COORDINATES            ABSOLUTE
OUTPUT-UNITS           ENGLISH
TOOL-ORDER             INCREASING
REPEAT-CODES           YES
SUPPRESS-LEAD-ZEROES   NO
SUPPRESS-TRAIL-ZEROES  NO
SUPPRESS-EQUAL         NO
TOOL-SELECT            NO
OPTIMIZE_DRILLING      NO
ENHANCED_EXCELLON      NO
HEADER                 none
LEADER                 12
CODE                   ASCII
SEPARATE               NO
SEPARATE-ROUTING       NO
DRILLING               LAYER-PAIR
BACKDRILL              NO
CAVITY                 NO
COUNTER                NO
TOLERANCE_DRILL        NO
TOLERANCE_TRAVEL       NO
TOOL_SIZE              NO
ROTATION               NO
NON_STANDARD           NO
TOTAL_DRILL            NO
SEPARATE_SLOT          NO
SUPPRESS_TOLERANCE     NO
SUPPRESS_TOOLSIZE      NO
SUPPRESS_ROTATION      NO

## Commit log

2019-06-17 Remove local device tree tree
2019-06-17 Add device tree submodule
2019-06-18 firmware: brcm: mainline brcmfmac allows you to specify a device specific firmware based on the dts compatible flag
2019-08-26 Added Fritzing AI part and diagram
    [templateAI.fzz]
2019-09-03 Added rev A1 design files
    [BeagleBone-AI_bom.xls]
2019-09-03 BOM: replace XLS with CSV
    [BeagleBone-AI_bom.csv, BeagleBone-AI_bom.xls]
2019-10-24 SW: u-boot: pinmux: for review before sending upstream
    NOTE: for the actual submission, I will disable the UART TX
    and EHRPWM pins, but leave the iodelay setup for them to avoid
    doing any damage to capes that might not use these modes.
    [PinmuxConfigSummary.csv]
2019-10-27 SW: u-boot: pinmux: update based on review
    * Disable all UART TX pins (switch to GPIO)
    * Disable SPI3 (switch to GPIO)
    * Disable eHRPWMs (switch to GPIO)
    * Match power-on pull-up/down status where possible
    * Enable GPIOs on alternate pins (ie., other shorted pin is PRU input, UART RX, eQEP, etc.)
    * Enable GPIOs for all pins not otherwise enabled
    * On eQEP shorted pins, pull-down on eQEP and no-pull on GPIO
    * On UART/PRU shorted pins, pull-down on GPIO and no-pull on UART/PRU
    * Add pull-downs on UART-only pins (console)
    * Correct voltages for vddshv1 and vddshv7 (3.3V)
    [PinmuxConfigSummary.csv]
2019-10-27 SW: u-boot: pinmux: add pull-ups on I2C4
    [PinmuxConfigSummary.csv]
2020-02-19 MFG: add untested files
    [art_param.txt, nc_param.txt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]
2020-08-27 Add RevA2 documentation
    1) Origin design file
    2) PCB components location
    3) BOM
    [BeagleBone-AI_RevA2_BOM+DNP.xlsx]
2021-01-29 Import A1 version Board into KiCad
    Translate schematics and tweak rule sets in KiCad to match output.
    [adc.kicad_sch, am572system.kicad_sch, beaglebone-ai.kicad_sch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]
2021-02-03 Add BeagleBone rev2 KiCad translation
    [adc.kicad_sch, am572system.kicad_sch, beaglebone-ai-rev-a2.kicad_sch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]
2024-01-15 Fix board page link
